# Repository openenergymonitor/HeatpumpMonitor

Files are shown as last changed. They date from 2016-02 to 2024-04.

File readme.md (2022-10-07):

# Heatpump Monitor

This is a technical github repository for OpenEnergyMonitor open hardware and software heat-pump performance monitoring development.

## Rationale

Heat-pumps are a key component of zero carbon energy systems making it possible to provide heating efficiently from renewable energy, they are featured in many zero carbon energy scenarios such as ZeroCarbonBritain developed by the Centre for Alternative Technology and are also highlighted in David MacKay's book Sustainable Energy without the hot air.

By monitoring a heat-pump its possible to see how well it is working, diagnose problems and get a better understanding of how a key potentially zero carbon heating solution works, data gathered and shared from well performing systems could help de-mystify heat-pump operation and help improve performance by diagnosing any problems early.

## Getting started

The heat pump monitoring application guide in the main OpenEnergyMonitor guide is a good place to start, covering the different options, including the use of the main OpenEnergyMonitor hardware:

[https://guide.openenergymonitor.org/applications/heatpump](https://guide.openenergymonitor.org/applications/heatpump)

## Hardware

### EmonPi or EmonTx based heat pump monitor

<table>
<tr><td>
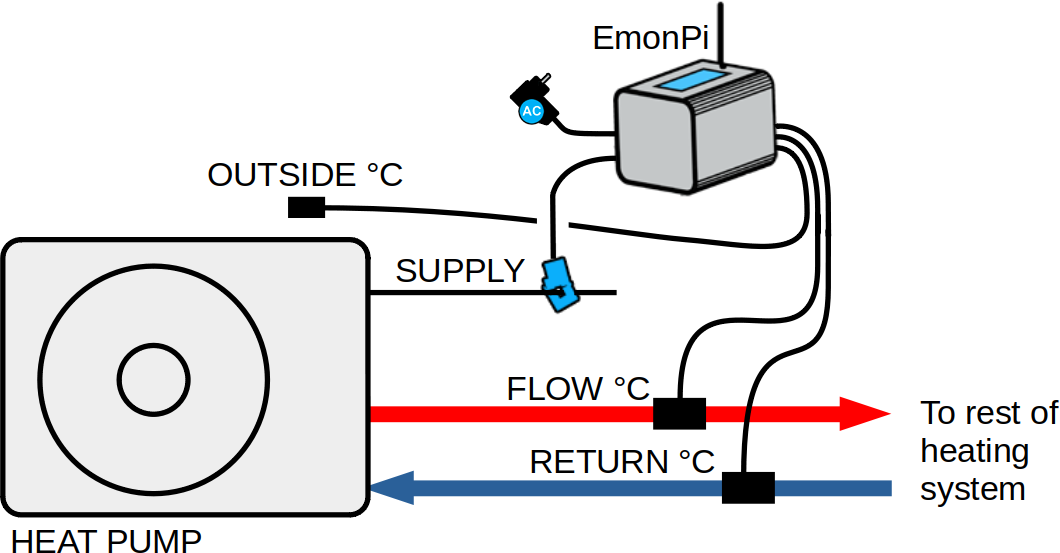
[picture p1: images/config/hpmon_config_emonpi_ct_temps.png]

</td><td>
<b>Electricity consumption and system temperatures</b><br>
<p>Monitor electricity consumption and system temperatures using clip-on CT sensors and one-wire temperature sensors connected to an emonPi or emonTx. This provides the simplest solution for installation on existing systems. See <a href="https://guide.openenergymonitor.org/applications/heatpump">main guide for details</a>.</p>
</td>
</tr>
<tr><td>
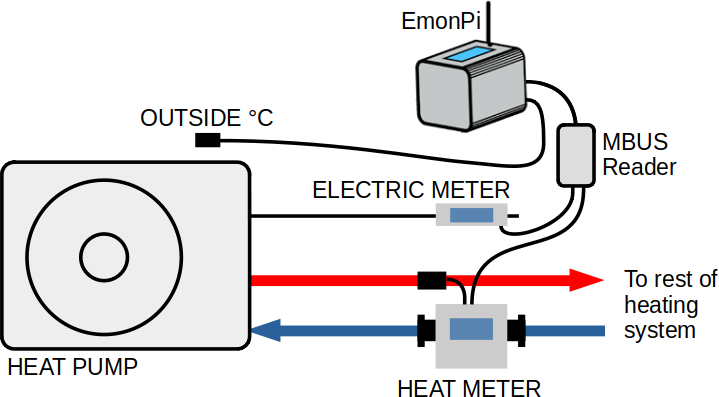
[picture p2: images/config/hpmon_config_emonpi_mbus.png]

</td><td>
<b>Using external MBUS reader module</b><br>
<p>An external MBUS reader connected to the emonPi or emonBase can be used to read from high accuracy electricity and heat meters. See <a href="https://guide.openenergymonitor.org/applications/heatpump">main guide for details</a>.</p>
</td>
</tr>
</table>

### [New: RaspberryPi & MBUS based heat pump monitor](HeatpumpMonitorPi)

<table>
<tr><td>
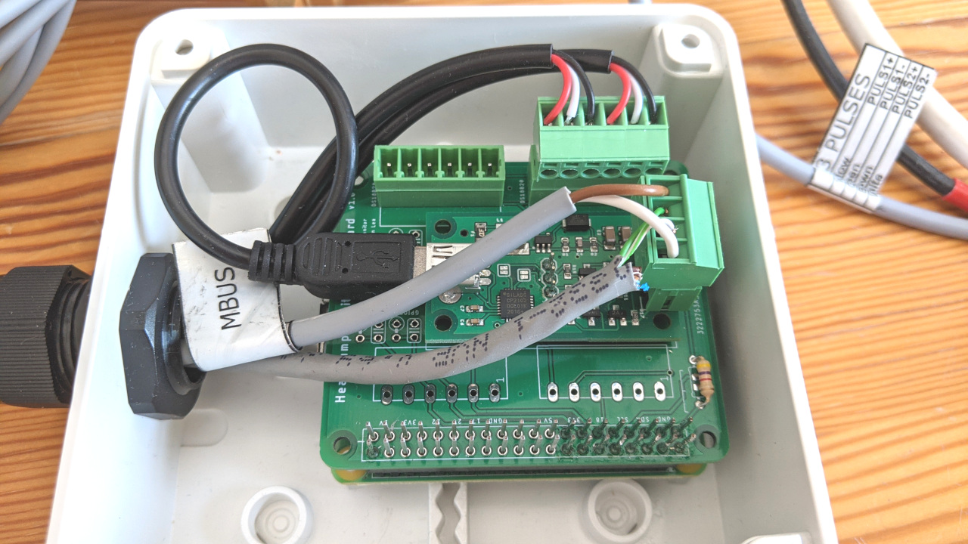
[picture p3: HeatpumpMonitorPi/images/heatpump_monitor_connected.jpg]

</td><td>
<p>This is a new heat pump monitor board designed specifically for interfacing with MID standard electricity and heat meters via MBUS. It has a RaspberryPi at it’s core running our emonSD image enabling local or/and remote logging and data visualisation.</p>
</td>
</tr>
</table>

### [Original through-hole heat pump monitor](HeatpumpMonitorTH)

<table>
<tr><td>
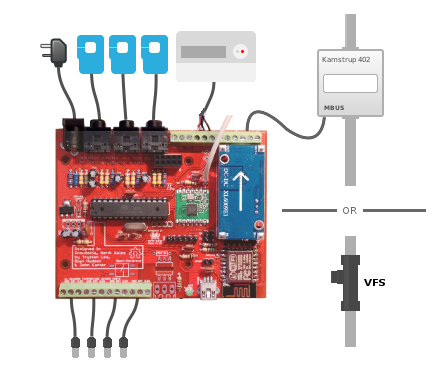
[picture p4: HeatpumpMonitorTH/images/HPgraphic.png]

</td><td>
<b>Main Features:</b><br>
<ul>
<li>CT current and ACAC voltage based electricity monitoring</li>
<li>Pulse counting or IRDA Elster meter reader</li>
<li>Analog inputs for Vortex Flow Sensor (VFS) option (e.g Sika, Grundfos)</li>
<li>MBUS reader for kamstrup heat meters (402, 403)</li>
<li>4x individually broken out DS18B20 temperature sensor connections</li>
<li>Arduino ATmega328 core</li>
<li>Connectivity options: ESP-12 WIFI, RaspberryPI header, RFM69</li>
</ul>
</td>
</tr>
</table>

### Mini Boards

**USB to MBUS**

- [USB to MBUS v1 SMT](https://github.com/openenergymonitor/HeatpumpMonitor/tree/master/USB_MBUS_Reader)

**WiFi MBUS Reader**

- [WiFi MBUS Reader v1 (Through-hole)](https://github.com/openenergymonitor/HeatpumpMonitor/tree/master/Hardware/WiFi_MBUS_Reader/v1_TH)
- [WiFi MBUS Reader v1 SMT](https://github.com/openenergymonitor/HeatpumpMonitor/tree/master/Hardware/WiFi_MBUS_Reader/v1)

## Heat pump monitoring dashboard

Emoncms includes an application specific heat pump dashboard available in the Apps module. The following video gives a good overview of what this dashboard can do, how to access daily electricity consumption and heat output data as well as detailed system temperature and power data.

There's also a little feature shown briefly at the end that simulates the heat output and COP of the heat pump based on the Carnot COP equation.

[YouTube: Introduction to the Emoncms heat pump dashboard](https://www.youtube.com/watch?v=jBY1Sx3LR2o)

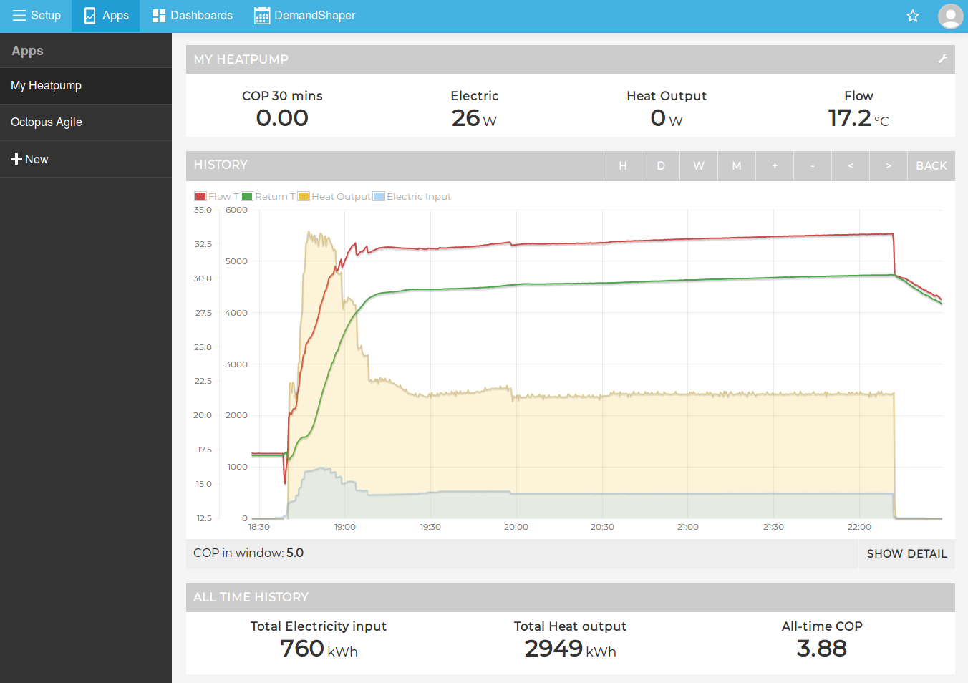
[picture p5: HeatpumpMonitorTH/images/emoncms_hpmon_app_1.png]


It's also worth checking out David Bowen (@MyForest on the forum's) heat pump app, see forum post: [Heat Pump Experimentation App - Release News](https://community.openenergymonitor.org/t/heat-pump-experimentation-app-release-news/13423).

The My Heatpump app includes a feature to simulate the COP and heat output of a heat pump from the flow temperature, outside temperature and electrical power input. The equations used are documented here: https://github.com/emoncms/dynamic/blob/master/docs/heatpumpmodel.md

## Blogs and further reading

- **Blog post:** [Heatpumps in the ZeroCarbonBritain model by the Centre for Alternative Technology.](https://blog.openenergymonitor.org/2015/12/heatpumps-in-zerocarbonbritain-model-by)
- **Blog post:** [Heat pump Testing: Initial results](https://blog.openenergymonitor.org/2016/02/heat-pump-testing-initial-results)
- **[John Cantor's heat pump monitoring blog](https://heatpumps.co.uk/technical/energy-monitoring)**

## Licence

This project is open source software and hardware.

The Arduino firmware is available under the GPL v3 Licence. 

The Web Dashboard is available under the GNU Affero General Public License and is based on emoncms.

The hardware design (schematics, board files and gerber) files are licensed under the [Creative Commons Attribution-ShareAlike 3.0 Unported License](http://creativecommons.org/licenses/by-sa/3.0/) and follow the terms of the [OSHW (Open-source hardware) Statement of Principles 1.0.](http://freedomdefined.org/OSHW)

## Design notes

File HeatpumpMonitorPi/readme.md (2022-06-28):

## RaspberryPi, MBUS & Modbus based heat pump monitor

This is a new heat pump monitor board designed specifically for interfacing with MID standard electricity and heat meters via MBUS or/and Modbus. It has a RaspberryPi at it’s core running our emonSD image enabling local or/and remote logging and data visualisation.

It is designed for monitoring heat pump electricity consumption, heat output and system temperatures for detailed performance analysis & troubleshooting.

### Features

- MBUS Reader (Reads from heat meters and some electric meters, though the SDM120-MBUS is no longer recommended)
- A Modbus Reader is recommended for reading from SDM120-Modbus electricity meters
- DS18B20 Temperature sensor connections
- 6 Digital input or outputs can be used for pulse counting
- I2C connection (uses 2 of the 6 digital IO's)
- RaspberryPi running the OpenEnergyMonitor emonSD image

This hardware design combines in a single unit a: 

- RaspberryPi
- [Heat pump monitoring baseboard](baseboard)
- [USB to MBUS reader](../USB_MBUS_Reader)

### Selecting a heat meter

Please read our guide on selecting the right heat meter here:<br>https://github.com/openenergymonitor/HeatpumpMonitor/blob/master/selectingheatmeter.md

### Connection diagram

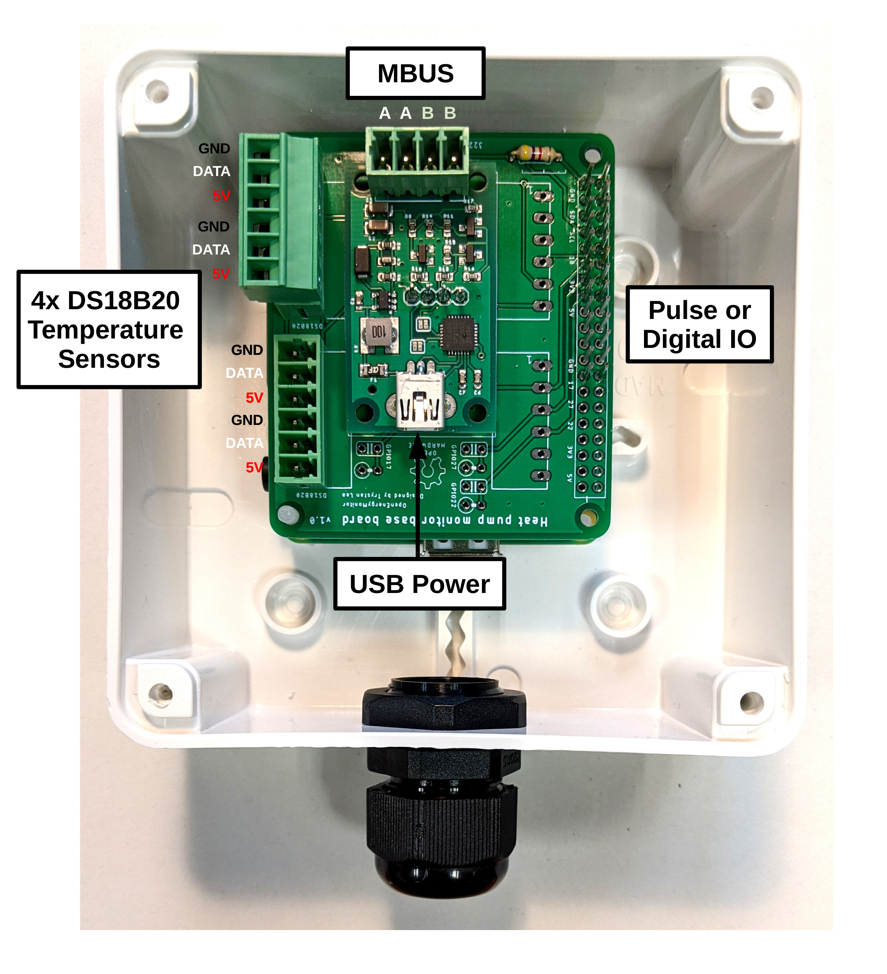
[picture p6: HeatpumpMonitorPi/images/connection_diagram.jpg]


### Setup

The following setup instructions assume an assembled heat pump monitor kit as shown in the picture above, with pre-prepared SD card running the standard emonSD image inserted into the RaspberryPi **(with SSH enabled, see [Guide: Credentials](https://guide.openenergymonitor.org/technical/credentials/))**.

1. Use the connection diagram above to connect MBUS meters, temperature sensors and power. There are two A and B MBUS terminals that can be used to simplify connecting two meters to the MBUS reader. Make sure that the power supply is capable of supplying 2A e.g [OpenEnergyMonitor Shop 5V USB Power Adapter](https://shop.openenergymonitor.com/5v-dc-usb-power-adapter-uk-plug) (MBUS data corruption can occur if the power supply output is too low).

2. Power up the unit, wait a couple of minutes for the Pi to create a WiFi access point. Connect to the access point and then use the WiFi configuration interface to connect the unit to your home WiFi. See [Guide: Connect](https://guide.openenergymonitor.org/setup/connect/) for full details.

3. If you have connected DS18B20 temperature sensors a couple of minor steps are required to enable reading from DS18B20 temperature sensors on the Pi. Follow steps 1 to 4 here [EmonHub Interfacers: Direct DS18B20 temperature sensing](https://guide.openenergymonitor.org/integrations/emonhub-interfacers/#direct-ds18b20-temperature-sensing).

4. EmonHub is piece of software running on the Pi that reads from the connected MBUS meters and DS18B20 temperature sensors. It then forwards the data to a seperate piece of software called Emoncms for data storage and visualisation. EmonHub is configured using a configuration file located at: /etc/emonhub/emonhub.conf. A configuration example is included at the bottom of this page for reading from a SDM120-MBUS electricity meter, a Qalcosonic E3 heat meter and DS18B20 temperature sensors. Overwrite the existing default configuration with this configuration as it is a better starting point for our requirements.

5. Configure EmonHub MBUS settings. The default MBUS configuration settings below assumes that a suitable heat meter is connected on address 1. You may need to adjust the MBUS address of either of the meters to ensure that they are not both on the same address. See instructions in the forum post here on how to do this: https://community.openenergymonitor.org/t/reading-from-multiple-mbus-meters-with-the-emonhub-mbus-interfacer/18159

6. Example configuration with a Sontex 531 heat meter:

```
[[MBUS]]
    Type = EmonHubMBUSInterfacer
    [[[init_settings]]]
        device = /dev/ttyAMA0
        baud = 2400
    [[[runtimesettings]]]
        pubchannels = ToEmonCMS,
        read_interval = 10
        validate_checksum = False
        nodename = mbus
        [[[[meters]]]]
            [[[[[sontex]]]]]
                address = 1
                type = sontex531
```

7. With the hardware connected up and the settings in place, data should now be coming in and be listed as inputs in Emoncms.

### Using the EmonHub log to debug issues reading data from the meters

...

### Configuring Emoncms

...

### Example test setup

Reading from a SDM120-MBUS electricity meter and a Qalcosonic E3 heat meter. These, or similar meters would usually be installed as part of heat pump installation. 

**Note:** The SDM120-MBUS electricity meter is no longer recommended due to reliability issues. We now recommend to use a SDM120-Modbus meter with a seperate Modbus reader. See forum post: [https://community.openenergymonitor.org/t/sdm120-mbus-meter-freezing-drop-out/20765/2](https://community.openenergymonitor.org/t/sdm120-mbus-meter-freezing-drop-out/20765/2)

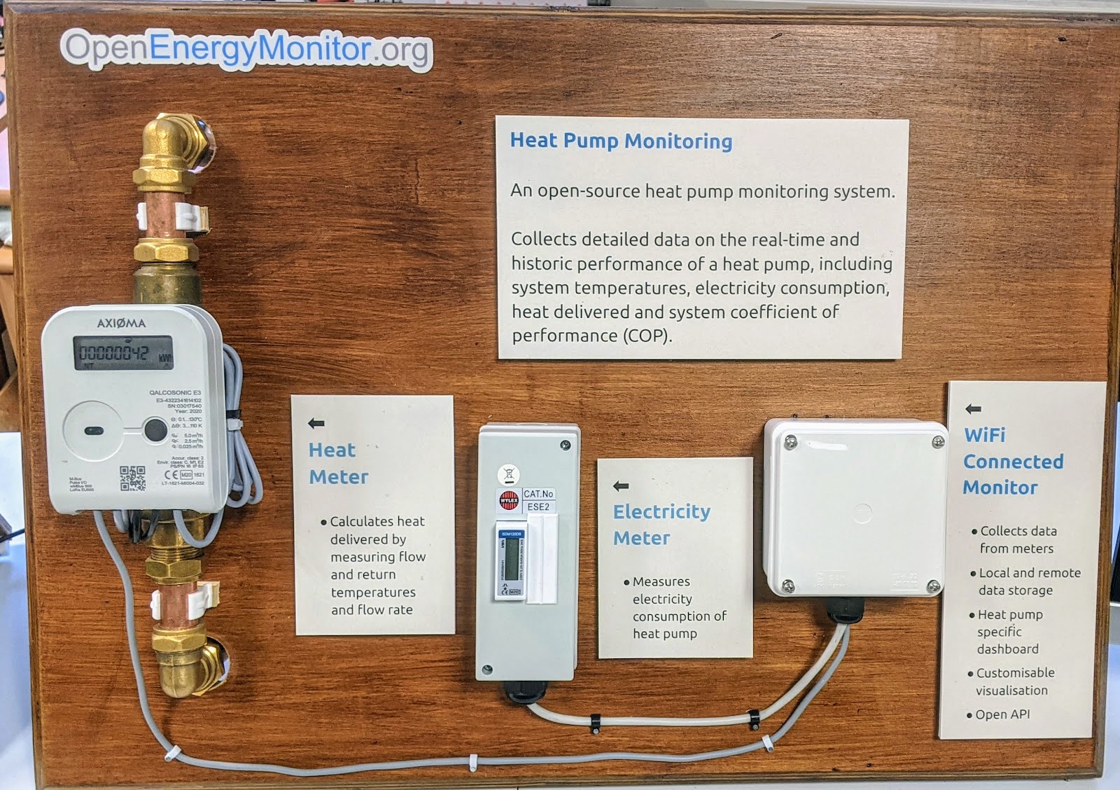
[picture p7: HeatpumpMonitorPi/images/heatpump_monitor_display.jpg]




### Example EmonHub Configuration

The following is a full */etc/emonhub/emonhub.conf* example that reads from any connected DS18B20 temperature sensors, a Sontex Superstatic 440 heat meter with Multical 531 integrator on MBUS and a SDM120-Modbus electricity meter. Data is forwarded to the local emoncms installation using MQTT and the remote emoncms installation via HTTP.

```
[hub]
loglevel = DEBUG

[interfacers]

[[DS18B20]]
    Type = EmonHubDS18B20Interfacer
    [[[init_settings]]]
    [[[runtimesettings]]]
        pubchannels = ToEmonCMS,
        read_interval = 10
        nodename = temperatures

[[MBUS]]
    Type = EmonHubMBUSInterfacer
    [[[init_settings]]]
        device = /dev/ttyAMA0
        baud = 2400
    [[[runtimesettings]]]
        pubchannels = ToEmonCMS,
        read_interval = 10
        validate_checksum = False
        nodename = mbus
        [[[[meters]]]]
            [[[[[sontex]]]]]
                address = 1
                type = sontex531

[[SDM120]]
    Type = EmonHubSDM120Interfacer
    [[[init_settings]]]
        device = /dev/ttyUSB0
        baud = 2400
    [[[runtimesettings]]]
        pubchannels = ToEmonCMS,
        read_interval = 10
        nodename = SDM120

[[MQTT]]
    Type = EmonHubMqttInterfacer
    [[[init_settings]]]
        mqtt_host = 127.0.0.1
        mqtt_port = 1883
        mqtt_user = emonpi
        mqtt_passwd = emonpimqtt2016

    [[[runtimesettings]]]
        pubchannels = ToRFM12,
        subchannels = ToEmonCMS,
        nodevar_format_enable = 1
        nodevar_format_basetopic = emon/

[[emoncmsorg]]
    Type = EmonHubEmoncmsHTTPInterfacer
    [[[init_settings]]]
    [[[runtimesettings]]]
        pubchannels = ToRFM12,
        subchannels = ToEmonCMS,
        url = https://emoncms.org
        apikey = xxxxxxxxxxxxxxxxxxxxxxxxxxxxxxxx
        senddata = 1
        sendstatus = 1
        sendinterval= 30

[nodes]
```

**Forum post: Reading from multiple MBUS meters with the EmonHub MBUS interfacer**<br>
https://community.openenergymonitor.org/t/reading-from-multiple-mbus-meters-with-the-emonhub-mbus-interfacer/18159

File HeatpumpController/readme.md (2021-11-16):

# Heatpump Controller v1

An initial board design for a heat pump controller, designed for use with a Mitsubishi EcoDan with a FTC2b controller.

This board sits on top of a RaspberryPi and the very basic at this stage python scripting that runs on it can be found here: https://github.com/TrystanLea/heatpump_control

**Features:**

- 6x solid state relay outputs either PVT312, PVT412 or LH1546. Most of these are used to switch the volts free inputs on the FTC2b, e.g heating on, DHW mode etc.
- The PVT412 can drive up to 120mA AC which is 27.6W, can directly control a couple of AC low power solenoids/valves.
- 4x DS18B20 temperature sensor connections for cylinder and outside temperature sensors
- 0-5V voltage output to set EcoDan flow temperature
- A connection for the MBUS reader module here [USB_to_MBUS](https://github.com/openenergymonitor/HeatpumpMonitor/tree/master/Hardware/USB_to_MBUS) to read from heat meters. Later version could integrate this on the board.
- The Pi can connect via an modbus reader to a SDM120 single phase electricity meter, see [OEM Guide](https://guide.openenergymonitor.org/integrations/emonhub-interfacers/#reading-from-a-sdm120-single-phase-meter)

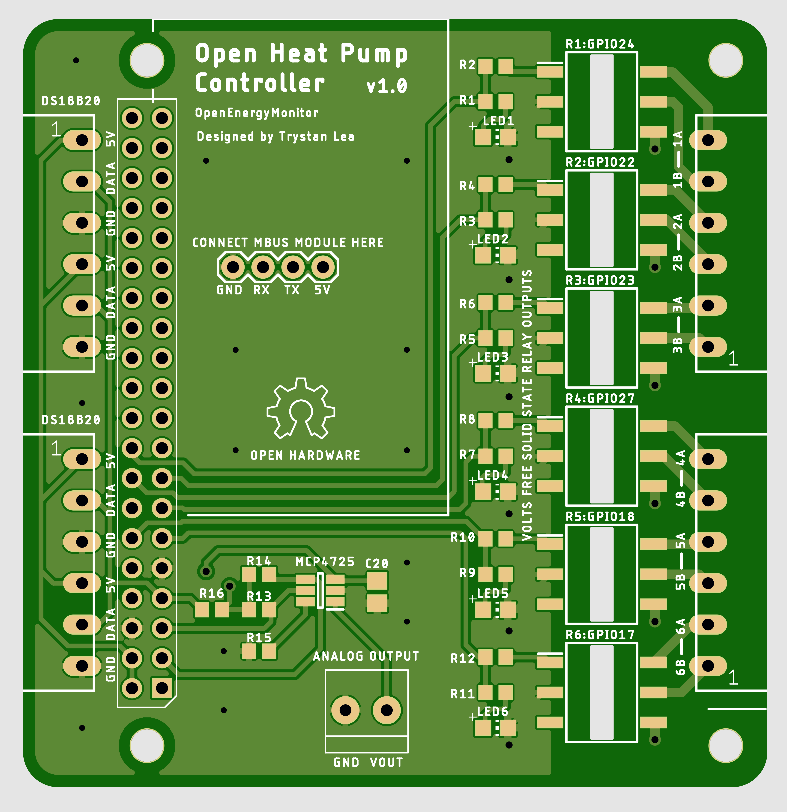
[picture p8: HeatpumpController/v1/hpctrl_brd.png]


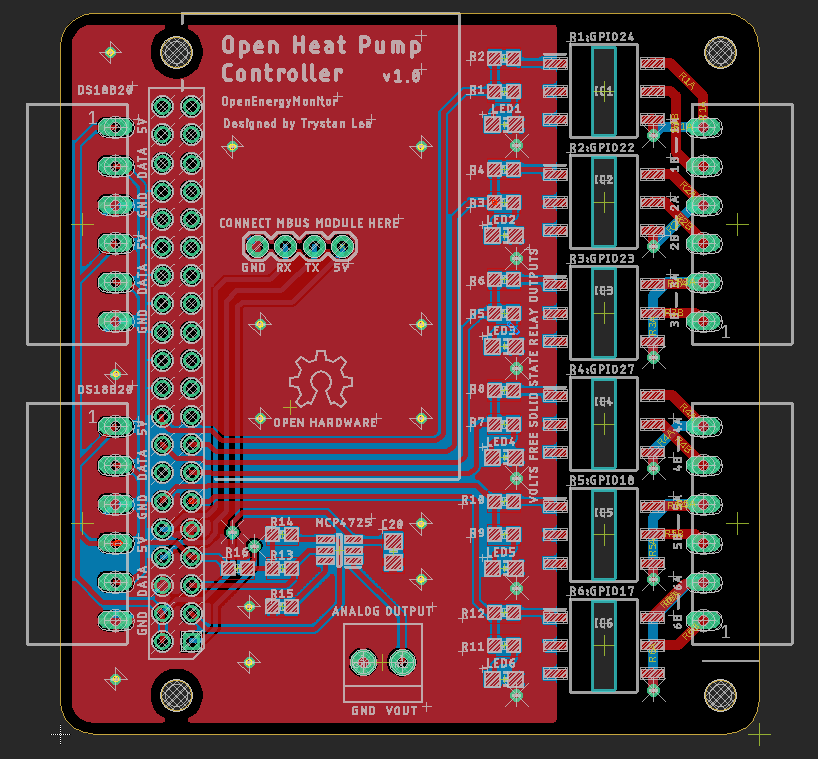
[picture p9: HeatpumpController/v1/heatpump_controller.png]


## Alternative approach (better?)

It looks like it is possible to issue commands directly via the CN105 connector on most Mitsubushi EcoDan controllers, which looks like a better and much cheaper approach than the above. Will be trying this myself soon:

- https://github.com/SwiCago/HeatPump
- https://www.geekzone.co.nz/forums.asp?forumid=73&topicid=265469
- https://web.archive.org/web/20171007190023/https://nicegear.co.nz/blog/hacking-a-mitsubishi-heat-pump-air-conditioner/
- https://gitter.im/Mitsubishi-CN105-Protocol-Decode/community
- https://github.com/m000c400/Mitsubishi-CN105-Protocol-Decode
- https://github.com/BartGijsbers/CN105Gateway
- https://www.zakon.org/robert/projects/MiniSplitPi/

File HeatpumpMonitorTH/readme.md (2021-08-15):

# The Original Through-hole Heatpump Monitor

This directory contains all the documentation, hardware schematics, board files and firmware for the original OpenEnergyMonitor through-hole heat pump monitor, developed between 2015-2017.

This is a web-connected open source hardware heat-pump monitor that can measure heat-pump electrical input with CT sensors, heat output with an MBUS reader or voltage output flow sensor and system temperatures using DS18B20 temperature sensors. The design is based on both the Ardunio and ESP8266 WiFi platforms.

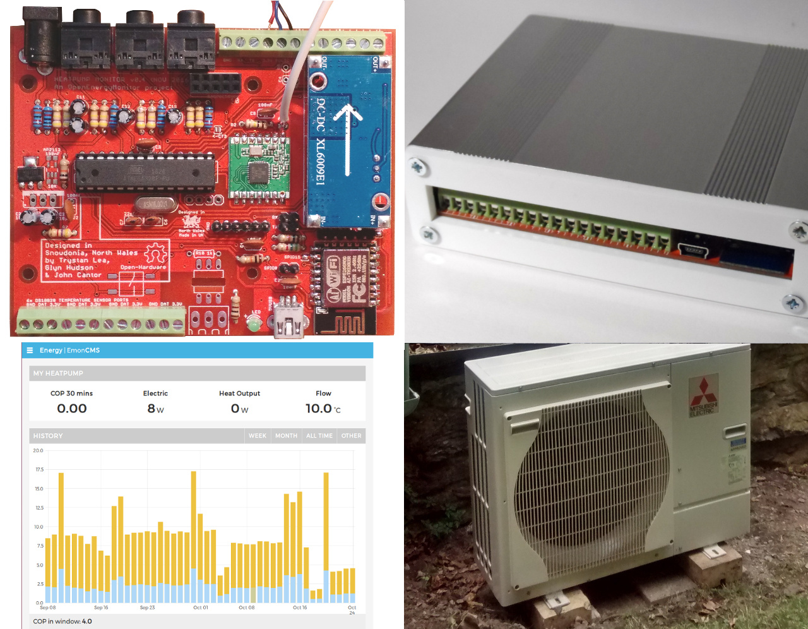
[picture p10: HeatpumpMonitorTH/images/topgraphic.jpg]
Heatpump monitor


Blog post written late 2015 discussing this design: [Heat pump Monitoring](https://blog.openenergymonitor.org/2015/12/heat-pump-monitoring)

## Available in the OpenEnergyMonitor Shop

The last set of through-hole kits are still available in our shop as of the time of writting (late 2021).

[https://shop.openenergymonitor.com/esp8266-wifi-heatpump-monitor](https://shop.openenergymonitor.com/esp8266-wifi-heatpump-monitor)

## Overview

<table>
<tr><td>

</td><td>
<b>Main Features:</b><br>
<ul>
<li>CT current and ACAC voltage based electricity monitoring</li>
<li>Pulse counting or IRDA Elster meter reader</li>
<li>Analog inputs for Vortex Flow Sensor (VFS) option (e.g Sika, Grundfos)</li>
<li>MBUS reader for kamstrup heat meters (402, 403)</li>
<li>4x individually broken out DS18B20 temperature sensor connections</li>
<li>Arduino ATmega328 core</li>
<li>Connectivity options: ESP-12 WIFI, RaspberryPI header, RFM69</li>
</ul>
</td>
</tr>
</table>

## Build Guides

There are two build options for the heatpump monitor board, the first is the full heatpump monitor build with components for the MBUS heat meter reader, DS18B20 temperature sensing plus other interfaces. The second is a cut-down WIFI electricity monitor only build where the additional components for heat metering are not soldered in.

- [Heatpump monitor kit build guide](heatpumpmonitor_build.md)
- [Cut down energy monitor kit build guide](energymonitor_build.md)

**Quick reference**

- [ATmega328 Arduino Firmware: HeatpumpMonitor_AutoTemp](https://github.com/openenergymonitor/HeatpumpMonitor/blob/master/HeatpumpMonitorTH/Firmware/Arduino/HeatpumpMonitor_AutoTemp)
- [ESP8266 EmonESP WIFI Firmware](https://github.com/openenergymonitor/EmonESP)
- [Hardware Schematic and Board files v4](https://github.com/openenergymonitor/HeatpumpMonitor/tree/master/HeatpumpMonitorTH/Hardware/v4)

## Installation and setup

The following guide details how to setup the heatpump monitor including interfacting with an Elster A100C Irda port and connecting up to a heat meter.

- [Selecting the right heat meter](../selectingheatmeter.md)
- [Installation and setup](installation.md)
- [Blog: Temperature sensors for monitoring heat pumps](http://johncantorheatpumps.blogspot.co.uk/2015/06/temperature-sensing-with.html)
- [Firmware Upload / Update](firmware-upload.md)

## Open Hardware ++

A case study in open hardware development

- Exporting gerbers from EAGLE, getting a PCB made with a PCB manufacturer such as Ragworm
- [Heatpump Monitor and cut down energy monitor kit costing](costingexample.md)

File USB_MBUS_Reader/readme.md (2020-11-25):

# USB to MBUS

A simple USB MBUS reader with on-board boost converter and CP2102 USB to UART chip. Designed for reading data from heat pump heat meters and interfacing directly with a RaspberryPi via a USB cable.

**Features**

- MBUS Reader circuit (original circuit by [Tomas Menzi](https://github.com/rscada/libmbus/tree/master/hardware))
- On-board boost converter (based on [Taaralabs](https://taaralabs.eu/m-bus-uart-converter/))
- CP2102 USB to UART chip

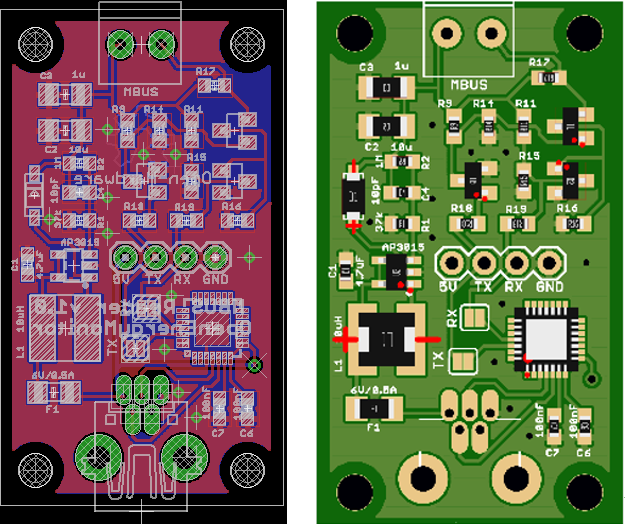
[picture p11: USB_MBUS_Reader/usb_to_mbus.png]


**Software**

The board can be used with the EmonHub MBUS Interfacer. This interfacer is designed to look for specific useful parameters for electric and heat metering (It does not implement the full MBUS spec). It will typically return flow and return temperatures, flow rate, heat output, and cumulative heat energy for heat meters that support these parameters.

https://guide.openenergymonitor.org/integrations/emonhub-interfacers/#mbus-reader-for-electric-and-heat-meters

## Schematic

[USB_to_MBUS.sch](USB_to_MBUS.sch)

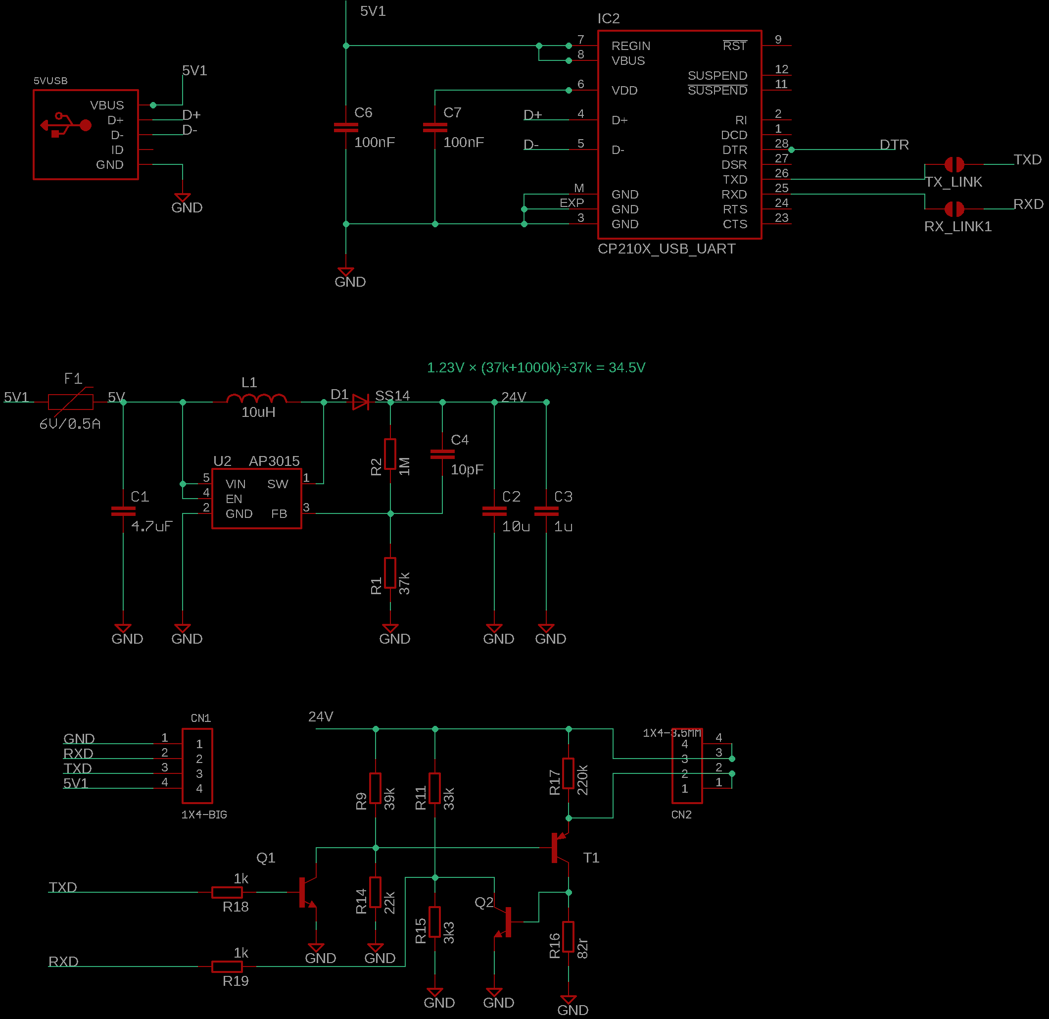
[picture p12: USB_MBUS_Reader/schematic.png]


## Board

[USB_to_MBUS.brd](USB_to_MBUS.brd)

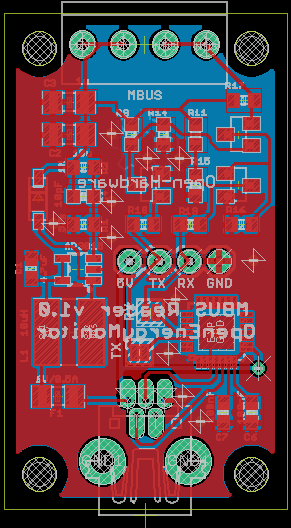
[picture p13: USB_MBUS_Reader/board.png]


The hardware design (schematics, board files and gerber) files are licensed under the [Creative Commons Attribution-ShareAlike 3.0 Unported License](http://creativecommons.org/licenses/by-sa/3.0/) and follow the terms of the [OSHW (Open-source hardware) Statement of Principles 1.0.](http://freedomdefined.org/OSHW)

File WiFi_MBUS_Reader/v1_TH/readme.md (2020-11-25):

# WiFi MBUS Reader Through-Hole

A simple MBUS reader development board with optional WiFi based on ESP8266. Designed for reading data from heat pump heat meters and either interfacing directly with a RaspberryPi via UART or via WiFi if the ESP8266 is soldered on.

This board is a through-hole version of WiFi_MBUS_Reader/v1 for easier hand assembly and initial development testing.

**Features**

- MBUS Reader circuit, requires external boost converter
- MBUS to UART mode without ESP8266 attached.
- MBUS to WiFi mode with ESP8266 attached.
- With ESP8266: Pulse counting & potentially reading from Elster A100c IrDa output
- With ESP8266: DS18B20 temperature sensing 

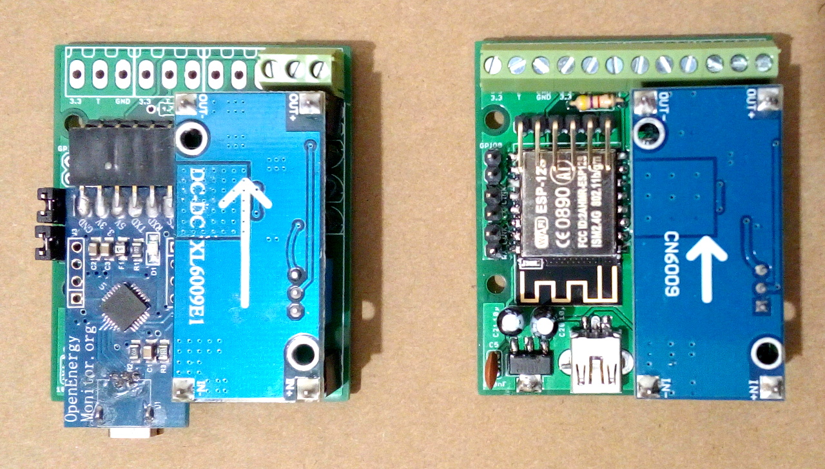
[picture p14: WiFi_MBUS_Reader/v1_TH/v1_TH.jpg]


**Software**

If used in **MBUS to UART mode**, the board can be used with the EmonHub MBUS Interfacer. This interfacer is designed to look for specific useful parameters for electric and heat metering (It does not implement the full MBUS spec). It will typically return flow and return temperatures, flow rate, heat output, and cumulative heat energy for heat meters that support these parameters.

https://guide.openenergymonitor.org/integrations/emonhub-interfacers/#mbus-reader-for-electric-and-heat-meters

The software for the **MBUS to WiFi mode** has not been written in full yet. A basic MBUS Reader firmware tested to work on this board is available here for anyone keen to get stuck in before I get this done: https://github.com/openenergymonitor/HeatpumpMonitor/tree/master/Firmware/Arduino/MBUS_Reader_ESP 

## Schematic

[v1_TH.brd](v1_TH.brd)

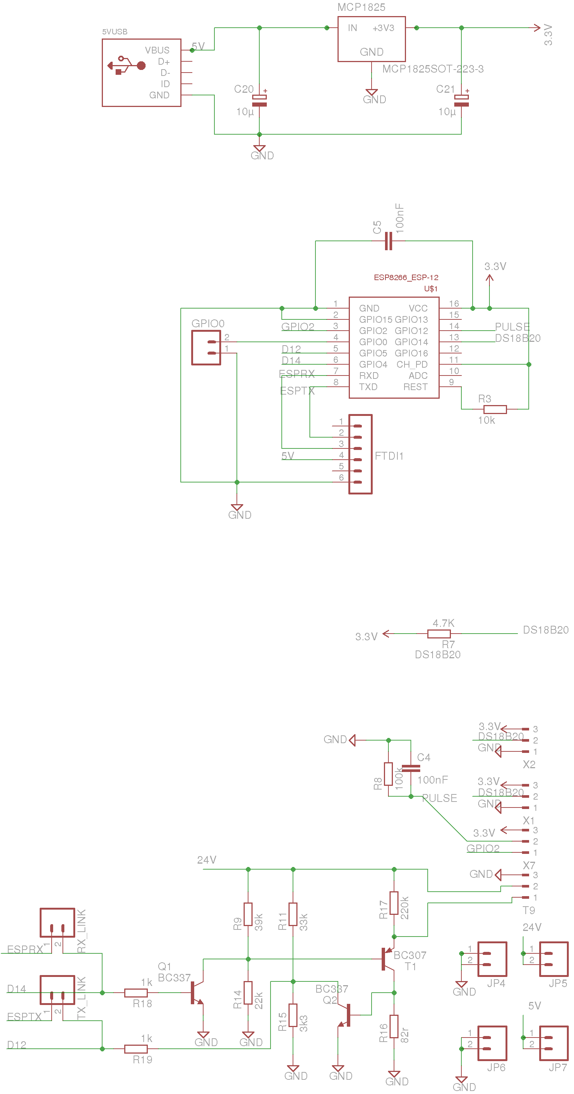
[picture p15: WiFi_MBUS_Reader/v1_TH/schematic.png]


## Board

[v1_TH.sch](v1_TH.sch)

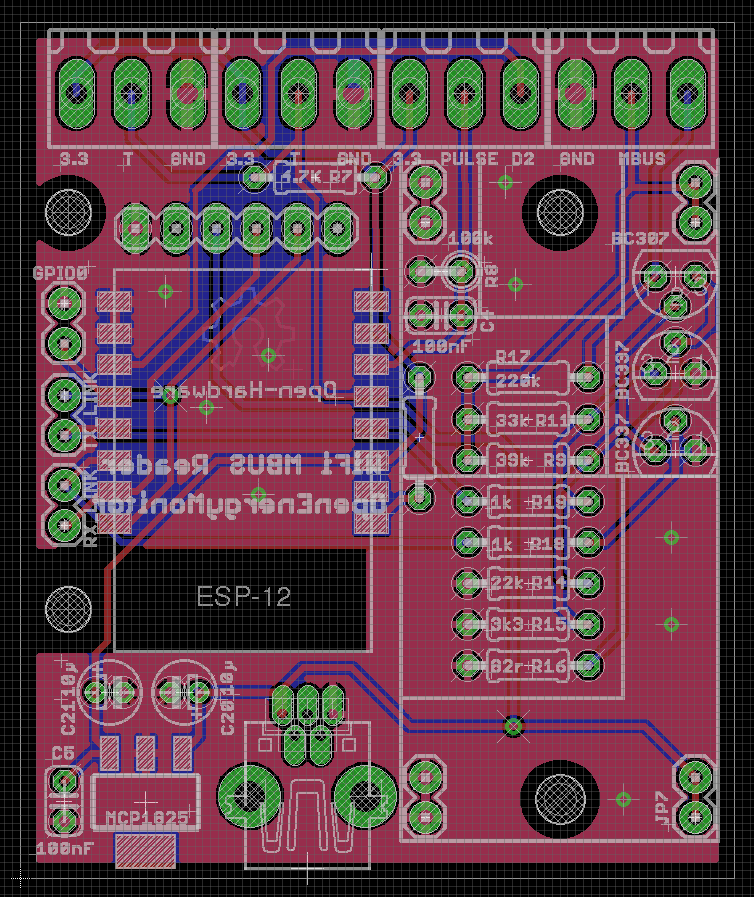
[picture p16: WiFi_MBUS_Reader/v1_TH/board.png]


The hardware design (schematics, board files and gerber) files are licensed under the [Creative Commons Attribution-ShareAlike 3.0 Unported License](http://creativecommons.org/licenses/by-sa/3.0/) and follow the terms of the [OSHW (Open-source hardware) Statement of Principles 1.0.](http://freedomdefined.org/OSHW)

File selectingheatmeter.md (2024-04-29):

# Selecting the right heat meter

There are a number of different heat meter brands and models available that are both MID and RHI (UK Renewable Heat Incentive) approved. If you are in the UK, Stockshed provide a good range of these meters: [https://stockshed.com/pages/heat-meters-stockshed-uk](https://stockshed.com/pages/heat-meters-stockshed-uk).

Most heat meters include an MBUS interface that can be used for reading the metering data. This usually includes, total heat delivered in kWh, real-time heating power in Watts, flow and return temperatures and flow rate in L/min of m3/hr. 

Using an MBUS reader connected to an emonPi, emonBase or just a Raspberry Pi, it is possible to read in this data and then store and visualise it using emoncms. Combined with electricity data, this can provide a data rich, detailed view of the performance of a heat pump.

So far, we have only tested our MBUS reader software with a subset of the following meters but they should all be compatible, if not out of the box, with a little modification of the code. Please email me at trystanlea @ openenergymonitor.org if you are having trouble reading from a particular MBUS meter.

**Important:** We recommend using meter's with an AC power supply option as most battery powered options are not designed for requesting MBUS data at 10s frequency and so battery life may be much shorter than otherwise advertised. 

### [Kamstrup MULTICAL 403](https://www.kamstrup.com/en-en/heat-solutions/meters-devices/meters/multical-403)

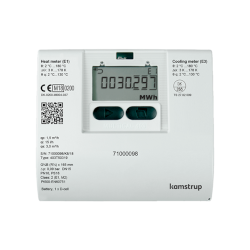
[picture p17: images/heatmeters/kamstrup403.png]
<table><tr><td></td><td>

- Tested at OpenEnergyMonitor: Yes
- Class 2, MID approved
- Ultrasonic
- Not compatible with glycol (to our knowledge)
- Power supply: Mains AC and battery powered options
- [Technical description pdf](https://documentation.kamstrup.com/docs/MULTICAL_403/en-GB/Data_sheet/CONT0B6D945665A843D6A9B8B14FC05A203B/) does suggest long battery lifetimes with wired M-Bus at 10s data rates - "By using M-Bus, the meter obtains a battery lifetime of up to 16 years with meter readings via the module every 10 seconds."
- Flow measurement cycle: 1s (fast), 4s (normal), 1-4s (adaptive)
- Temperature measurement cycle: 4s (fast), 32s (normal), 4-64s (adaptive, appears to be default)
- Standard configuration from stockshed is heating only, heating and cooling configuration is available.
        
</td></tr></table>
        
### Sontex Superstatic 440

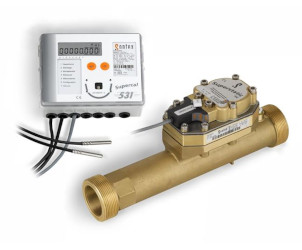
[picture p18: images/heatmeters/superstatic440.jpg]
<table><tr><td></td><td>

- Tested at OpenEnergyMonitor: Yes
- Class 2, MID approved
- Fluid oscillator, piezo electric
- **Glycol calibration available**
- Power supply: **Mains AC** and battery powered options. AC power is recommended for high resolution 10s data. (M-Bus is not self-powered)
- Flow measurement cycle: continuous
- Temperature measurement cycle: 3s (mains), 20s (d-cell battery), 30s (c-cell battery)

</td></tr></table>

### Diehl Metering Sharky 775

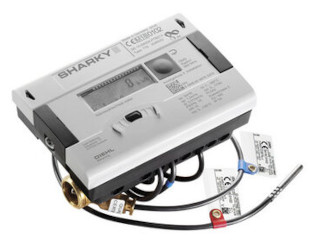
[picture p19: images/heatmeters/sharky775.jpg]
<table><tr><td></td><td>

- Tested at OpenEnergyMonitor: Yes, see [forum post](https://community.openenergymonitor.org/t/newbie-hardware-question/16242/31) 
- Class 2, MID approved
- Ultrasonic
- Not compatible with glycol (to our knowledge)
- Power supply: **Mains AC** and battery powered options. AC power is recommended for high resolution 10s data
- Flow measurement cycle: 1/8 s (mains), 1s (battery)
- Temperature measurement cycle: 2s (mains), 4s (d-cell battery), 15s (a-cell battery)
- Max MBUS read interval: A-cell: 3 minutes, D-cell: 1 minute?, Mains supply: unlimited
        
</td></tr></table>

### Axioma Qalcosonic E3

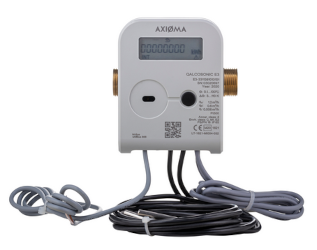
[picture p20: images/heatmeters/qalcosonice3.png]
<table><tr><td></td><td>

- Tested at OpenEnergyMonitor: Yes, for Richard Boyd at [You Generate](https://www.yougenerate.co.uk/)
- Class 2, MID approved
- Ultrasonic
- Not compatible with glycol (to our knowledge)
- Power supply: **Mains AC** and battery powered options. AC power is recommended for high resolution 10s data
- Flow measurement cycle: 1s (0.125s test mode)
- Temperature measurement cycle: 10s (1s test mode)    
        
</td></tr></table>
    
### Sontex Superstatic 749

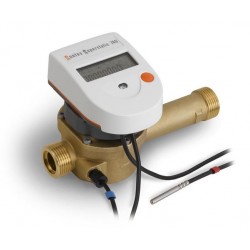
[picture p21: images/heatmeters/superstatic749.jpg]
<table><tr><td></td><td>

- Tested at OpenEnergyMonitor: No
- Class 2, MID approved
- Fluid oscillator, piezo electric
- **Glycol calibration available**
- Power supply: Battery powered (6 or 12 year battery life options). The M-Bus version is powered via the M-Bus line meaning high resolution 10s data does not impact the battery
- Flow measurement cycle: continuous
- Temperature measurement cycle: 10s
        
_(The Superstatic 789 is a slightly cheaper version of the 749 with a plastic body)_

</td></tr></table>

### Kamstrup multical 302

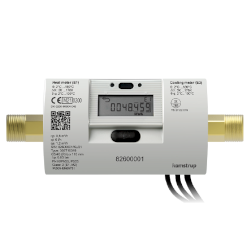
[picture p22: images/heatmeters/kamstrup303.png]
<table><tr><td></td><td>

- Tested at OpenEnergyMonitor: No
- Class 2, MID approved
- Ultrasonic
- Not compatible with glycol (to our knowledge)
- Power supply: Battery powered only, 6 or 12 year battery life options
- Flow measurement cycle: 1s (fast), 4s (normal), 1-4s (adaptive)
- Temperature measurement cycle: 4s (fast), 32s (normal), 4-64s (adaptive)
        
</td></tr></table>

---

# Heat meter pressure loss

Written by John Cantor, see [original blog post](https://heatpumps.co.uk/2016/06/08/selecting-the-right-heat-meter)

This topic is **VERY IMPORTANT**

I am aware that the pressure requirements of heat meters is often overlooked - this can be detrimental to a heat pump system.

A heat pump will normally be connected to a radiator or underfloor heat-emitter circuit.  A circulation pump (circulator) is required to ‘force’ the water around this circuit.  Each part of the pipework and each components acts as a restriction to flow. The greater the restriction, the bigger the circulation pump needed.  Indeed, many systems have 2 or more circulators, whilst it should be possible to only have one.

Heat meters  (reading heat in Kw’s) are often required to calculate RHI payments. The main component of a heat meter is a device fitted in a pipe to measure the liquid flowrate through the system. This device will cause a restriction to flow. However, it would be ridiculous for our heat-measuring device to impair energy-efficiency by either causing an inadequate liquid flow-rate, or by increasing circulation pump energy demand.

Let us get a ‘feel’ of the pressures involved. Metres head (height) of water is a good understandable unit of pressure measurement, but several other units are used;

    1 bar pressure (about 1 atmosphere)  = 10.2m head of water = 1,000mB = 100kPa

Most common circulation pumps can produce a maximum of 5 or 6 metres water head  (0.5 to 0.6 bar), however, this is at the pump’s low flow-rate.  For energy-efficient operation, we should operate them at mid-pressure range, ideally no more than a pressure of 2.5m head of water to work against.
Some heat pumps have one circulator to circulate through the heat pump and the emitters.  If the heat pump requires say 1m water head for its required flow-rate, and the emitter circuit requires a further 1m head, then the circulation pump needs to exert a total pressure of 2m head. There is little pressure left  to overcome restrictions for a the heat meter, so the heat meter should not be too restrictive.    Even if your system has 2 circulators, the head meter should not cause a significant restriction so you must SELECT THE CORRECT METER.

At their rated flow-rate, some  heat meters will require high pressure for circulation. Some cheaper options can require up to 2.5m head pressure. This is a lot.   However, if a larger heat meter is chosen, its pressure drop can be very low since, for example,  if you halve the flow-rate, you quarter the pressure requirements. Modern meters can retain high accuracy even at very low flow rates. E.g. if your system flow is 1 cubic m / hour, your best low-pressure option might be to fit a 2.5 cubic m/hr device.

The example chart  below show how the pressure drop can be very low if the meter is used at a flow-rate well below its maximum.   Note also that some meters are inherently more ‘restrictive’ than others.   The colours are my own opinion, and relate to adding a heat meter to a heat pump system.

*Chart updated 13 September 2021 to include more heat meters*

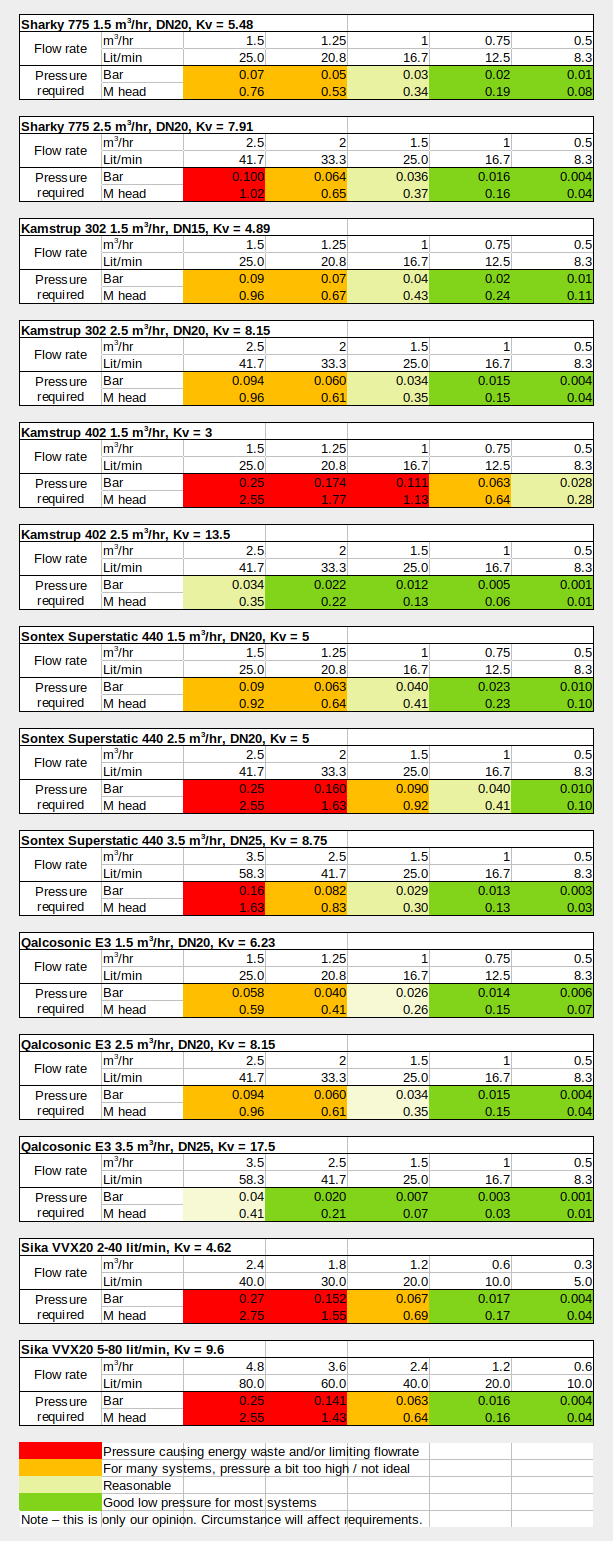
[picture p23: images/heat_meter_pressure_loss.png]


The Vortex Flow Sensors have exactly the same issue, and there are fewer pressure ranges to choose from.  However, in the region of 25% of their rated capacity, the pressure drop is usually nice and low.

The message here is – Don’t fit a meter without assessing the pressure drop at your expected flow rate.  Don’t necessarily trust the meter supplier since they don’t all understand the energy loss implications related to heat pumps, and may want to sell you the cheapest option. It could be perfectly acceptable using a high/medium pressure drop heat meter on a biomass district heating system feeding radiators, but for heat pump applications, we could be running into trouble unless the pressure drop is low.

**Calculating pressure drop at different flow rates**

Using the simple K value method the pressure drop in bar at any given flow rate can be estimated with the following equation:

    Pressure drop = (flow rate / Kv)^2
    
K values can ususally be obtained from the meter's datasheet. If the K value is not given but a nominal flow rate and pressure drop is present, the K-value can be calculated by re-arranging the above equation:

    Kv = nominal flow rate / sqrt(pressure drop)
    
The spread sheet used to generate the above pressure loss table can be downloaded here: [heat_meter_pressure_drops.ods](images/heat_meter_pressure_drops.ods)

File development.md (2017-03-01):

# Development

The heatpump monitor hardware is now in its fourth revision. 

Version 4 included a small revision adding a SMT push switch footprint to the board.

Version 3 changed the voltage regulator to a high current option.

Version 2 replaced the EmonGLCD footprint with a solid state relay and fixed a couple of issues with the first board. 

There are several aspects that would be good to develop further (discussed below) but the heatpump monitor in its present form is a good starting point providing a relatively low cost web-connected WIFI heatpump monitor development board that can interface with Elster A100C Irda electricity monitoring, Kamstrup MBUS heat meters and SIKA flow meters.

One of the main questions for the next stage of the heatpump monitor is whether the core features of the heatpump monitor can be integrated in a redesign of the pre-assembled SMT EmonTx v3 including the ESP8266 WIFI module. It would make more sense from a manufacturing perspective to be able to focus around a single unit. 

Another key development will be to increase the accuracy of the CT based electricity monitoring. Accurate electricity energy measurement is currently achieved by interfacing with an Elster A100C Irda port to read the cumulative watt hour reading.

**V2:**

- New: Footprint for small solid state relay for volts free heating system control - not tested yet.
- New: Status LED
- VFS requires 5V power supply, current terminals break out 3.3V, V2 revision has 5V routed instead.
- Increased thickness of the 3.3V supply lines to the ESP12 Wifi. There is now an additional 100nf cap across esp supply too
- RaspberryPi model B Ethernet port position adjusted
- Pulse counting dropdown resistor footprint on the board
- CT3 can now be selected seperatly from analog 3

BOM and example prototype costing: [BOM&Costing_oneoff_prototype.md](https://github.com/openenergymonitor/HeatpumpMonitor/blob/master/Hardware/v2/BOM&Costing_oneoff_prototype.md)

**Known Issues**

- There is still an issue with the ESP Wifi upload reset

**Further development:**

- Test and document use of SIKA flow meters
- Establish reliability of WIFI Connectivity

- Higher accuracy CT based electricity monitoring either with special purpose IC or high resolution ADC.
- Battery backed memory for kWh values
- Real time clock
- SD card for local data logging
- Modbus or other electricity meter reader
- Wiring up can currently be a little fiddly, a custom enclosure design could make installation and debugging easier.

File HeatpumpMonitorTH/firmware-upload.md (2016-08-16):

## ESP Firmware Upload 

HP monitors runs [EmonESP WiFi Emoncms link firmware](https://github.com/openenergymonitor/EmonESP)

- Ensure Tx jumper is open (not connected)
- Close GPIO0 jumper (required to enter bootloder mode)
- Power cycle the board by un-plugging then plugging in mini-usb 5V DC power 
- Upload via UART closest to ESP @ 115200 baud 
- See [EmonESP readme](https://github.com/openenergymonitor/EmonESP) for PlatformIO or ArduinoIDE instructions
- Remove GPIO0 and power cycle

## ATmega328 Fimrware Upload 

- Ensure Rx and Tx jumpers are open (removed)
- Upload via UART closest to ATmega328

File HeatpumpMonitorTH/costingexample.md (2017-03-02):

## Example costing for Heatpump Monitor and cut-down Energy Monitor kit

### One off prototype

The following outlines example one-off or low volume cost price costing for the Heatpump Monitor. 

**Total £53.48 ex VAT** including **£28.93 ex VAT** prototype one-off PCB from [Ragworm](http://ragworm.eu) (100mm x 80mm PCB standard pricing in one-off - £34.72 inc VAT). Total £65.38 including VAT (20%) + misc shipping costs to do one-off prototype/DIY.

See [HeatpumpMonitor/BOM&Costing_1x.ods](files/heatpumpmonitor/BOM&Costing_1x.ods) 

### 20x batch

A batch of 20x heatpump monitor boards start to give significant savings on the PCB cost and a couple of the other components, the cost price drops to £29.93 ex VAT in these quantities. 

See [HeatpumpMonitor/BOM&Costing_20x.ods](files/heatpumpmonitor/BOM&Costing_20x.ods) 

### Custom OEM

Some of the components in the heatpump monitor are shared with other OpenEnergyMonitor units. Because we order these in much larger quantities we are able to get a lower price on some items. This drops the cost price to £28.88 ex VAT.

The cost price of the heatpump monitor would be less if the PCB was ordered in larger quantities. Ordering in 50x would reduce the cost price by about £1.56, ordering in several hundred would reduce the cost price further.

### Sale price

Following the advice of other open hardware projects the sale price we typically charge is around 2.0-2.3x the cost price for OpenEnergyMonitor's main products. There's a good series of articles on pricing and other key considerations for maker businesses here: [http://blog.ponoko.com/2010/11/16/ten-rules-for-maker-businesses-by-wireds-chris-anderson-%E2%80%94-rule-1](http://blog.ponoko.com/2010/11/16/ten-rules-for-maker-businesses-by-wireds-chris-anderson-%E2%80%94-rule-1)

At a sale price of 2.0x cost price the heatpump monitor kit costs £26 x 2.0 = £52 ex VAT (£62.40 inc VAT).

### One off prototype example:

**All pricing below is ex VAT**

<table cellspacing="0" border="0">
	<colgroup span="8" width="85"></colgroup>
	<tr>
		<td height="17" align="left"><b>Component name</b></td>
		<td align="center"><b>Quantity</b></td>
		<td align="center"><b>Cost</b></td>
		<td align="center"><b>Product</b></td>
		<td align="center"><b>Supplier</b></td>
		<td align="center"><b>Unit cost</b></td>
		<td align="center"><b>Price Quantity</b></td>
		<td align="center"><b>Minimum Order Quantity</b></td>
	</tr>
	<tr>
		<td height="17" align="left"><b><br></b></td>
		<td align="center"><br></td>
		<td align="center"><br></td>
		<td align="center"><br></td>
		<td align="center"><br></td>
		<td align="center"><br></td>
		<td align="center"><br></td>
		<td align="center"><br></td>
	</tr>
	<tr>
		<td height="17" align="left"><b>Heatpump monitor PCB</b></td>
		<td align="center" sdval="1" sdnum="2057;">1</td>
		<td align="center" sdval="28.9333333333333" sdnum="2057;0;[$£-809]#,##0.00;[RED]-[$£-809]#,##0.00">£28.93</td>
		<td align="center"><br></td>
		<td align="center">Ragworm</td>
		<td align="center"><br></td>
		<td align="center" sdval="1" sdnum="2057;">1</td>
		<td align="center" sdval="1" sdnum="2057;">1</td>
	</tr>
	<tr>
		<td height="17" align="left"><br></td>
		<td align="center"><br></td>
		<td align="center" sdnum="2057;0;[$£-809]#,##0.00;[RED]-[$£-809]#,##0.00"><br></td>
		<td align="center"><br></td>
		<td align="center"><br></td>
		<td align="center"><br></td>
		<td align="center"><br></td>
		<td align="center"><br></td>
	</tr>
	<tr>
		<td height="17" align="left"><b>Connectors and headers</b></td>
		<td align="center"><br></td>
		<td align="center" sdnum="2057;0;[$£-809]#,##0.00;[RED]-[$£-809]#,##0.00"><br></td>
		<td align="center"><br></td>
		<td align="center"><br></td>
		<td align="center"><br></td>
		<td align="center"><br></td>
		<td align="center"><br></td>
	</tr>
	<tr>
		<td height="17" align="left">3.5mm CT jack sockets</td>
		<td align="center" sdval="3" sdnum="2057;">3</td>
		<td align="center" sdval="1.038" sdnum="2057;0;[$£-809]#,##0.00;[RED]-[$£-809]#,##0.00">£1.04</td>
		<td align="center">20-0157</td>
		<td align="center">rapid</td>
		<td align="center" sdval="0.346" sdnum="2057;0;[$£-809]#,##0.000;[RED]-[$£-809]#,##0.000">£0.346</td>
		<td align="center">1-24</td>
		<td align="center" sdval="1" sdnum="2057;">1</td>
	</tr>
	<tr>
		<td height="17" align="left">2.1mm DC ACAC socket</td>
		<td align="center" sdval="1" sdnum="2057;">1</td>
		<td align="center" sdval="0.19" sdnum="2057;0;[$£-809]#,##0.00;[RED]-[$£-809]#,##0.00">£0.19</td>
		<td align="center">20-0970</td>
		<td align="center">rapid</td>
		<td align="center" sdval="0.19" sdnum="2057;0;[$£-809]#,##0.000;[RED]-[$£-809]#,##0.000">£0.190</td>
		<td align="center">10-99</td>
		<td align="center" sdval="10" sdnum="2057;">10</td>
	</tr>
	<tr>
		<td height="17" align="left">3 Way 3.5mm terminal block</td>
		<td align="center" sdval="8" sdnum="2057;">8</td>
		<td align="center" sdval="1.52" sdnum="2057;0;[$£-809]#,##0.00;[RED]-[$£-809]#,##0.00">£1.52</td>
		<td align="center">21-3001</td>
		<td align="center">rapid</td>
		<td align="center" sdval="0.19" sdnum="2057;0;[$£-809]#,##0.000;[RED]-[$£-809]#,##0.000">£0.190</td>
		<td align="center">10-99</td>
		<td align="center" sdval="10" sdnum="2057;">10</td>
	</tr>
	<tr>
		<td height="17" align="left">USB mini</td>
		<td align="center" sdval="1" sdnum="2057;">1</td>
		<td align="center" sdval="0.745" sdnum="2057;0;[$£-809]#,##0.00;[RED]-[$£-809]#,##0.00">£0.75</td>
		<td align="center" sdval="565790511" sdnum="2057;">565790511</td>
		<td align="center">farnell</td>
		<td align="center" sdval="0.745" sdnum="2057;0;[$£-809]#,##0.000;[RED]-[$£-809]#,##0.000">£0.745</td>
		<td align="center">1-24</td>
		<td align="center" sdval="1" sdnum="2057;">1</td>
	</tr>
	<tr>
		<td height="17" align="left">ESP-12</td>
		<td align="center" sdval="1" sdnum="2057;">1</td>
		<td align="center" sdval="2.45" sdnum="2057;0;[$£-809]#,##0.00;[RED]-[$£-809]#,##0.00">£2.45</td>
		<td align="center">ESP12</td>
		<td align="center">Ebay</td>
		<td align="center" sdval="2.45" sdnum="2057;0;[$£-809]#,##0.00;[RED]-[$£-809]#,##0.00">£2.45</td>
		<td align="center" sdval="1" sdnum="2057;">1</td>
		<td align="center" sdval="1" sdnum="2057;">1</td>
	</tr>
	<tr>
		<td height="17" align="left">RFM69</td>
		<td align="center" sdval="1" sdnum="2057;">1</td>
		<td align="center" sdval="3.2" sdnum="2057;0;[$£-809]#,##0.00;[RED]-[$£-809]#,##0.00">£3.20</td>
		<td align="center">RFM69</td>
		<td align="center">Ebay</td>
		<td align="center" sdval="3.2" sdnum="2057;0;[$£-809]#,##0.000;[RED]-[$£-809]#,##0.000">£3.200</td>
		<td align="center" sdval="1" sdnum="2057;">1</td>
		<td align="center" sdval="1" sdnum="2057;">1</td>
	</tr>
	<tr>
		<td height="17" align="left">2 way headers</td>
		<td align="center" sdval="3" sdnum="2057;">3</td>
		<td align="center" sdval="0.0609" sdnum="2057;0;[$£-809]#,##0.00;[RED]-[$£-809]#,##0.00">£0.06</td>
		<td align="center" sdval="1593411" sdnum="2057;">1593411</td>
		<td align="center">farnell</td>
		<td align="center" sdval="0.0203" sdnum="2057;0;[$£-809]#,##0.000;[RED]-[$£-809]#,##0.000">£0.020</td>
		<td align="center">100-499</td>
		<td align="center" sdval="100" sdnum="2057;">100</td>
	</tr>
	<tr>
		<td height="17" align="left">6 way headers</td>
		<td align="center" sdval="2" sdnum="2057;">2</td>
		<td align="center" sdval="0.522" sdnum="2057;0;[$£-809]#,##0.00;[RED]-[$£-809]#,##0.00">£0.52</td>
		<td align="center" sdval="1593415" sdnum="2057;">1593415</td>
		<td align="center">farnell</td>
		<td align="center" sdval="0.261" sdnum="2057;0;[$£-809]#,##0.000;[RED]-[$£-809]#,##0.000">£0.261</td>
		<td align="center">10-49</td>
		<td align="center" sdval="10" sdnum="2057;">10</td>
	</tr>
	<tr>
		<td height="17" align="left"><br></td>
		<td align="center"><br></td>
		<td align="center" sdnum="2057;0;[$£-809]#,##0.00;[RED]-[$£-809]#,##0.00"><br></td>
		<td align="center"><br></td>
		<td align="center"><br></td>
		<td align="center" sdnum="2057;0;[$£-809]#,##0.000;[RED]-[$£-809]#,##0.000"><br></td>
		<td align="center"><br></td>
		<td align="center"><br></td>
	</tr>
	<tr>
		<td height="17" align="left">jumper</td>
		<td align="center" sdval="2" sdnum="2057;">2</td>
		<td align="center" sdval="0.16" sdnum="2057;0;[$£-809]#,##0.00;[RED]-[$£-809]#,##0.00">£0.16</td>
		<td align="center">22-0690</td>
		<td align="center">rapid</td>
		<td align="center" sdval="0.08" sdnum="2057;0;[$£-809]#,##0.000;[RED]-[$£-809]#,##0.000">£0.080</td>
		<td align="center">10-99</td>
		<td align="center" sdval="10" sdnum="2057;">10</td>
	</tr>
	<tr>
		<td height="17" align="left">5x2 way female header RASPI</td>
		<td align="center" sdval="1" sdnum="2057;">1</td>
		<td align="center" sdval="0.1" sdnum="2057;0;[$£-809]#,##0.00;[RED]-[$£-809]#,##0.00">£0.10</td>
		<td align="center">19-0284</td>
		<td align="center">rapid</td>
		<td align="center" sdval="0.1" sdnum="2057;0;[$£-809]#,##0.000;[RED]-[$£-809]#,##0.000">£0.100</td>
		<td align="center">10-99</td>
		<td align="center" sdval="10" sdnum="2057;">10</td>
	</tr>
	<tr>
		<td height="17" align="left"><br></td>
		<td align="center"><br></td>
		<td align="center" sdnum="2057;0;[$£-809]#,##0.00;[RED]-[$£-809]#,##0.00"><br></td>
		<td align="center"><br></td>
		<td align="center"><br></td>
		<td align="center" sdnum="2057;0;[$£-809]#,##0.000;[RED]-[$£-809]#,##0.000"><br></td>
		<td align="center"><br></td>
		<td align="center"><br></td>
	</tr>
	<tr>
		<td height="17" align="left"><b>Capacitors</b></td>
		<td align="center"><br></td>
		<td align="center" sdnum="2057;0;[$£-809]#,##0.00;[RED]-[$£-809]#,##0.00"><br></td>
		<td align="center"><br></td>
		<td align="center"><br></td>
		<td align="center" sdnum="2057;0;[$£-809]#,##0.000;[RED]-[$£-809]#,##0.000"><br></td>
		<td align="center"><br></td>
		<td align="center"><br></td>
	</tr>
	<tr>
		<td height="17" align="left">100nf</td>
		<td align="center" sdval="7" sdnum="2057;">7</td>
		<td align="center" sdval="0.1554" sdnum="2057;0;[$£-809]#,##0.00;[RED]-[$£-809]#,##0.00">£0.16</td>
		<td align="center">08-0235</td>
		<td align="center">rapid</td>
		<td align="center" sdval="0.0222" sdnum="2057;0;[$£-809]#,##0.000;[RED]-[$£-809]#,##0.000">£0.022</td>
		<td align="center">10-99</td>
		<td align="center" sdval="10" sdnum="2057;">10</td>
	</tr>
	<tr>
		<td height="17" align="left">22pf</td>
		<td align="center" sdval="2" sdnum="2057;">2</td>
		<td align="center" sdval="0.0244" sdnum="2057;0;[$£-809]#,##0.00;[RED]-[$£-809]#,##0.00">£0.02</td>
		<td align="center">08-0046</td>
		<td align="center">rapid</td>
		<td align="center" sdval="0.0122" sdnum="2057;0;[$£-809]#,##0.000;[RED]-[$£-809]#,##0.000">£0.012</td>
		<td align="center">10-99</td>
		<td align="center" sdval="10" sdnum="2057;">10</td>
	</tr>
	<tr>
		<td height="17" align="left">10uf</td>
		<td align="center" sdval="6" sdnum="2057;">6</td>
		<td align="center" sdval="0.264" sdnum="2057;0;[$£-809]#,##0.00;[RED]-[$£-809]#,##0.00">£0.26</td>
		<td align="center">11-0825</td>
		<td align="center">rapid</td>
		<td align="center" sdval="0.044" sdnum="2057;0;[$£-809]#,##0.000;[RED]-[$£-809]#,##0.000">£0.044</td>
		<td align="center">1to9</td>
		<td align="center" sdval="1" sdnum="2057;">1</td>
	</tr>
	<tr>
		<td height="17" align="left"><br></td>
		<td align="center"><br></td>
		<td align="center" sdnum="2057;0;[$£-809]#,##0.00;[RED]-[$£-809]#,##0.00"><br></td>
		<td align="center"><br></td>
		<td align="center"><br></td>
		<td align="center" sdnum="2057;0;[$£-809]#,##0.000;[RED]-[$£-809]#,##0.000"><br></td>
		<td align="center"><br></td>
		<td align="center"><br></td>
	</tr>
	<tr>
		<td height="17" align="left"><b>Resistors</b></td>
		<td align="center"><br></td>
		<td align="center" sdnum="2057;0;[$£-809]#,##0.00;[RED]-[$£-809]#,##0.00"><br></td>
		<td align="center"><br></td>
		<td align="center"><br></td>
		<td align="center" sdnum="2057;0;[$£-809]#,##0.000;[RED]-[$£-809]#,##0.000"><br></td>
		<td align="center"><br></td>
		<td align="center"><br></td>
	</tr>
	<tr>
		<td height="17" align="left">470k 5%</td>
		<td align="center" sdval="8" sdnum="2057;">8</td>
		<td align="center" sdval="0.0496" sdnum="2057;0;[$£-809]#,##0.00;[RED]-[$£-809]#,##0.00">£0.05</td>
		<td align="center">62-0434</td>
		<td align="center">rapid</td>
		<td align="center" sdval="0.0062" sdnum="2057;0;[$£-809]#,##0.000;[RED]-[$£-809]#,##0.000">£0.006</td>
		<td align="center" sdval="100" sdnum="2057;">100</td>
		<td align="center">pack of 100</td>
	</tr>
	<tr>
		<td height="17" align="left">10k 5%</td>
		<td align="center" sdval="3" sdnum="2057;">3</td>
		<td align="center" sdval="0.0186" sdnum="2057;0;[$£-809]#,##0.00;[RED]-[$£-809]#,##0.00">£0.02</td>
		<td align="center">62-0394</td>
		<td align="center">rapid</td>
		<td align="center" sdval="0.0062" sdnum="2057;0;[$£-809]#,##0.000;[RED]-[$£-809]#,##0.000">£0.006</td>
		<td align="center" sdval="100" sdnum="2057;">100</td>
		<td align="center">pack of 100</td>
	</tr>
	<tr>
		<td height="17" align="left">10k 1%</td>
		<td align="center" sdval="1" sdnum="2057;">1</td>
		<td align="center" sdval="0.0118" sdnum="2057;0;[$£-809]#,##0.00;[RED]-[$£-809]#,##0.00">£0.01</td>
		<td align="center">62-3474</td>
		<td align="center">rapid</td>
		<td align="center" sdval="0.0118" sdnum="2057;0;[$£-809]#,##0.000;[RED]-[$£-809]#,##0.000">£0.012</td>
		<td align="center" sdval="100" sdnum="2057;">100</td>
		<td align="center">pack of 100</td>
	</tr>
	<tr>
		<td height="17" align="left">4.7k 5%</td>
		<td align="center" sdval="1" sdnum="2057;">1</td>
		<td align="center" sdval="0.0062" sdnum="2057;0;[$£-809]#,##0.00;[RED]-[$£-809]#,##0.00">£0.01</td>
		<td align="center">62-0386</td>
		<td align="center">rapid</td>
		<td align="center" sdval="0.0062" sdnum="2057;0;[$£-809]#,##0.000;[RED]-[$£-809]#,##0.000">£0.006</td>
		<td align="center" sdval="100" sdnum="2057;">100</td>
		<td align="center">pack of 100</td>
	</tr>
	<tr>
		<td height="17" align="left">100k</td>
		<td align="center" sdval="1" sdnum="2057;">1</td>
		<td align="center" sdval="0.0062" sdnum="2057;0;[$£-809]#,##0.00;[RED]-[$£-809]#,##0.00">£0.01</td>
		<td align="center">62-0418</td>
		<td align="center">rapid</td>
		<td align="center" sdval="0.0062" sdnum="2057;0;[$£-809]#,##0.000;[RED]-[$£-809]#,##0.000">£0.006</td>
		<td align="center" sdval="100" sdnum="2057;">100</td>
		<td align="center">pack of 100</td>
	</tr>
	<tr>
		<td height="17" align="left">100R 5%</td>
		<td align="center" sdval="1" sdnum="2057;">1</td>
		<td align="center" sdval="0.0062" sdnum="2057;0;[$£-809]#,##0.00;[RED]-[$£-809]#,##0.00">£0.01</td>
		<td align="center">62-0346</td>
		<td align="center">rapid</td>
		<td align="center" sdval="0.0062" sdnum="2057;0;[$£-809]#,##0.000;[RED]-[$£-809]#,##0.000">£0.006</td>
		<td align="center" sdval="100" sdnum="2057;">100</td>
		<td align="center">pack of 100</td>
	</tr>
	<tr>
		<td height="17" align="left">CT burden resistors 22R</td>
		<td align="center" sdval="3" sdnum="2057;">3</td>
		<td align="center" sdval="0.0354" sdnum="2057;0;[$£-809]#,##0.00;[RED]-[$£-809]#,##0.00">£0.04</td>
		<td align="center">62-3426</td>
		<td align="center">rapid</td>
		<td align="center" sdval="0.0118" sdnum="2057;0;[$£-809]#,##0.000;[RED]-[$£-809]#,##0.000">£0.012</td>
		<td align="center" sdval="100" sdnum="2057;">100</td>
		<td align="center">pack of 100</td>
	</tr>
	<tr>
		<td height="17" align="left">CT burden resistors 100R</td>
		<td align="center" sdval="3" sdnum="2057;">3</td>
		<td align="center" sdval="0.0354" sdnum="2057;0;[$£-809]#,##0.00;[RED]-[$£-809]#,##0.00">£0.04</td>
		<td align="center">62-3426</td>
		<td align="center">rapid</td>
		<td align="center" sdval="0.0118" sdnum="2057;0;[$£-809]#,##0.000;[RED]-[$£-809]#,##0.000">£0.012</td>
		<td align="center" sdval="100" sdnum="2057;">100</td>
		<td align="center">pack of 100</td>
	</tr>
	<tr>
		<td height="17" align="left">120K</td>
		<td align="center" sdval="1" sdnum="2057;">1</td>
		<td align="center" sdval="0.0118" sdnum="2057;0;[$£-809]#,##0.00;[RED]-[$£-809]#,##0.00">£0.01</td>
		<td align="center">62-3500</td>
		<td align="center">rapid</td>
		<td align="center" sdval="0.0118" sdnum="2057;0;[$£-809]#,##0.000;[RED]-[$£-809]#,##0.000">£0.012</td>
		<td align="center" sdval="100" sdnum="2057;">100</td>
		<td align="center">pack of 100</td>
	</tr>
	<tr>
		<td height="17" align="left">5k6</td>
		<td align="center" sdval="1" sdnum="2057;">1</td>
		<td align="center" sdval="0.0062" sdnum="2057;0;[$£-809]#,##0.00;[RED]-[$£-809]#,##0.00">£0.01</td>
		<td align="center">62-0388</td>
		<td align="center">rapid</td>
		<td align="center" sdval="0.0062" sdnum="2057;0;[$£-809]#,##0.000;[RED]-[$£-809]#,##0.000">£0.006</td>
		<td align="center" sdval="100" sdnum="2057;">100</td>
		<td align="center">pack of 100</td>
	</tr>
	<tr>
		<td height="17" align="left"><br></td>
		<td align="center"><br></td>
		<td align="center" sdnum="2057;0;[$£-809]#,##0.00;[RED]-[$£-809]#,##0.00"><br></td>
		<td align="center"><br></td>
		<td align="center"><br></td>
		<td align="center" sdnum="2057;0;[$£-809]#,##0.000;[RED]-[$£-809]#,##0.000"><br></td>
		<td align="center"><br></td>
		<td align="center"><br></td>
	</tr>
	<tr>
		<td height="17" align="left"><b>Other</b></td>
		<td align="center"><br></td>
		<td align="center" sdnum="2057;0;[$£-809]#,##0.00;[RED]-[$£-809]#,##0.00"><br></td>
		<td align="center"><br></td>
		<td align="center"><br></td>
		<td align="center" sdnum="2057;0;[$£-809]#,##0.000;[RED]-[$£-809]#,##0.000"><br></td>
		<td align="center"><br></td>
		<td align="center"><br></td>
	</tr>
	<tr>
		<td height="17" align="left">16 Mhz crystal</td>
		<td align="center" sdval="1" sdnum="2057;">1</td>
		<td align="center" sdval="0.212" sdnum="2057;0;[$£-809]#,##0.00;[RED]-[$£-809]#,##0.00">£0.21</td>
		<td align="center">90-2378</td>
		<td align="center">rapid</td>
		<td align="center" sdval="0.212" sdnum="2057;0;[$£-809]#,##0.000;[RED]-[$£-809]#,##0.000">£0.212</td>
		<td align="center">1to24</td>
		<td align="center" sdval="1" sdnum="2057;">1</td>
	</tr>
	<tr>
		<td height="17" align="left">atmega328</td>
		<td align="center" sdval="1" sdnum="2057;">1</td>
		<td align="center" sdval="2.41" sdnum="2057;0;[$£-809]#,##0.00;[RED]-[$£-809]#,##0.00">£2.41</td>
		<td align="center" sdval="1715487" sdnum="2057;">1715487</td>
		<td align="center">farnell</td>
		<td align="center" sdval="2.41" sdnum="2057;0;[$£-809]#,##0.000;[RED]-[$£-809]#,##0.000">£2.410</td>
		<td align="center">1to9</td>
		<td align="center" sdval="1" sdnum="2057;">1</td>
	</tr>
	<tr>
		<td height="17" align="left">28pin DIL</td>
		<td align="center" sdval="1" sdnum="2057;">1</td>
		<td align="center" sdval="0.453" sdnum="2057;0;[$£-809]#,##0.00;[RED]-[$£-809]#,##0.00">£0.45</td>
		<td align="center" sdval="2445626" sdnum="2057;">2445626</td>
		<td align="center">farnell</td>
		<td align="center" sdval="0.453" sdnum="2057;0;[$£-809]#,##0.000;[RED]-[$£-809]#,##0.000">£0.453</td>
		<td align="center">10-99</td>
		<td align="center" sdval="10" sdnum="2057;">10</td>
	</tr>
	<tr>
		<td height="17" align="left">MCP1825S-3302</td>
		<td align="center" sdval="1" sdnum="2057;">1</td>
		<td align="center" sdval="0.45" sdnum="2057;0;[$£-809]#,##0.00;[RED]-[$£-809]#,##0.00">£0.45</td>
		<td align="center" sdval="1578404" sdnum="2057;">1578404</td>
		<td align="center">farnell</td>
		<td align="center" sdval="0.45" sdnum="2057;0;[$£-809]#,##0.000;[RED]-[$£-809]#,##0.000">£0.450</td>
		<td align="center">1to9</td>
		<td align="center" sdval="1" sdnum="2057;">1</td>
	</tr>
	<tr>
		<td height="17" align="left">LED</td>
		<td align="center" sdval="1" sdnum="2057;">1</td>
		<td align="center" sdnum="2057;0;[$£-809]#,##0.00;[RED]-[$£-809]#,##0.00"><br></td>
		<td align="center"><br></td>
		<td align="center"><br></td>
		<td align="center" sdnum="2057;0;[$£-809]#,##0.000;[RED]-[$£-809]#,##0.000"><br></td>
		<td align="center"><br></td>
		<td align="center"><br></td>
	</tr>
	<tr>
		<td height="17" align="left"><br></td>
		<td align="center"><br></td>
		<td align="center" sdnum="2057;0;[$£-809]#,##0.00;[RED]-[$£-809]#,##0.00"><br></td>
		<td align="center"><br></td>
		<td align="center"><br></td>
		<td align="center" sdnum="2057;0;[$£-809]#,##0.000;[RED]-[$£-809]#,##0.000"><br></td>
		<td align="center"><br></td>
		<td align="center"><br></td>
	</tr>
	<tr>
		<td height="17" align="left"><b>MBUS meter reader</b></td>
		<td align="center"><br></td>
		<td align="center" sdnum="2057;0;[$£-809]#,##0.00;[RED]-[$£-809]#,##0.00"><br></td>
		<td align="center"><br></td>
		<td align="center"><br></td>
		<td align="center" sdnum="2057;0;[$£-809]#,##0.000;[RED]-[$£-809]#,##0.000"><br></td>
		<td align="center"><br></td>
		<td align="center"><br></td>
	</tr>
	<tr>
		<td height="17" align="left">BC307 or other PNP, BC557:1:C,2:B,3:E</td>
		<td align="center" sdval="1" sdnum="2057;">1</td>
		<td align="center" sdval="0.0401" sdnum="2057;0;[$£-809]#,##0.00;[RED]-[$£-809]#,##0.00">£0.04</td>
		<td align="center" sdval="2453805" sdnum="2057;">2453805</td>
		<td align="center">farnell</td>
		<td align="center" sdval="0.0401" sdnum="2057;0;[$£-809]#,##0.000;[RED]-[$£-809]#,##0.000">£0.040</td>
		<td align="center">5-249</td>
		<td align="center" sdval="5" sdnum="2057;">5</td>
	</tr>
	<tr>
		<td height="17" align="left">BC337 or other NPN,BC547:1:C,2:B,3:E</td>
		<td align="center" sdval="2" sdnum="2057;">2</td>
		<td align="center" sdval="0.0802" sdnum="2057;0;[$£-809]#,##0.00;[RED]-[$£-809]#,##0.00">£0.08</td>
		<td align="center" sdval="2453790" sdnum="2057;">2453790</td>
		<td align="center">farnell</td>
		<td align="center" sdval="0.0401" sdnum="2057;0;[$£-809]#,##0.000;[RED]-[$£-809]#,##0.000">£0.040</td>
		<td align="center">5-249</td>
		<td align="center" sdval="5" sdnum="2057;">5</td>
	</tr>
	<tr>
		<td height="17" align="left">220k</td>
		<td align="center" sdval="1" sdnum="2057;">1</td>
		<td align="center" sdval="0.00624" sdnum="2057;0;[$£-809]#,##0.00;[RED]-[$£-809]#,##0.00">£0.01</td>
		<td align="center">62-0426</td>
		<td align="center">rapid</td>
		<td align="center" sdval="0.00624" sdnum="2057;0;[$£-809]#,##0.000;[RED]-[$£-809]#,##0.000">£0.006</td>
		<td align="center" sdval="100" sdnum="2057;">100</td>
		<td align="center">pack of 100</td>
	</tr>
	<tr>
		<td height="17" align="left">33k</td>
		<td align="center" sdval="1" sdnum="2057;">1</td>
		<td align="center" sdval="0.00624" sdnum="2057;0;[$£-809]#,##0.00;[RED]-[$£-809]#,##0.00">£0.01</td>
		<td align="center"><br></td>
		<td align="center">rapid</td>
		<td align="center" sdval="0.00624" sdnum="2057;0;[$£-809]#,##0.000;[RED]-[$£-809]#,##0.000">£0.006</td>
		<td align="center" sdval="100" sdnum="2057;">100</td>
		<td align="center">pack of 100</td>
	</tr>
	<tr>
		<td height="17" align="left">39k</td>
		<td align="center" sdval="1" sdnum="2057;">1</td>
		<td align="center" sdval="0.00624" sdnum="2057;0;[$£-809]#,##0.00;[RED]-[$£-809]#,##0.00">£0.01</td>
		<td align="center">62-0408</td>
		<td align="center">rapid</td>
		<td align="center" sdval="0.00624" sdnum="2057;0;[$£-809]#,##0.000;[RED]-[$£-809]#,##0.000">£0.006</td>
		<td align="center" sdval="100" sdnum="2057;">100</td>
		<td align="center">pack of 100</td>
	</tr>
	<tr>
		<td height="17" align="left">22k</td>
		<td align="center" sdval="1" sdnum="2057;">1</td>
		<td align="center" sdval="0.00624" sdnum="2057;0;[$£-809]#,##0.00;[RED]-[$£-809]#,##0.00">£0.01</td>
		<td align="center">62-0402</td>
		<td align="center">rapid</td>
		<td align="center" sdval="0.00624" sdnum="2057;0;[$£-809]#,##0.000;[RED]-[$£-809]#,##0.000">£0.006</td>
		<td align="center" sdval="100" sdnum="2057;">100</td>
		<td align="center">pack of 100</td>
	</tr>
	<tr>
		<td height="17" align="left">3k3</td>
		<td align="center" sdval="1" sdnum="2057;">1</td>
		<td align="center" sdval="0.00624" sdnum="2057;0;[$£-809]#,##0.00;[RED]-[$£-809]#,##0.00">£0.01</td>
		<td align="center">62-0382</td>
		<td align="center">rapid</td>
		<td align="center" sdval="0.00624" sdnum="2057;0;[$£-809]#,##0.000;[RED]-[$£-809]#,##0.000">£0.006</td>
		<td align="center" sdval="100" sdnum="2057;">100</td>
		<td align="center">pack of 100</td>
	</tr>
	<tr>
		<td height="17" align="left">82r</td>
		<td align="center" sdval="1" sdnum="2057;">1</td>
		<td align="center" sdval="0.00624" sdnum="2057;0;[$£-809]#,##0.00;[RED]-[$£-809]#,##0.00">£0.01</td>
		<td align="center">62-0344</td>
		<td align="center">rapid</td>
		<td align="center" sdval="0.00624" sdnum="2057;0;[$£-809]#,##0.000;[RED]-[$£-809]#,##0.000">£0.006</td>
		<td align="center" sdval="100" sdnum="2057;">100</td>
		<td align="center">pack of 100</td>
	</tr>
	<tr>
		<td height="17" align="left">1K</td>
		<td align="center" sdval="2" sdnum="2057;">2</td>
		<td align="center" sdval="0.01248" sdnum="2057;0;[$£-809]#,##0.00;[RED]-[$£-809]#,##0.00">£0.01</td>
		<td align="center">62-0370</td>
		<td align="center">rapid</td>
		<td align="center" sdval="0.00624" sdnum="2057;0;[$£-809]#,##0.000;[RED]-[$£-809]#,##0.000">£0.006</td>
		<td align="center" sdval="100" sdnum="2057;">100</td>
		<td align="center">pack of 100</td>
	</tr>
	<tr>
		<td height="17" align="left">2 way header female</td>
		<td align="center" sdval="4" sdnum="2057;">4</td>
		<td align="center" sdval="0.136" sdnum="2057;0;[$£-809]#,##0.00;[RED]-[$£-809]#,##0.00">£0.14</td>
		<td align="center">19-0081</td>
		<td align="center">rapid</td>
		<td align="center" sdval="0.034" sdnum="2057;0;[$£-809]#,##0.000;[RED]-[$£-809]#,##0.000">£0.034</td>
		<td align="center">50-99</td>
		<td align="center">pack of 50</td>
	</tr>
	<tr>
		<td height="17" align="left">2 way headers</td>
		<td align="center" sdval="4" sdnum="2057;">4</td>
		<td align="center" sdval="0.0812" sdnum="2057;0;[$£-809]#,##0.00;[RED]-[$£-809]#,##0.00">£0.08</td>
		<td align="center" sdval="1593411" sdnum="2057;">1593411</td>
		<td align="center">farnell</td>
		<td align="center" sdval="0.0203" sdnum="2057;0;[$£-809]#,##0.000;[RED]-[$£-809]#,##0.000">£0.020</td>
		<td align="center">100-499</td>
		<td align="center" sdval="100" sdnum="2057;">100</td>
	</tr>
	<tr>
		<td height="17" align="left">5v to 24v boost converter</td>
		<td align="center" sdval="1" sdnum="2057;">1</td>
		<td align="center" sdval="2.2" sdnum="2057;0;[$£-809]#,##0.00;[RED]-[$£-809]#,##0.00">£2.20</td>
		<td align="center"><br></td>
		<td align="center">ebay</td>
		<td align="center" sdval="2.2" sdnum="2057;0;[$£-809]#,##0.00;[RED]-[$£-809]#,##0.00">£2.20</td>
		<td align="center" sdval="1" sdnum="2057;">1</td>
		<td align="center" sdval="1" sdnum="2057;">1</td>
	</tr>
	<tr>
		<td height="17" align="left"><b><br></b></td>
		<td align="center"><b><br></b></td>
		<td align="center" sdnum="2057;0;[$£-809]#,##0.00;[RED]-[$£-809]#,##0.00"><b><br></b></td>
		<td align="center"><br></td>
		<td align="center"><br></td>
		<td align="center" sdnum="2057;0;[$£-809]#,##0.000;[RED]-[$£-809]#,##0.000"><br></td>
		<td align="center"><br></td>
		<td align="center"><br></td>
	</tr>
	<tr>
		<td height="17" align="left"><b>MBUS meter reader cost</b></td>
		<td align="center"><b><br></b></td>
		<td align="center" sdval="2.58742" sdnum="2057;0;[$£-809]#,##0.00;[RED]-[$£-809]#,##0.00"><b>£2.59</b></td>
		<td align="center"><br></td>
		<td align="center"><br></td>
		<td align="center" sdnum="2057;0;[$£-809]#,##0.000;[RED]-[$£-809]#,##0.000"><br></td>
		<td align="center"><br></td>
		<td align="center"><br></td>
	</tr>
	<tr>
		<td height="17" align="left"><b>Total Component cost</b></td>
		<td align="center"><b><br></b></td>
		<td align="center" sdval="16.72952" sdnum="2057;0;[$£-809]#,##0.00;[RED]-[$£-809]#,##0.00"><b>£16.73</b></td>
		<td align="center"><br></td>
		<td align="center"><br></td>
		<td align="center" sdnum="2057;0;[$£-809]#,##0.000;[RED]-[$£-809]#,##0.000"><br></td>
		<td align="center"><br></td>
		<td align="center"><br></td>
	</tr>
	<tr>
		<td height="17" align="left"><b>PCB cost</b></td>
		<td align="center"><b><br></b></td>
		<td align="center" sdval="28.9333333333333" sdnum="2057;0;[$£-809]#,##0.00;[RED]-[$£-809]#,##0.00"><b>£28.93</b></td>
		<td align="center"><br></td>
		<td align="center"><br></td>
		<td align="center" sdnum="2057;0;[$£-809]#,##0.000;[RED]-[$£-809]#,##0.000"><br></td>
		<td align="center"><br></td>
		<td align="center"><br></td>
	</tr>
	<tr>
		<td height="17" align="left"><br></td>
		<td align="center"><br></td>
		<td align="center" sdnum="2057;0;[$£-809]#,##0.00;[RED]-[$£-809]#,##0.00"><br></td>
		<td align="center"><br></td>
		<td align="center"><br></td>
		<td align="center" sdnum="2057;0;[$£-809]#,##0.000;[RED]-[$£-809]#,##0.000"><br></td>
		<td align="center"><br></td>
		<td align="center"><br></td>
	</tr>
	<tr>
		<td height="17" align="left"><br></td>
		<td align="center"><br></td>
		<td align="center" sdnum="2057;0;[$£-809]#,##0.00;[RED]-[$£-809]#,##0.00"><br></td>
		<td align="center"><br></td>
		<td align="center"><br></td>
		<td align="center" sdnum="2057;0;[$£-809]#,##0.000;[RED]-[$£-809]#,##0.000"><br></td>
		<td align="center"><br></td>
		<td align="center"><br></td>
	</tr>
	<tr>
		<td height="17" align="left"><b>Enclosure</b></td>
		<td align="center"><br></td>
		<td align="center" sdnum="2057;0;[$£-809]#,##0.00;[RED]-[$£-809]#,##0.00"><br></td>
		<td align="center"><br></td>
		<td align="center"><br></td>
		<td align="center" sdnum="2057;0;[$£-809]#,##0.000;[RED]-[$£-809]#,##0.000"><br></td>
		<td align="center"><br></td>
		<td align="center"><br></td>
	</tr>
	<tr>
		<td height="17" align="left">EmonTx v3 aluminium enclosure</td>
		<td align="center" sdval="1" sdnum="2057;">1</td>
		<td align="center" sdval="4.74" sdnum="2057;0;[$£-809]#,##0.00;[RED]-[$£-809]#,##0.00">£4.74</td>
		<td align="center">EBS80</td>
		<td align="center">Lincoln Binns</td>
		<td align="center" sdval="4.74" sdnum="2057;0;[$£-809]#,##0.000;[RED]-[$£-809]#,##0.000">£4.740</td>
		<td align="center">1to9</td>
		<td align="center" sdval="1" sdnum="2057;">1</td>
	</tr>
	<tr>
		<td height="17" align="left">Laser cut facia pack</td>
		<td align="center" sdval="1" sdnum="2057;">1</td>
		<td align="center" sdval="3" sdnum="2057;0;[$£-809]#,##0.00;[RED]-[$£-809]#,##0.00">£3.00</td>
		<td align="center">recycled acrylic</td>
		<td align="center">custom</td>
		<td align="center" sdval="3" sdnum="2057;0;[$£-809]#,##0.000;[RED]-[$£-809]#,##0.000">£3.000</td>
		<td align="center" sdval="1" sdnum="2057;">1</td>
		<td align="center" sdval="1" sdnum="2057;">1</td>
	</tr>
	<tr>
		<td height="17" align="left">Enclosure screws</td>
		<td align="center" sdval="8" sdnum="2057;">8</td>
		<td align="center" sdval="0.0768" sdnum="2057;0;[$£-809]#,##0.00;[RED]-[$£-809]#,##0.00">£0.08</td>
		<td align="center">33-3415</td>
		<td align="center">rapid</td>
		<td align="center" sdval="0.0096" sdnum="2057;0;[$£-809]#,##0.000;[RED]-[$£-809]#,##0.000">£0.010</td>
		<td align="center">Pack of 100</td>
		<td align="center">Pack of 100</td>
	</tr>
	<tr>
		<td height="17" align="left">Total enclosure cost</td>
		<td align="center"><br></td>
		<td align="center" sdval="7.8168" sdnum="2057;0;[$£-809]#,##0.00;[RED]-[$£-809]#,##0.00"><b>£7.82</b></td>
		<td align="center"><br></td>
		<td align="center"><br></td>
		<td align="center"><br></td>
		<td align="center"><br></td>
		<td align="center"><br></td>
	</tr>
	<tr>
		<td height="17" align="left"><br></td>
		<td align="center"><br></td>
		<td align="center" sdnum="2057;0;[$£-809]#,##0.00;[RED]-[$£-809]#,##0.00"><br></td>
		<td align="center"><br></td>
		<td align="center"><br></td>
		<td align="center"><br></td>
		<td align="center"><br></td>
		<td align="center"><br></td>
	</tr>
	<tr>
		<td height="17" align="left"><b>Cost price (components, case and PCB)</b></td>
		<td align="center"><b><br></b></td>
		<td align="center" sdval="53.4796533333333" sdnum="2057;0;[$£-809]#,##0.00;[RED]-[$£-809]#,##0.00"><b>£53.48</b></td>
		<td align="center"><br></td>
		<td align="center"><br></td>
		<td align="center"><br></td>
		<td align="center"><br></td>
		<td align="center"><br></td>
	</tr>
</table>

### Heatpump Monitor

Costing summaries for different options & volumes. All prices are for unassembled kits.

First figure: cost price, second figure sale price (cost price x 2.0). See above.

With case: 

- 1x £53.48, £106.96
- 20x £29.93, £59.86
- OEM £28.88, £57.76
- OEM £27.32, £54.65 (50x PCB)

Without case: 

- 1x £45.66, £91.32
- 20x £23.59, £47.18
- OEM £22.54, £45.07
- OEM £20.98, £41.95 (50x PCB)

Spreadsheets:

- [HeatpumpMonitor/BOM&Costing_1x.ods](files/heatpumpmonitor/BOM&Costing_1x.ods)
- [HeatpumpMonitor/BOM&Costing_20x.ods](files/heatpumpmonitor/BOM&Costing_20x.ods)

### Energy Monitor

First figure: cost price, second figure sale price (cost price x 2.0). See above.

With case:

- 1x £46.12
- 20x £22.96, £45.92
- OEM £20.68 £41.36

Without case: 

- 1x £38.31
- 20x £16.61, £33.22
- OEM £15.10, £30.20

Spreadsheets:

- [EnergyMonitor/BOM&Costing_1x.ods](files/energymonitor/BOM&Costing_1x.ods)
- [EnergyMonitor/BOM&Costing_20x.ods](files/energymonitor/BOM&Costing_20x.ods)

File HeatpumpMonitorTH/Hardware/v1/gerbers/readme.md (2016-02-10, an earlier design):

# Heatpump monitor gerbers

There are the exported gerber files for the heatpump monitor and are what are sent to the PCB manufacturing company to produce the board. We used ragworm in the UK for our first prototype run.

To view these files on ubuntu linux try the Gerbv Gerber File Viewer.

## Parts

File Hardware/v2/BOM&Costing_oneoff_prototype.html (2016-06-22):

Component name | Quantity | Cost | Product | Supplier | Unit cost | VAT | Price Quantity | Minimum Order Quantity | Other notes
Heatpump monitor PCB | 1 | £34.72 |  | Ragworm |  |  | 1 | 1 | One off prototype cost
Connectors and headers
3.5mm CT jack sockets | 3 | £1.04 | 20-0157 | rapid | £0.346 |  | 1-24 | 1
2.1mm DC ACAC socket | 1 | £0.19 | 20-0970 | rapid | £0.190 |  | 10-99 | 10
3 Way 3.5mm terminal block | 9 | £1.71 | 21-3001 | rapid | £0.190 |  | 10-99 | 10
USB mini | 1 | £0.75 | 565790511 | farnell | £0.745 |  | 1-24 | 1
ESP-12 | 1 | £2.00 | ESP12 | Ebay | £2.000 |  | 1 | 1 | UK distributor
RFM69 | 1 | £3.20 | RFM69 | Ebay | £3.200 |  | 1 | 1 | UK distributor
2 way headers | 3 | £0.06 | 1593411 | farnell | £0.020 |  | 100-499 | 100
6 way headers | 2 | £0.52 | 1593415 | farnell | £0.261 |  | 10-49 | 10
3 way header | 1 | £0.07 | 1593412 | farnell | £0.070 |  | 50-99 | 50
jumper | 3 | £0.24 | 22-0690 | rapid | £0.080 |  | 10-99 | 10
5x2 way female header RASPI | 1 | £0.10 | 19-0284 | rapid | £0.100 |  | 10-99 | 10
Capacitors
100nf | 7 | £0.16 | 08-0235 | rapid | £0.022 |  | 10-99 | 10
22pf | 2 | £0.02 | 08-0046 | rapid | £0.012 |  | 10-99 | 10
10uf | 5 | £0.22 | 11-0825 | rapid | £0.044 |  | 1to9 | 1
1u | 1 | £0.06 | 11-0855 | rapid | £0.060 |  | 1to9 | 1
47u | 1 | £0.07 | 11-0835 | rapid | £0.068 |  | 1to9 | 1
Resistors
470k 5% | 8 | £0.05 | 62-0434 | rapid | £0.006 |  | 100 | pack of 100 | £4.59 for box of 1000 or £3.63 for 5000
10k 5% | 4 | £0.02 | 62-0394 | rapid | £0.006 |  | 100 | pack of 100
or 10k 1% |  |  | 62-3474 | rapid | £0.012 |  | 100 | pack of 100 | £7.18 for box of 1000 or £3.63 for 5000
4.7k 5% | 1 | £0.01 | 62-0386 | rapid | £0.006 |  | 100 | pack of 100
100k | 1 | £0.01 | 62-0418 | rapid | £0.006 |  | 100 | pack of 100
100R 5% | 1 | £0.01 | 62-0346 | rapid | £0.006 |  | 100 | pack of 100
CT burden resistors 22R or 100R | 3 | £0.04 | 62-3426 | rapid | £0.012 |  | 100 | pack of 100
120K | 1 | £0.01 | 62-3500 | rapid | £0.012 |  | 100 | pack of 100
5k6 | 1 | £0.01 | 62-0388 | rapid | £0.006 |  | 100 | pack of 100
56r | 1 | £0.01 | 62-0340 | rapid | £0.006 |  | 100 | pack of 100
Other
16 Mhz crystal | 1 | £0.21 | 90-2378 | rapid | £0.212 |  | 1to24 | 1
1N4148 or 1N4001? | 1 | £0.01 | 50-0381 | rapid | £0.014 |  | 50-99 | 50
atmega328 | 1 | £2.41 | 1715487 | farnell | £2.410 |  | 1to9 | 1
28pin DIL | 1 | £0.45 | 2445626 | farnell | £0.453 |  | 10-99 | 10
MCP1702 (3.3V) | 1 | £0.45 | 1331485 | farnell | £0.449 |  | 1to9 | 1
LED
MBUS meter reader
BC307 or other PNP, BC557:1:C,2:B,3:E | 1 | £0.04 | 2453805 | farnell | £0.040 |  | 5-249 | 5
BC337 or other NPN,BC547:1:C,2:B,3:E | 2 | £0.08 | 2453790 | farnell | £0.040 |  | 5-249 | 5
220k | 1 | £0.01 | 62-0426 | rapid | £0.006 |  | 100 | pack of 100
33k | 1 | £0.01 |  | rapid | £0.006 |  | 100 | pack of 100
39k | 1 | £0.01 | 62-0408 | rapid | £0.006 |  | 100 | pack of 100
22k | 1 | £0.01 | 62-0402 | rapid | £0.006 |  | 100 | pack of 100
3k3 | 1 | £0.01 | 62-0382 | rapid | £0.006 |  | 100 | pack of 100
82r | 1 | £0.01 | 62-0344 | rapid | £0.006 |  | 100 | pack of 100
1K | 2 | £0.01 | 62-0370 | rapid | £0.006 |  | 100 | pack of 100
2 way header female | 4 | £0.14 | 19-0081 | rapid | £0.034 |  | 50-99 | pack of 50
2 way headers | 4 | £0.08 | 1593411 | farnell | £0.020 |  | 100-499 | 100
5v to 24v boost converter | 1 | £1.99 |  | ebay | £1.990 |  | 1 | 1 | UK distributor
MBUS meter reader cost |  | £2.38
Total Component cost |  | £16.47
PCB cost |  | £34.72
Enclosure
EmonTx v3 aluminium enclosure | 1 | £4.74 | EBS80 | Lincoln Binns | £4.740 |  | 1to9 | 1 | http://www.lincolnbinns.com/e-case-b/
Laser cut facia pack | 1 | £3.00 | recycled acrylic | custom | £3.000 |  | 1 | 1 | Custom guide price: Laser cut clear acrylic
Enclosure screws | 8 | £0.08 | 33-3415 | rapid | £0.010 |  | Pack of 100 | Pack of 100
Total enclosure cost |  | £7.82
Cost price (components, case and PCB) |  | £59.01

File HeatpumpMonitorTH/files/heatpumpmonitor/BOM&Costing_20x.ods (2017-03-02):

 |  |  | Batch Size
 |  |  | 20
Component name | Quantity | Cost | Quantity Batch | Product | Supplier | Unit cost | Price Quantity | Other notes
Heatpump monitor PCB | 1 | £8.20 | 20 |  | Ragworm |  | 20x
Connectors and headers
3.5mm CT jack sockets | 3 | £0.77 | 60 | 20-0157 | rapid | £0.256 | 25-99
2.1mm DC ACAC socket | 1 | £0.19 | 20 | 20-0970 | rapid | £0.190 | 10-99
3 Way 3.5mm terminal block | 8 | £1.07 | 160 | 21-3001 | rapid | £0.134 | 100-500
USB mini | 1 | £0.75 | 20 | 565790511 | farnell | £0.745 | 1-24
ESP-12 | 1 | £2.45 | 20 | ESP12 | ebay/other | £2.45 | 1
RFM69 | 1 | £3.20 | 20 | RFM69 | ebay/other | £3.200 | 1
2 way headers | 3 | £0.06 | 60 | 1593411 | farnell | £0.020 | 100-499
6 way headers | 2 | £0.52 | 40 | 1593415 | farnell | £0.261 | 10-49
jumper | 2 | £0.16 | 40 | 22-0690 | rapid | £0.080 | 10-99
5x2 way female header RASPI | 1 | £0.10 | 20 | 19-0284 | rapid | £0.100 | 10-99
Capacitors
100nf | 7 | £0.07 | 140 | 08-0235 | rapid | £0.010 | 100-999
22pf | 2 | £0.02 | 40 | 08-0046 | rapid | £0.012 | 10-99
10uf | 6 | £0.10 | 120 | 11-0825 | rapid | £0.017 | 100-9999
Resistors
470k 5% | 8 | £0.05 | 160 | 62-0434 | rapid | £0.006 | 100 | £4.59 for box of 1000 or £3.63 for 5000
10k 5% | 3 | £0.02 | 60 | 62-0394 | rapid | £0.006 | 100
10k 1% | 1 | £0.01 | 20 | 62-3474 | rapid | £0.012 | 100 | £7.18 for box of 1000 or £3.63 for 5000
4.7k 5% | 1 | £0.01 | 20 | 62-0386 | rapid | £0.006 | 100
100k | 1 | £0.01 | 20 | 62-0418 | rapid | £0.006 | 100
100R 5% | 1 | £0.01 | 20 | 62-0346 | rapid | £0.006 | 100
CT burden resistors 22R | 3 | £0.04 | 60 | 62-3426 | rapid | £0.012 | 100
CT burden resistors 100R | 3 | £0.04 | 60 | 62-3426 | rapid | £0.012 | 100
120K | 1 | £0.01 | 20 | 62-3500 | rapid | £0.012 | 100
5k6 | 1 | £0.01 | 20 | 62-0388 | rapid | £0.006 | 100
Other
16 Mhz crystal | 1 | £0.21 | 20 | 90-2378 | rapid | £0.212 | 1to24
atmega328 | 1 | £2.14 | 20 | 1715487 | farnell | £2.140 | 10-24
28pin DIL | 1 | £0.45 | 20 | 2445626 | farnell | £0.453 | 10-99
MCP1825S-3302 | 1 | £0.34 | 20 | 1331485 | farnell | £0.337 | 10-24
LED
MBUS meter reader
BC307 or other PNP, BC557:1:C,2:B,3:E | 1 | £0.04 | 20 | 2453805 | farnell | £0.040 | 5-249
BC337 or other NPN,BC547:1:C,2:B,3:E | 2 | £0.08 | 40 | 2453790 | farnell | £0.040 | 5-249
220k | 1 | £0.01 | 20 | 62-0426 | rapid | £0.006 | 100
33k | 1 | £0.01 | 20 |  | rapid | £0.006 | 100
39k | 1 | £0.01 | 20 | 62-0408 | rapid | £0.006 | 100
22k | 1 | £0.01 | 20 | 62-0402 | rapid | £0.006 | 100
3k3 | 1 | £0.01 | 20 | 62-0382 | rapid | £0.006 | 100
82r | 1 | £0.01 | 20 | 62-0344 | rapid | £0.006 | 100
1K | 2 | £0.01 | 40 | 62-0370 | rapid | £0.006 | 100
2 way header female | 4 | £0.14 | 80 | 19-0081 | rapid | £0.034 | 50-99
2 way headers | 4 | £0.08 | 80 | 1593411 | farnell | £0.020 | 100-499
5v to 24v boost converter | 1 | £2.20 | 20 |  | ebay/other | £1.990 | 1
MBUS meter reader cost |  | £2.59
Total Component cost |  | £15.39
PCB cost |  | £8.20
Enclosure
EmonTx v3 aluminium enclosure | 1 | £4.27 | 20 | EBS80 | Lincoln Binns | £4.270 | 10-49 | http://www.lincolnbinns.com/e-case-b/
Laser cut facia pack | 1 | £2.00 | 20 | recycled acrylic | custom | £2.000 | 1 | Custom guide price: Laser cut clear acrylic
Enclosure screws | 8 | £0.08 | 160 | 33-3415 | rapid | £0.010 | Pack of 100
Total enclosure cost |  | £6.35
Cost price (components, case and PCB) |  | £29.93
Cost price no case |  | £23.59

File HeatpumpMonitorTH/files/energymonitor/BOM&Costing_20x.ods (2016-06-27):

 |  |  | Batch Size
 |  |  | 20
Component name | Quantity | Cost | Quantity Batch | Product | Supplier | Unit cost | Price Quantity | Other notes
Heatpump monitor PCB | 1 | £8.20 | 20 |  | Ragworm |  | 20x
Connectors and headers
3.5mm CT jack sockets | 3 | £0.77 | 60 | 20-0157 | rapid | £0.256 | 25-99
2.1mm DC ACAC socket | 1 | £0.19 | 20 | 20-0970 | rapid | £0.190 | 10-99
3 Way 3.5mm terminal block | 1 | £0.13 | 20 | 21-3001 | rapid | £0.134 | 100-500
USB mini | 1 | £0.75 | 20 | 565790511 | farnell | £0.745 | 1-24
ESP-12 | 1 | £2.00 | 20 | ESP12 | ebay/other | £2.000 | 1
2 way headers | 3 | £0.06 | 60 | 1593411 | farnell | £0.020 | 100-499
6 way headers | 2 | £0.52 | 40 | 1593415 | farnell | £0.261 | 10-49
3 way header | 1 | £0.07 | 20 | 1593412 | farnell | £0.070 | 50-99
jumper | 3 | £0.24 | 60 | 22-0690 | rapid | £0.080 | 10-99
5x2 way female header RASPI | 1 | £0.10 | 20 | 19-0284 | rapid | £0.100 | 10-99
Capacitors
100nf | 7 | £0.07 | 140 | 08-0235 | rapid | £0.010 | 100-999
22pf | 2 | £0.02 | 40 | 08-0046 | rapid | £0.012 | 10-99
10uf | 5 | £0.09 | 100 | 11-0825 | rapid | £0.017 | 100-9999
1u | 1 | £0.04 | 20 | 11-0855 | rapid | £0.039 | 10-99
47u | 1 | £0.05 | 20 | 11-0835 | rapid | £0.051 | 10-99
Resistors
470k 5% | 8 | £0.05 | 160 | 62-0434 | rapid | £0.006 | 100 | £4.59 for box of 1000 or £3.63 for 5000
10k 5% | 3 | £0.02 | 60 | 62-0394 | rapid | £0.006 | 100
or 10k 1% | 1 | £0.01 | 20 | 62-3474 | rapid | £0.012 | 100 | £7.18 for box of 1000 or £3.63 for 5000
4.7k 5% | 1 | £0.01 | 20 | 62-0386 | rapid | £0.006 | 100
100k | 1 | £0.01 | 20 | 62-0418 | rapid | £0.006 | 100
100R 5% | 1 | £0.01 | 20 | 62-0346 | rapid | £0.006 | 100
CT burden resistors 22R or 100R | 3 | £0.04 | 60 | 62-3426 | rapid | £0.012 | 100
120K | 1 | £0.01 | 20 | 62-3500 | rapid | £0.012 | 100
5k6 | 1 | £0.01 | 20 | 62-0388 | rapid | £0.006 | 100
56r | 1 | £0.01 | 20 | 62-0340 | rapid | £0.006 | 100
Other
16 Mhz crystal | 1 | £0.21 | 20 | 90-2378 | rapid | £0.212 | 1to24
1N4148 or 1N4001? | 1 | £0.01 | 20 | 50-0381 | rapid | £0.014 | 50-99
atmega328 | 1 | £2.14 | 20 | 1715487 | farnell | £2.140 | 10-24
28pin DIL | 1 | £0.45 | 20 | 2445626 | farnell | £0.453 | 10-99
MCP1702 (3.3V) | 1 | £0.34 | 20 | 1331485 | farnell | £0.337 | 10-24
LED
Total Component cost |  | £8.42
PCB cost |  | £8.20
Enclosure
EmonTx v3 aluminium enclosure | 1 | £4.27 | 20 | EBS80 | Lincoln Binns | £4.270 | 10-49 | http://www.lincolnbinns.com/e-case-b/
Laser cut facia pack | 1 | £2.00 | 20 | recycled acrylic | custom | £2.000 | 1 | Custom guide price: Laser cut clear acrylic
Enclosure screws | 8 | £0.08 | 160 | 33-3415 | rapid | £0.010 | Pack of 100
Total enclosure cost |  | £6.35
Cost price (components, case and PCB) |  | £22.96
Cost price no case |  | £16.62

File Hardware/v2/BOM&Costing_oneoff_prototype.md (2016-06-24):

## Example costing and BOM for Heatpump Monitor

### One off prototype

The following outlines example one-off or low volume cost price costing for the Heatpump Monitor. 

**Total £53.22 ex VAT** including **£28.93 ex VAT** prototype one-off PCB from [Ragworm](http://ragworm.eu) (100mm x 80mm PCB standard pricing in one-off - £34.72 inc VAT). Total £63.86 including VAT (20%) + misc shipping costs to do one-off prototype/DIY.

See [BOM&Costing_1x.ods](BOM&Costing_1x.ods) 

### 20x batch

A batch of 20x heatpump monitor boards start to give significant savings on the PCB cost and a couple of the other components, the cost price drops to £29.61 ex VAT in these quantities. 

See [BOM&Costing_20x.ods](BOM&Costing_20x.ods) 

### Custom OEM

Some of the components in the heatpump monitor are shared with other OpenEnergyMonitor units. Because we order these in much larger quantities we are able to get a lower price on some items. This drops the cost price to near £26 ex VAT.

The cost price of the heatpump monitor would be less if the PCB was ordered in larger quantities. Ordering in 50x would reduce the cost price by about £3, ordering in several hundred would reduce the cost price by about £6.

### Sale price

Following the advice of other open hardware projects the sale price we typically charge is around 2.0-2.3x the cost price for OpenEnergyMonitor's main products. There's a good series of articles on pricing and other key considerations for maker businesses here: http://blog.ponoko.com/2010/11/16/ten-rules-for-maker-businesses-by-wireds-chris-anderson-%E2%80%94-rule-1.

At a sale price of 2.0x cost price the heatpump monitor kit costs £26 x 2.0 = £52 ex VAT (£62.40 inc VAT). Its perhaps interesting that this price is very similar to the one off prototype cost.

### One off prototype example:

**All pricing below is ex VAT**

<table cellspacing="0" border="0">
	<colgroup width="273"></colgroup>
	<colgroup span="3" width="85"></colgroup>
	<colgroup width="110"></colgroup>
	<colgroup width="116"></colgroup>
	<colgroup span="2" width="85"></colgroup>
	<colgroup width="123"></colgroup>
	<colgroup width="182"></colgroup>
	<colgroup span="2" width="85"></colgroup>
	<tr>
		<td height="17" align="left"><b>Component name</b></td>
		<td align="center"><b>Quantity</b></td>
		<td align="center"><b>Cost</b></td>
		<td align="center"><b><br></b></td>
		<td align="center"><b>Product</b></td>
		<td align="center"><b>Supplier</b></td>
		<td align="center"><b>Unit cost</b></td>
		<td align="center"><b>VAT</b></td>
		<td align="center"><b>Price Quantity</b></td>
		<td align="center"><b>Minimum Order Quantity</b></td>
		<td align="center"><b><br></b></td>
		<td align="left"><b>Other notes</b></td>
	</tr>
	<tr>
		<td height="17" align="left"><b><br></b></td>
		<td align="center"><br></td>
		<td align="center"><br></td>
		<td align="center"><br></td>
		<td align="center"><br></td>
		<td align="center"><br></td>
		<td align="center"><br></td>
		<td align="center"><br></td>
		<td align="center"><br></td>
		<td align="center"><br></td>
		<td align="center"><br></td>
		<td align="left"><br></td>
	</tr>
	<tr>
		<td height="17" align="left"><b>Heatpump monitor PCB</b></td>
		<td align="center" sdval="1" sdnum="2057;">1</td>
		<td align="center" sdval="28.93" sdnum="2057;0;[$£-809]#,##0.00;[RED]-[$£-809]#,##0.00">£28.93</td>
		<td align="center"><br></td>
		<td align="center"><br></td>
		<td align="center">Ragworm</td>
		<td align="center"><br></td>
		<td align="center"><br></td>
		<td align="center" sdval="1" sdnum="2057;">1</td>
		<td align="center" sdval="1" sdnum="2057;">1</td>
		<td align="center"><br></td>
		<td align="left">One off prototype cost</td>
	</tr>
	<tr>
		<td height="17" align="left"><br></td>
		<td align="center"><br></td>
		<td align="center" sdnum="2057;0;[$£-809]#,##0.00;[RED]-[$£-809]#,##0.00"><br></td>
		<td align="center"><br></td>
		<td align="center"><br></td>
		<td align="center"><br></td>
		<td align="center"><br></td>
		<td align="center"><br></td>
		<td align="center"><br></td>
		<td align="center"><br></td>
		<td align="center"><br></td>
		<td align="left"><br></td>
	</tr>
	<tr>
		<td height="17" align="left"><b>Connectors and headers</b></td>
		<td align="center"><br></td>
		<td align="center" sdnum="2057;0;[$£-809]#,##0.00;[RED]-[$£-809]#,##0.00"><br></td>
		<td align="center"><br></td>
		<td align="center"><br></td>
		<td align="center"><br></td>
		<td align="center"><br></td>
		<td align="center"><br></td>
		<td align="center"><br></td>
		<td align="center"><br></td>
		<td align="center"><br></td>
		<td align="left"><br></td>
	</tr>
	<tr>
		<td height="17" align="left">3.5mm CT jack sockets</td>
		<td align="center" sdval="3" sdnum="2057;">3</td>
		<td align="center" sdval="1.038" sdnum="2057;0;[$£-809]#,##0.00;[RED]-[$£-809]#,##0.00">£1.04</td>
		<td align="center"><br></td>
		<td align="center">20-0157</td>
		<td align="center">rapid</td>
		<td align="center" sdval="0.346" sdnum="2057;0;[$£-809]#,##0.000;[RED]-[$£-809]#,##0.000">£0.346</td>
		<td align="center"><br></td>
		<td align="center">1-24</td>
		<td align="center" sdval="1" sdnum="2057;">1</td>
		<td align="center"><br></td>
		<td align="left"><br></td>
	</tr>
	<tr>
		<td height="17" align="left">2.1mm DC ACAC socket</td>
		<td align="center" sdval="1" sdnum="2057;">1</td>
		<td align="center" sdval="0.19" sdnum="2057;0;[$£-809]#,##0.00;[RED]-[$£-809]#,##0.00">£0.19</td>
		<td align="center"><br></td>
		<td align="center">20-0970</td>
		<td align="center">rapid</td>
		<td align="center" sdval="0.19" sdnum="2057;0;[$£-809]#,##0.000;[RED]-[$£-809]#,##0.000">£0.190</td>
		<td align="center"><br></td>
		<td align="center">10-99</td>
		<td align="center" sdval="10" sdnum="2057;">10</td>
		<td align="center"><br></td>
		<td align="left"><br></td>
	</tr>
	<tr>
		<td height="17" align="left">3 Way 3.5mm terminal block</td>
		<td align="center" sdval="9" sdnum="2057;">9</td>
		<td align="center" sdval="1.71" sdnum="2057;0;[$£-809]#,##0.00;[RED]-[$£-809]#,##0.00">£1.71</td>
		<td align="center"><br></td>
		<td align="center">21-3001</td>
		<td align="center">rapid</td>
		<td align="center" sdval="0.19" sdnum="2057;0;[$£-809]#,##0.000;[RED]-[$£-809]#,##0.000">£0.190</td>
		<td align="center"><br></td>
		<td align="center">10-99</td>
		<td align="center" sdval="10" sdnum="2057;">10</td>
		<td align="center"><br></td>
		<td align="left"><br></td>
	</tr>
	<tr>
		<td height="17" align="left">USB mini</td>
		<td align="center" sdval="1" sdnum="2057;">1</td>
		<td align="center" sdval="0.745" sdnum="2057;0;[$£-809]#,##0.00;[RED]-[$£-809]#,##0.00">£0.75</td>
		<td align="center"><br></td>
		<td align="center" sdval="565790511" sdnum="2057;">565790511</td>
		<td align="center">farnell</td>
		<td align="center" sdval="0.745" sdnum="2057;0;[$£-809]#,##0.000;[RED]-[$£-809]#,##0.000">£0.745</td>
		<td align="center"><br></td>
		<td align="center">1-24</td>
		<td align="center" sdval="1" sdnum="2057;">1</td>
		<td align="center"><br></td>
		<td align="left"><br></td>
	</tr>
	<tr>
		<td height="17" align="left">ESP-12</td>
		<td align="center" sdval="1" sdnum="2057;">1</td>
		<td align="center" sdval="2" sdnum="2057;0;[$£-809]#,##0.00;[RED]-[$£-809]#,##0.00">£2.00</td>
		<td align="center"><br></td>
		<td align="center">ESP12</td>
		<td align="center">Ebay</td>
		<td align="center" sdval="2" sdnum="2057;0;[$£-809]#,##0.000;[RED]-[$£-809]#,##0.000">£2.000</td>
		<td align="center"><br></td>
		<td align="center" sdval="1" sdnum="2057;">1</td>
		<td align="center" sdval="1" sdnum="2057;">1</td>
		<td align="center"><br></td>
		<td align="left">UK distributor</td>
	</tr>
	<tr>
		<td height="17" align="left">RFM69</td>
		<td align="center" sdval="1" sdnum="2057;">1</td>
		<td align="center" sdval="3.2" sdnum="2057;0;[$£-809]#,##0.00;[RED]-[$£-809]#,##0.00">£3.20</td>
		<td align="center"><br></td>
		<td align="center">RFM69</td>
		<td align="center">Ebay</td>
		<td align="center" sdval="3.2" sdnum="2057;0;[$£-809]#,##0.000;[RED]-[$£-809]#,##0.000">£3.200</td>
		<td align="center"><br></td>
		<td align="center" sdval="1" sdnum="2057;">1</td>
		<td align="center" sdval="1" sdnum="2057;">1</td>
		<td align="center"><br></td>
		<td align="left">UK distributor</td>
	</tr>
	<tr>
		<td height="17" align="left">2 way headers</td>
		<td align="center" sdval="3" sdnum="2057;">3</td>
		<td align="center" sdval="0.0609" sdnum="2057;0;[$£-809]#,##0.00;[RED]-[$£-809]#,##0.00">£0.06</td>
		<td align="center"><br></td>
		<td align="center" sdval="1593411" sdnum="2057;">1593411</td>
		<td align="center">farnell</td>
		<td align="center" sdval="0.0203" sdnum="2057;0;[$£-809]#,##0.000;[RED]-[$£-809]#,##0.000">£0.020</td>
		<td align="center"><br></td>
		<td align="center">100-499</td>
		<td align="center" sdval="100" sdnum="2057;">100</td>
		<td align="center"><br></td>
		<td align="left"><br></td>
	</tr>
	<tr>
		<td height="17" align="left">6 way headers</td>
		<td align="center" sdval="2" sdnum="2057;">2</td>
		<td align="center" sdval="0.522" sdnum="2057;0;[$£-809]#,##0.00;[RED]-[$£-809]#,##0.00">£0.52</td>
		<td align="center"><br></td>
		<td align="center" sdval="1593415" sdnum="2057;">1593415</td>
		<td align="center">farnell</td>
		<td align="center" sdval="0.261" sdnum="2057;0;[$£-809]#,##0.000;[RED]-[$£-809]#,##0.000">£0.261</td>
		<td align="center"><br></td>
		<td align="center">10-49</td>
		<td align="center" sdval="10" sdnum="2057;">10</td>
		<td align="center"><br></td>
		<td align="left"><br></td>
	</tr>
	<tr>
		<td height="17" align="left">3 way header</td>
		<td align="center" sdval="1" sdnum="2057;">1</td>
		<td align="center" sdval="0.0701" sdnum="2057;0;[$£-809]#,##0.00;[RED]-[$£-809]#,##0.00">£0.07</td>
		<td align="center"><br></td>
		<td align="center" sdval="1593412" sdnum="2057;">1593412</td>
		<td align="center">farnell</td>
		<td align="center" sdval="0.0701" sdnum="2057;0;[$£-809]#,##0.000;[RED]-[$£-809]#,##0.000">£0.070</td>
		<td align="center"><br></td>
		<td align="center">50-99</td>
		<td align="center" sdval="50" sdnum="2057;">50</td>
		<td align="center"><br></td>
		<td align="left"><br></td>
	</tr>
	<tr>
		<td height="17" align="left"><br></td>
		<td align="center"><br></td>
		<td align="center" sdnum="2057;0;[$£-809]#,##0.00;[RED]-[$£-809]#,##0.00"><br></td>
		<td align="center"><br></td>
		<td align="center"><br></td>
		<td align="center"><br></td>
		<td align="center" sdnum="2057;0;[$£-809]#,##0.000;[RED]-[$£-809]#,##0.000"><br></td>
		<td align="center"><br></td>
		<td align="center"><br></td>
		<td align="center"><br></td>
		<td align="center"><br></td>
		<td align="left"><br></td>
	</tr>
	<tr>
		<td height="17" align="left">jumper</td>
		<td align="center" sdval="3" sdnum="2057;">3</td>
		<td align="center" sdval="0.24" sdnum="2057;0;[$£-809]#,##0.00;[RED]-[$£-809]#,##0.00">£0.24</td>
		<td align="center"><br></td>
		<td align="center">22-0690</td>
		<td align="center">rapid</td>
		<td align="center" sdval="0.08" sdnum="2057;0;[$£-809]#,##0.000;[RED]-[$£-809]#,##0.000">£0.080</td>
		<td align="center"><br></td>
		<td align="center">10-99</td>
		<td align="center" sdval="10" sdnum="2057;">10</td>
		<td align="center"><br></td>
		<td align="left"><br></td>
	</tr>
	<tr>
		<td height="17" align="left">5x2 way female header RASPI</td>
		<td align="center" sdval="1" sdnum="2057;">1</td>
		<td align="center" sdval="0.1" sdnum="2057;0;[$£-809]#,##0.00;[RED]-[$£-809]#,##0.00">£0.10</td>
		<td align="center"><br></td>
		<td align="center">19-0284</td>
		<td align="center">rapid</td>
		<td align="center" sdval="0.1" sdnum="2057;0;[$£-809]#,##0.000;[RED]-[$£-809]#,##0.000">£0.100</td>
		<td align="center"><br></td>
		<td align="center">10-99</td>
		<td align="center" sdval="10" sdnum="2057;">10</td>
		<td align="center"><br></td>
		<td align="left"><br></td>
	</tr>
	<tr>
		<td height="17" align="left"><br></td>
		<td align="center"><br></td>
		<td align="center" sdnum="2057;0;[$£-809]#,##0.00;[RED]-[$£-809]#,##0.00"><br></td>
		<td align="center"><br></td>
		<td align="center"><br></td>
		<td align="center"><br></td>
		<td align="center" sdnum="2057;0;[$£-809]#,##0.000;[RED]-[$£-809]#,##0.000"><br></td>
		<td align="center"><br></td>
		<td align="center"><br></td>
		<td align="center"><br></td>
		<td align="center"><br></td>
		<td align="left"><br></td>
	</tr>
	<tr>
		<td height="17" align="left"><b>Capacitors</b></td>
		<td align="center"><br></td>
		<td align="center" sdnum="2057;0;[$£-809]#,##0.00;[RED]-[$£-809]#,##0.00"><br></td>
		<td align="center"><br></td>
		<td align="center"><br></td>
		<td align="center"><br></td>
		<td align="center" sdnum="2057;0;[$£-809]#,##0.000;[RED]-[$£-809]#,##0.000"><br></td>
		<td align="center"><br></td>
		<td align="center"><br></td>
		<td align="center"><br></td>
		<td align="center"><br></td>
		<td align="left"><br></td>
	</tr>
	<tr>
		<td height="17" align="left">100nf</td>
		<td align="center" sdval="7" sdnum="2057;">7</td>
		<td align="center" sdval="0.1554" sdnum="2057;0;[$£-809]#,##0.00;[RED]-[$£-809]#,##0.00">£0.16</td>
		<td align="center"><br></td>
		<td align="center">08-0235</td>
		<td align="center">rapid</td>
		<td align="center" sdval="0.0222" sdnum="2057;0;[$£-809]#,##0.000;[RED]-[$£-809]#,##0.000">£0.022</td>
		<td align="center"><br></td>
		<td align="center">10-99</td>
		<td align="center" sdval="10" sdnum="2057;">10</td>
		<td align="center"><br></td>
		<td align="left"><br></td>
	</tr>
	<tr>
		<td height="17" align="left">22pf</td>
		<td align="center" sdval="2" sdnum="2057;">2</td>
		<td align="center" sdval="0.0244" sdnum="2057;0;[$£-809]#,##0.00;[RED]-[$£-809]#,##0.00">£0.02</td>
		<td align="center"><br></td>
		<td align="center">08-0046</td>
		<td align="center">rapid</td>
		<td align="center" sdval="0.0122" sdnum="2057;0;[$£-809]#,##0.000;[RED]-[$£-809]#,##0.000">£0.012</td>
		<td align="center"><br></td>
		<td align="center">10-99</td>
		<td align="center" sdval="10" sdnum="2057;">10</td>
		<td align="center"><br></td>
		<td align="left"><br></td>
	</tr>
	<tr>
		<td height="17" align="left">10uf</td>
		<td align="center" sdval="5" sdnum="2057;">5</td>
		<td align="center" sdval="0.22" sdnum="2057;0;[$£-809]#,##0.00;[RED]-[$£-809]#,##0.00">£0.22</td>
		<td align="center"><br></td>
		<td align="center">11-0825</td>
		<td align="center">rapid</td>
		<td align="center" sdval="0.044" sdnum="2057;0;[$£-809]#,##0.000;[RED]-[$£-809]#,##0.000">£0.044</td>
		<td align="center"><br></td>
		<td align="center">1to9</td>
		<td align="center" sdval="1" sdnum="2057;">1</td>
		<td align="center"><br></td>
		<td align="left"><br></td>
	</tr>
	<tr>
		<td height="17" align="left">1u</td>
		<td align="center" sdval="1" sdnum="2057;">1</td>
		<td align="center" sdval="0.06" sdnum="2057;0;[$£-809]#,##0.00;[RED]-[$£-809]#,##0.00">£0.06</td>
		<td align="center"><br></td>
		<td align="center">11-0855</td>
		<td align="center">rapid</td>
		<td align="center" sdval="0.06" sdnum="2057;0;[$£-809]#,##0.000;[RED]-[$£-809]#,##0.000">£0.060</td>
		<td align="center"><br></td>
		<td align="center">1to9</td>
		<td align="center" sdval="1" sdnum="2057;">1</td>
		<td align="center"><br></td>
		<td align="left"><br></td>
	</tr>
	<tr>
		<td height="17" align="left">47u</td>
		<td align="center" sdval="1" sdnum="2057;">1</td>
		<td align="center" sdval="0.068" sdnum="2057;0;[$£-809]#,##0.00;[RED]-[$£-809]#,##0.00">£0.07</td>
		<td align="center"><br></td>
		<td align="center">11-0835</td>
		<td align="center">rapid</td>
		<td align="center" sdval="0.068" sdnum="2057;0;[$£-809]#,##0.000;[RED]-[$£-809]#,##0.000">£0.068</td>
		<td align="center"><br></td>
		<td align="center">1to9</td>
		<td align="center" sdval="1" sdnum="2057;">1</td>
		<td align="center"><br></td>
		<td align="left"><br></td>
	</tr>
	<tr>
		<td height="17" align="left"><br></td>
		<td align="center"><br></td>
		<td align="center" sdnum="2057;0;[$£-809]#,##0.00;[RED]-[$£-809]#,##0.00"><br></td>
		<td align="center"><br></td>
		<td align="center"><br></td>
		<td align="center"><br></td>
		<td align="center" sdnum="2057;0;[$£-809]#,##0.000;[RED]-[$£-809]#,##0.000"><br></td>
		<td align="center"><br></td>
		<td align="center"><br></td>
		<td align="center"><br></td>
		<td align="center"><br></td>
		<td align="left"><br></td>
	</tr>
	<tr>
		<td height="17" align="left"><b>Resistors</b></td>
		<td align="center"><br></td>
		<td align="center" sdnum="2057;0;[$£-809]#,##0.00;[RED]-[$£-809]#,##0.00"><br></td>
		<td align="center"><br></td>
		<td align="center"><br></td>
		<td align="center"><br></td>
		<td align="center" sdnum="2057;0;[$£-809]#,##0.000;[RED]-[$£-809]#,##0.000"><br></td>
		<td align="center"><br></td>
		<td align="center"><br></td>
		<td align="center"><br></td>
		<td align="center"><br></td>
		<td align="left"><br></td>
	</tr>
	<tr>
		<td height="17" align="left">470k 5%</td>
		<td align="center" sdval="8" sdnum="2057;">8</td>
		<td align="center" sdval="0.0496" sdnum="2057;0;[$£-809]#,##0.00;[RED]-[$£-809]#,##0.00">£0.05</td>
		<td align="center"><br></td>
		<td align="center">62-0434</td>
		<td align="center">rapid</td>
		<td align="center" sdval="0.0062" sdnum="2057;0;[$£-809]#,##0.000;[RED]-[$£-809]#,##0.000">£0.006</td>
		<td align="center"><br></td>
		<td align="center" sdval="100" sdnum="2057;">100</td>
		<td align="center">pack of 100</td>
		<td align="center"><br></td>
		<td align="left">£4.59 for box of 1000 or £3.63 for 5000</td>
	</tr>
	<tr>
		<td height="17" align="left">10k 5%</td>
		<td align="center" sdval="4" sdnum="2057;">4</td>
		<td align="center" sdval="0.0248" sdnum="2057;0;[$£-809]#,##0.00;[RED]-[$£-809]#,##0.00">£0.02</td>
		<td align="center"><br></td>
		<td align="center">62-0394</td>
		<td align="center">rapid</td>
		<td align="center" sdval="0.0062" sdnum="2057;0;[$£-809]#,##0.000;[RED]-[$£-809]#,##0.000">£0.006</td>
		<td align="center"><br></td>
		<td align="center" sdval="100" sdnum="2057;">100</td>
		<td align="center">pack of 100</td>
		<td align="center"><br></td>
		<td align="left"><br></td>
	</tr>
	<tr>
		<td height="17" align="left">or 10k 1%</td>
		<td align="center"><br></td>
		<td align="center" sdnum="2057;0;[$£-809]#,##0.00;[RED]-[$£-809]#,##0.00"><br></td>
		<td align="center"><br></td>
		<td align="center">62-3474</td>
		<td align="center">rapid</td>
		<td align="center" sdval="0.0118" sdnum="2057;0;[$£-809]#,##0.000;[RED]-[$£-809]#,##0.000">£0.012</td>
		<td align="center"><br></td>
		<td align="center" sdval="100" sdnum="2057;">100</td>
		<td align="center">pack of 100</td>
		<td align="center"><br></td>
		<td align="left">£7.18 for box of 1000 or £3.63 for 5000</td>
	</tr>
	<tr>
		<td height="17" align="left">4.7k 5%</td>
		<td align="center" sdval="1" sdnum="2057;">1</td>
		<td align="center" sdval="0.0062" sdnum="2057;0;[$£-809]#,##0.00;[RED]-[$£-809]#,##0.00">£0.01</td>
		<td align="center"><br></td>
		<td align="center">62-0386</td>
		<td align="center">rapid</td>
		<td align="center" sdval="0.0062" sdnum="2057;0;[$£-809]#,##0.000;[RED]-[$£-809]#,##0.000">£0.006</td>
		<td align="center"><br></td>
		<td align="center" sdval="100" sdnum="2057;">100</td>
		<td align="center">pack of 100</td>
		<td align="center"><br></td>
		<td align="left"><br></td>
	</tr>
	<tr>
		<td height="17" align="left">100k</td>
		<td align="center" sdval="1" sdnum="2057;">1</td>
		<td align="center" sdval="0.0062" sdnum="2057;0;[$£-809]#,##0.00;[RED]-[$£-809]#,##0.00">£0.01</td>
		<td align="center"><br></td>
		<td align="center">62-0418</td>
		<td align="center">rapid</td>
		<td align="center" sdval="0.0062" sdnum="2057;0;[$£-809]#,##0.000;[RED]-[$£-809]#,##0.000">£0.006</td>
		<td align="center"><br></td>
		<td align="center" sdval="100" sdnum="2057;">100</td>
		<td align="center">pack of 100</td>
		<td align="center"><br></td>
		<td align="left"><br></td>
	</tr>
	<tr>
		<td height="17" align="left">100R 5%</td>
		<td align="center" sdval="1" sdnum="2057;">1</td>
		<td align="center" sdval="0.0062" sdnum="2057;0;[$£-809]#,##0.00;[RED]-[$£-809]#,##0.00">£0.01</td>
		<td align="center"><br></td>
		<td align="center">62-0346</td>
		<td align="center">rapid</td>
		<td align="center" sdval="0.0062" sdnum="2057;0;[$£-809]#,##0.000;[RED]-[$£-809]#,##0.000">£0.006</td>
		<td align="center"><br></td>
		<td align="center" sdval="100" sdnum="2057;">100</td>
		<td align="center">pack of 100</td>
		<td align="center"><br></td>
		<td align="left"><br></td>
	</tr>
	<tr>
		<td height="17" align="left">CT burden resistors 22R or 100R</td>
		<td align="center" sdval="3" sdnum="2057;">3</td>
		<td align="center" sdval="0.0354" sdnum="2057;0;[$£-809]#,##0.00;[RED]-[$£-809]#,##0.00">£0.04</td>
		<td align="center"><br></td>
		<td align="center">62-3426</td>
		<td align="center">rapid</td>
		<td align="center" sdval="0.0118" sdnum="2057;0;[$£-809]#,##0.000;[RED]-[$£-809]#,##0.000">£0.012</td>
		<td align="center"><br></td>
		<td align="center" sdval="100" sdnum="2057;">100</td>
		<td align="center">pack of 100</td>
		<td align="center"><br></td>
		<td align="left"><br></td>
	</tr>
	<tr>
		<td height="17" align="left">120K</td>
		<td align="center" sdval="1" sdnum="2057;">1</td>
		<td align="center" sdval="0.0118" sdnum="2057;0;[$£-809]#,##0.00;[RED]-[$£-809]#,##0.00">£0.01</td>
		<td align="center"><br></td>
		<td align="center">62-3500</td>
		<td align="center">rapid</td>
		<td align="center" sdval="0.0118" sdnum="2057;0;[$£-809]#,##0.000;[RED]-[$£-809]#,##0.000">£0.012</td>
		<td align="center"><br></td>
		<td align="center" sdval="100" sdnum="2057;">100</td>
		<td align="center">pack of 100</td>
		<td align="center"><br></td>
		<td align="left"><br></td>
	</tr>
	<tr>
		<td height="17" align="left">5k6</td>
		<td align="center" sdval="1" sdnum="2057;">1</td>
		<td align="center" sdval="0.0062" sdnum="2057;0;[$£-809]#,##0.00;[RED]-[$£-809]#,##0.00">£0.01</td>
		<td align="center"><br></td>
		<td align="center">62-0388</td>
		<td align="center">rapid</td>
		<td align="center" sdval="0.0062" sdnum="2057;0;[$£-809]#,##0.000;[RED]-[$£-809]#,##0.000">£0.006</td>
		<td align="center"><br></td>
		<td align="center" sdval="100" sdnum="2057;">100</td>
		<td align="center">pack of 100</td>
		<td align="center"><br></td>
		<td align="left"><br></td>
	</tr>
	<tr>
		<td height="17" align="left">56r</td>
		<td align="center" sdval="1" sdnum="2057;">1</td>
		<td align="center" sdval="0.0062" sdnum="2057;0;[$£-809]#,##0.00;[RED]-[$£-809]#,##0.00">£0.01</td>
		<td align="center"><br></td>
		<td align="center">62-0340</td>
		<td align="center">rapid</td>
		<td align="center" sdval="0.0062" sdnum="2057;0;[$£-809]#,##0.000;[RED]-[$£-809]#,##0.000">£0.006</td>
		<td align="center"><br></td>
		<td align="center" sdval="100" sdnum="2057;">100</td>
		<td align="center">pack of 100</td>
		<td align="center"><br></td>
		<td align="left"><br></td>
	</tr>
	<tr>
		<td height="17" align="left"><br></td>
		<td align="center"><br></td>
		<td align="center" sdnum="2057;0;[$£-809]#,##0.00;[RED]-[$£-809]#,##0.00"><br></td>
		<td align="center"><br></td>
		<td align="center"><br></td>
		<td align="center"><br></td>
		<td align="center" sdnum="2057;0;[$£-809]#,##0.000;[RED]-[$£-809]#,##0.000"><br></td>
		<td align="center"><br></td>
		<td align="center"><br></td>
		<td align="center"><br></td>
		<td align="center"><br></td>
		<td align="left"><br></td>
	</tr>
	<tr>
		<td height="17" align="left"><b>Other</b></td>
		<td align="center"><br></td>
		<td align="center" sdnum="2057;0;[$£-809]#,##0.00;[RED]-[$£-809]#,##0.00"><br></td>
		<td align="center"><br></td>
		<td align="center"><br></td>
		<td align="center"><br></td>
		<td align="center" sdnum="2057;0;[$£-809]#,##0.000;[RED]-[$£-809]#,##0.000"><br></td>
		<td align="center"><br></td>
		<td align="center"><br></td>
		<td align="center"><br></td>
		<td align="center"><br></td>
		<td align="left"><br></td>
	</tr>
	<tr>
		<td height="17" align="left">16 Mhz crystal</td>
		<td align="center" sdval="1" sdnum="2057;">1</td>
		<td align="center" sdval="0.212" sdnum="2057;0;[$£-809]#,##0.00;[RED]-[$£-809]#,##0.00">£0.21</td>
		<td align="center"><br></td>
		<td align="center">90-2378</td>
		<td align="center">rapid</td>
		<td align="center" sdval="0.212" sdnum="2057;0;[$£-809]#,##0.000;[RED]-[$£-809]#,##0.000">£0.212</td>
		<td align="center"><br></td>
		<td align="center">1to24</td>
		<td align="center" sdval="1" sdnum="2057;">1</td>
		<td align="center"><br></td>
		<td align="left"><br></td>
	</tr>
	<tr>
		<td height="17" align="left">1N4148 or 1N4001?</td>
		<td align="center" sdval="1" sdnum="2057;">1</td>
		<td align="center" sdval="0.0144" sdnum="2057;0;[$£-809]#,##0.00;[RED]-[$£-809]#,##0.00">£0.01</td>
		<td align="center"><br></td>
		<td align="center">50-0381</td>
		<td align="center">rapid</td>
		<td align="center" sdval="0.0144" sdnum="2057;0;[$£-809]#,##0.000;[RED]-[$£-809]#,##0.000">£0.014</td>
		<td align="center"><br></td>
		<td align="center">50-99</td>
		<td align="center" sdval="50" sdnum="2057;">50</td>
		<td align="center"><br></td>
		<td align="left"><br></td>
	</tr>
	<tr>
		<td height="17" align="left">atmega328</td>
		<td align="center" sdval="1" sdnum="2057;">1</td>
		<td align="center" sdval="2.41" sdnum="2057;0;[$£-809]#,##0.00;[RED]-[$£-809]#,##0.00">£2.41</td>
		<td align="center"><br></td>
		<td align="center" sdval="1715487" sdnum="2057;">1715487</td>
		<td align="center">farnell</td>
		<td align="center" sdval="2.41" sdnum="2057;0;[$£-809]#,##0.000;[RED]-[$£-809]#,##0.000">£2.410</td>
		<td align="center"><br></td>
		<td align="center">1to9</td>
		<td align="center" sdval="1" sdnum="2057;">1</td>
		<td align="center"><br></td>
		<td align="left"><br></td>
	</tr>
	<tr>
		<td height="17" align="left">28pin DIL</td>
		<td align="center" sdval="1" sdnum="2057;">1</td>
		<td align="center" sdval="0.453" sdnum="2057;0;[$£-809]#,##0.00;[RED]-[$£-809]#,##0.00">£0.45</td>
		<td align="center"><br></td>
		<td align="center" sdval="2445626" sdnum="2057;">2445626</td>
		<td align="center">farnell</td>
		<td align="center" sdval="0.453" sdnum="2057;0;[$£-809]#,##0.000;[RED]-[$£-809]#,##0.000">£0.453</td>
		<td align="center"><br></td>
		<td align="center">10-99</td>
		<td align="center" sdval="10" sdnum="2057;">10</td>
		<td align="center"><br></td>
		<td align="left"><br></td>
	</tr>
	<tr>
		<td height="17" align="left">MCP1702 (3.3V)</td>
		<td align="center" sdval="1" sdnum="2057;">1</td>
		<td align="center" sdval="0.449" sdnum="2057;0;[$£-809]#,##0.00;[RED]-[$£-809]#,##0.00">£0.45</td>
		<td align="center"><br></td>
		<td align="center" sdval="1331485" sdnum="2057;">1331485</td>
		<td align="center">farnell</td>
		<td align="center" sdval="0.449" sdnum="2057;0;[$£-809]#,##0.000;[RED]-[$£-809]#,##0.000">£0.449</td>
		<td align="center"><br></td>
		<td align="center">1to9</td>
		<td align="center" sdval="1" sdnum="2057;">1</td>
		<td align="center"><br></td>
		<td align="left"><br></td>
	</tr>
	<tr>
		<td height="17" align="left">LED</td>
		<td align="center"><br></td>
		<td align="center" sdnum="2057;0;[$£-809]#,##0.00;[RED]-[$£-809]#,##0.00"><br></td>
		<td align="center"><br></td>
		<td align="center"><br></td>
		<td align="center"><br></td>
		<td align="center" sdnum="2057;0;[$£-809]#,##0.000;[RED]-[$£-809]#,##0.000"><br></td>
		<td align="center"><br></td>
		<td align="center"><br></td>
		<td align="center"><br></td>
		<td align="center"><br></td>
		<td align="left"><br></td>
	</tr>
	<tr>
		<td height="17" align="left"><br></td>
		<td align="center"><br></td>
		<td align="center" sdnum="2057;0;[$£-809]#,##0.00;[RED]-[$£-809]#,##0.00"><br></td>
		<td align="center"><br></td>
		<td align="center"><br></td>
		<td align="center"><br></td>
		<td align="center" sdnum="2057;0;[$£-809]#,##0.000;[RED]-[$£-809]#,##0.000"><br></td>
		<td align="center"><br></td>
		<td align="center"><br></td>
		<td align="center"><br></td>
		<td align="center"><br></td>
		<td align="left"><br></td>
	</tr>
	<tr>
		<td height="17" align="left"><b>MBUS meter reader</b></td>
		<td align="center"><br></td>
		<td align="center" sdnum="2057;0;[$£-809]#,##0.00;[RED]-[$£-809]#,##0.00"><br></td>
		<td align="center"><br></td>
		<td align="center"><br></td>
		<td align="center"><br></td>
		<td align="center" sdnum="2057;0;[$£-809]#,##0.000;[RED]-[$£-809]#,##0.000"><br></td>
		<td align="center"><br></td>
		<td align="center"><br></td>
		<td align="center"><br></td>
		<td align="center"><br></td>
		<td align="left"><br></td>
	</tr>
	<tr>
		<td height="17" align="left">BC307 or other PNP, BC557:1:C,2:B,3:E</td>
		<td align="center" sdval="1" sdnum="2057;">1</td>
		<td align="center" sdval="0.0401" sdnum="2057;0;[$£-809]#,##0.00;[RED]-[$£-809]#,##0.00">£0.04</td>
		<td align="center"><br></td>
		<td align="center" sdval="2453805" sdnum="2057;">2453805</td>
		<td align="center">farnell</td>
		<td align="center" sdval="0.0401" sdnum="2057;0;[$£-809]#,##0.000;[RED]-[$£-809]#,##0.000">£0.040</td>
		<td align="center"><br></td>
		<td align="center">5-249</td>
		<td align="center" sdval="5" sdnum="2057;">5</td>
		<td align="center"><br></td>
		<td align="left"><br></td>
	</tr>
	<tr>
		<td height="17" align="left">BC337 or other NPN,BC547:1:C,2:B,3:E</td>
		<td align="center" sdval="2" sdnum="2057;">2</td>
		<td align="center" sdval="0.0802" sdnum="2057;0;[$£-809]#,##0.00;[RED]-[$£-809]#,##0.00">£0.08</td>
		<td align="center"><br></td>
		<td align="center" sdval="2453790" sdnum="2057;">2453790</td>
		<td align="center">farnell</td>
		<td align="center" sdval="0.0401" sdnum="2057;0;[$£-809]#,##0.000;[RED]-[$£-809]#,##0.000">£0.040</td>
		<td align="center"><br></td>
		<td align="center">5-249</td>
		<td align="center" sdval="5" sdnum="2057;">5</td>
		<td align="center"><br></td>
		<td align="left"><br></td>
	</tr>
	<tr>
		<td height="17" align="left">220k</td>
		<td align="center" sdval="1" sdnum="2057;">1</td>
		<td align="center" sdval="0.00624" sdnum="2057;0;[$£-809]#,##0.00;[RED]-[$£-809]#,##0.00">£0.01</td>
		<td align="center"><br></td>
		<td align="center">62-0426</td>
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

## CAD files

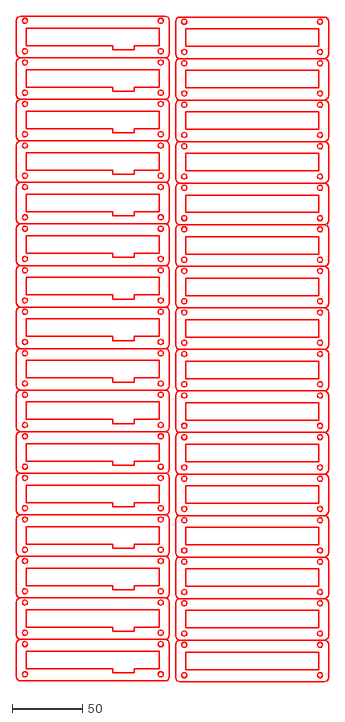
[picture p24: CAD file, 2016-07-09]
HeatpumpMonitorTH/Hardware/Fascia/TiledFascia.dxf
221.6 x 472.5

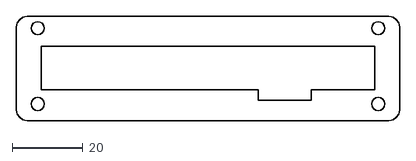
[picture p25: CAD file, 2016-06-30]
HeatpumpMonitorTH/Hardware/Fascia/Fascia2.dxf
108.5 x 29.5

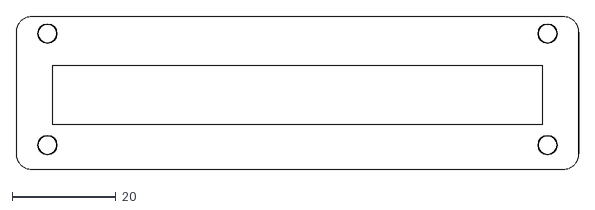
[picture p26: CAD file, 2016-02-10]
HeatpumpMonitorTH/Hardware/Fascia/Fascia.dxf
108.6 x 29.6

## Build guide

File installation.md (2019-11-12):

# Installation and setup

The following image shows the function of each connector:

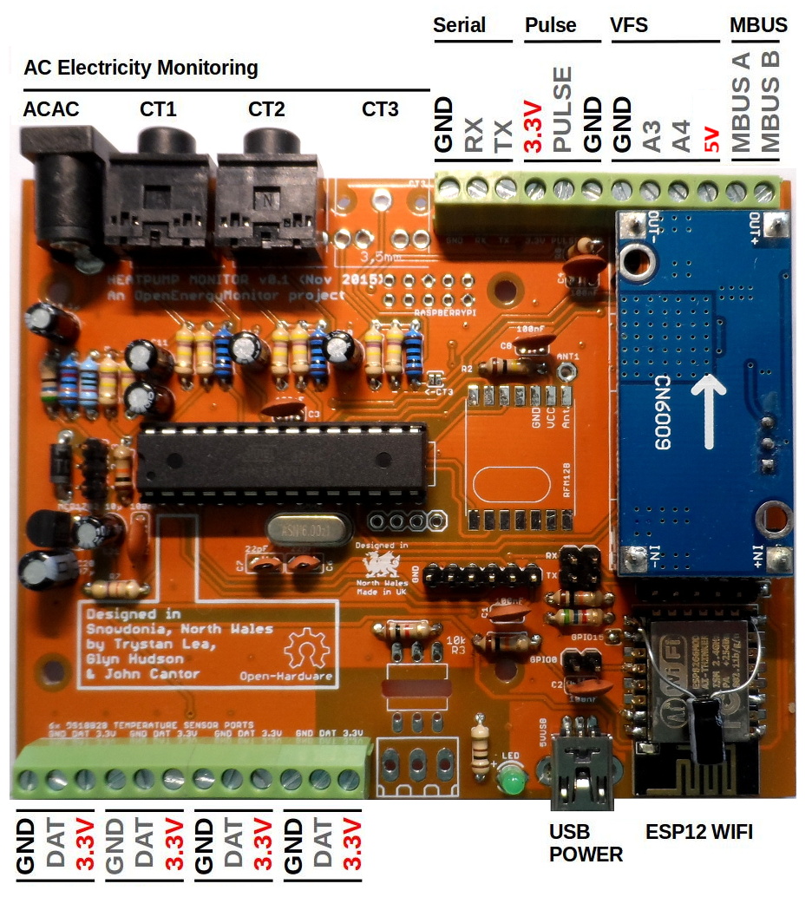
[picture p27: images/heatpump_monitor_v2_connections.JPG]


#### Note: Heatpump Dashboard naming convention

The heatpump dashboard available on energy.emoncms.org does not have a configuration interface, it instead just looks for feeds in the emoncms.org account with the following names:

- **heatpump_elec**: Heatpump electrical power in Watts
- **heatpump_elec_kwh**: Heatpump cumulative electricity consumption in kWh 
- **heatpump_heat**: Heatpump heat output in Watts
- **heatpump_heat_kwh**: Heatpump cumulative heat output in kWh
- **heatpump_flowT**: Heatpump central heating/DHW water flow temperature.
- **heatpump_returnT**: Heatpump central heating/DHW water return temperature.
- **outside_temperature**: Outside/Ambient temperature
- **DHW_cylinderT**: Hot Water Cylinder temperature

The minimum requirement for the heatpump dashboard is a cumulative kWh feed of heatpump electricity consumption named: **heatpump_elec_kwh**.

Beyond this addition of the further feeds just extends and improves the dashboard further.

### Electricity monitoring: IRDA Elster A100C Watt Hour reader

The Heatpump Monitor supports reading from the Irda port on Elster A100C energy meters using the [OpenEnergyMonitor pulse sensor](https://shop.openenergymonitor.com/optical-utility-meter-led-pulse-sensor/). This provides a convenient way of reading the actual watt hours as recorded on the meter avoiding errors that may be caused by a multitude of sources via the other optional methods.

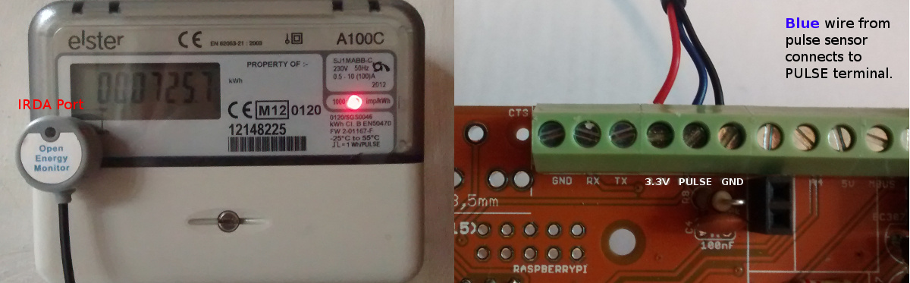
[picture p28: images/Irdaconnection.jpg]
IRDA Reader


Selection and use of the IRDA reader over pulse counting is done in the Heatpump Monitor firmware here:

[Firmware/Arduino/HeatpumpMonitor_AutoTemp/HeatpumpMonitor_AutoTemp.ino#L19](https://github.com/openenergymonitor/HeatpumpMonitor/blob/master/Firmware/Arduino/HeatpumpMonitor_AutoTemp/HeatpumpMonitor_AutoTemp.ino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)

Set ELSTER_IRDA_ENABLE to 1:

    #define ELSTER_IRDA_ENABLE 1
    
**When using the Elster IRDA meter reader the 100nF capacitor may need to be removed**

**Emoncms configuration**

See the [Software setup guide](https://github.com/openenergymonitor/HeatpumpMonitor/blob/master/software_setup.md) for automated setup method.

<table>
<tr><th>Input name</th><th>Input processing and feeds</th><th>Recommended feed name</th></tr>
<tr><td>PulseIRDA</td><td><b>Log to feed</b> record one standard feed with 'log to feed'.<br><b>Wh accumulator</b> record a second feed with the wh accumulator process, this process creates a feed where any data gaps are joined producing more reliable kwh graphs.</td><td>wh_accumulator: <b>heatpump_elec_kwh</b></td></tr>
</table>

### Electricity monitoring: Pulse counting

Many meters have pulse outputs, examples include: single phase and three phase electrical energy meters, Gas meters, Water meters. The pulse output may be a flashing LED or a switching relay (usually solid state) or both.

In the case of an electricity meter, a pulse output corresponds to a defined amount of energy passing through the meter (kWh/Wh). For single-phase domestic electricity meters (e.g. the Elster A100c) each pulse usually equals one Wh (1000 pulses per kWh).  With higher power meters (often three-phase), each pulse corresponds to a greater amount of energy e.g. 2, or even 10, Wh per pulse. 

The connection of the pulse counting sensor is exactly the same as in the Elster Irda meter reader connection above. The same OpenEnergyMonitor pulse sensor used for the Irda can be used for optical pulse counting when attached over the flashing red LED present on most meters. 

Alternatively wired pulse counting is also an option. For wired pulse counting two wires are needed one from the 3.3V supply terminal going to the meter and another switched pulse output coming back to the PULSE input terminal on the heatpump monitor.

When using the pulse counting input with wired pulse output meters such as an Elster A100C or Ampy single phase meter two additional components are needed to provide reliable pulse counting. A pull down resistor is needed across the pulse input (100k) and ground and then a 100nf capacitor is needed to filter any high frequency pulses outside the expected range. The footprint for these are now on the PCB just below the terminals.

For more information on pulse counting see the Building Blocks page: [Introduction to Pulse Counting](https://learn.openenergymonitor.org/electricity-monitoring/pulse-counting/introduction-to-pulse-counting)

The pulse counting input on the heatpump monitor is just a interrupt enabled digital input on the atmega328.

**Emoncms configuration**

<table>
<tr><th>Input name</th><th>Input processing and feeds</th><th>Recommended feed name</th></tr>
<tr><td>PulseIRDA</td><td><b>Log to feed</b> record one standard feed with 'log to feed'.<br><b>Wh accumulator</b> record a second feed with the wh accumulator process, this process creates a feed where any data gaps are joined producing more reliable kwh graphs.</td><td>wh_accumulator: <b>heatpump_elec_kwh</b></td></tr>
</table>

### Electricity monitoring: CT and AC-AC adapter

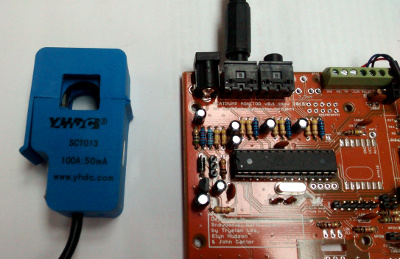
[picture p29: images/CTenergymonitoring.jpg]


In addition to the elster irda meter reader and pulse counting options the heatpump monitor also supports standard OpenEnergyMonitor CT and AC-AC Adapter based electricity monitoring. The AC-AC Adapter is required for voltage signal measurement and real power calculation which gives greater measurement accuracy.

CT Burden resistor sizing: The current range measurable by the CT based measurement is dependent on both the CT sensor used and the burden resistor size on the heat pump monitoring board. In order to obtain higher measurement resolution it is recommended to size the burden resistor to match closely the maximum rated electrical power input of the heat pump.

The included burden resistor in the heatpump monitor kit is 100 Ohms, this provides a AC power measurement range of **0 - 5.4 kW**. This provides ample range for many small domestic heatpumps. A smaller burden resistor can be used instead for larger measurement range at lower resolution. See Building Blocks guide [CT sensors - interfacing with arduino](https://learn.openenergymonitor.org/electricity-monitoring/ct-sensors/interface-with-arduino)

**Calibration and Accuracy**

The CT and AC-AC power measurement circuitry was designed for indicative power measurement, better than many home energy monitors available but less accurate than billing grade class 1 or 2 electricity meters. In order to draw reliable conclusions on heat pump COP performance it is recommended to use the Elster Irda Watt hour reader or pulse counting input in conjunction with a class 1 or 2 electricity meter for accumulated electricity consumption measurement. This can be in parallel with the CT based measurement which has the advantage of providing higher temporal resolution power readings useful when analysing heating runs in detail.

In order to confirm the accuracy of the heat pump monitor electricity measurement note down a manual meter reading from the heat pump kwh meter when the heat pump monitor is first powered up, note down the date and time of this reading. After a measurement period of around 1 week check the accumulated electricity consumption recorded by the heat pump monitor both from the pulse counting input, the CT sensors against the consumption as read manually on the kwh meter.

See [Building Blocks: Sources of error in the emontx voltage and current inputs](https://learn.openenergymonitor.org/electricity-monitoring/ctac/emontx-error-sources)

**Emoncms configuration**

<table>
<tr><th>Input name</th><th>Input processing and feeds</th><th>Recommended feed name</th></tr>
<tr><td>OEMct1</td><td><b>Log to feed</b> record one standard power feed with 'log to feed'.<br><b>power to kWh</b> record a second feed with the power to kwh process, this process creates a cumulative kWh feed from the power input.</td><td>log_to_feed: <b>heatpump_elec</b><br>power_to_kwh: <b>heatpump_elec_kwh</b></td></tr>
<tr><td>OEMct2</td><td><b>Log to feed</b> record one standard power feed with 'log to feed'.<br><b>power to kWh</b> record a second feed with the power to kwh process, this process creates a cumulative kWh feed from the power input.</td><td></td></tr>
<tr><td>OEMct1Wh</td><td><b>Wh accumulator</b> use the wh accumulator process to record the cumulative watt hour data in a feed where any data gaps are joined producing more reliable kwh graphs.</td><td>heatpump_elec_kwh</td></tr>
<tr><td>OEMct2Wh</td><td><b>Wh accumulator</b> use the wh accumulator process to record the cumulative watt hour data in a feed where any data gaps are joined producing more reliable kwh graphs.</td><td></td></tr>
</table>

### Heat metering: MBUS Kamstrup heat meter

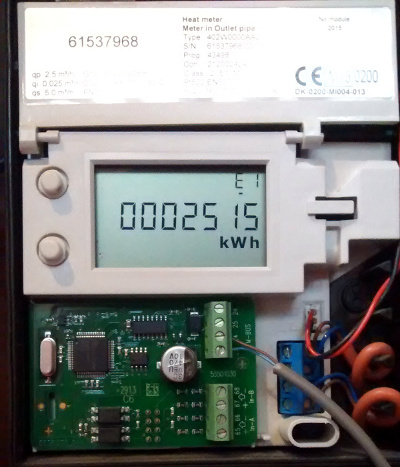
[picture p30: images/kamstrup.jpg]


A core feature of the heatpump monitor board is the MBUS meter reader and integrated firmware for reading heat metering data from Kamstrup Multical 402 heat meters. [https://www.kamstrup.com/en-en/products-solutions/thermal-energy-meters/multical-403](https://www.kamstrup.com/en-en/products-solutions/thermal-energy-meters/multical-403)

Ensure the heat pump monitor is un-powered before connection. Connect using 2-core wire the MBUS reader terminals (top-right) with the MBUS connection of your kamstrup heat meter. The polarity does not matter but care needs to be taken not to short the two wires as this may cause damage to the MBUS interface or card.

Ensure the blue voltage converter board is fitted and positioned with the arrow pointing upwards as shown in the diagram above. The output of the voltage converter should be nearest the MBUS terminal connections.

Once connected the heat pump monitor will auto detect the Kamstrup heat meter address and pass the polled data through without further configuration.

Troubleshooting: If the kamstrup meter data does not appear straight away, wait several minutes for the reader to rescan. The voltage across the MBUS reader terminals should be close to 34V.

**Emoncms configuration**

<table>
<tr><th>Input name</th><th>Input processing and feeds</th><th>Recommended feed name</th></tr>
<tr><td>KSflowT</td><td>Flow temperature (Celcius)<br><b>Log to feed</b> record to PHPFina feed at 10s interval.</td><td>heatpump_flowT</td></tr>
<tr><td>KSreturnT</td><td>Return temperature (Celcius)<br><b>Log to feed</b> record to PHPFina feed at 10s interval.</td><td>heatpump_returnT</td></tr>
<tr><td>KSdeltaT</td><td>Difference between flow and return temperature (Kelvin)<br><b>Log to feed</b> record to PHPFina feed at 10s interval.</td><td>heatpump_deltaT</td></tr>
<tr><td>KSflowrate</td><td>Water Flowrate (Litres/hour)<br><b>Log to feed</b> record to PHPFina feed at 10s interval.</td><td></td></tr>
<tr><td>KSheat</td><td>Heatpump heat output (Watts)<br><b>Log to feed</b> record to PHPFina feed at 10s interval.<br><b>Power to kWh</b> use the power to kwh process to generate a higher resolution kWh feed from the kamstrup power data to be used in parallel with the kWh reading from the kamstrup meter.</td><td>log_to_feed: <b>heatpump_heat</b><br>power_to_kwh: <b>heatpump_heat_kwh</b></td></tr>
<tr><td>KSkWh</td><td>Total cumulative kWh of heat measured by kamstrup (kWh)<br><b>Log to feed</b> record to PHPFina feed at 10s interval.</td><td>heatpump_heat_kwh</td></tr>
</table>

### Heat metering: VFS Flow meter (Sika or Grundfos)

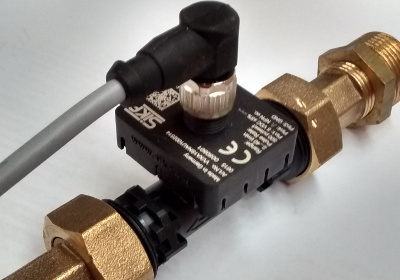
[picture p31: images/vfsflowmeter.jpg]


A Vortex Flow Sensor with an analog voltage output such as the Grundfos VFS range or Sika VFS range can be connected to the VFS terminals, top-right next to the MBUS reader terminals. There are two analog inputs on the VFS terminal that map to two 10bit ADC Channels on the Atmega328. For standard configuration use A3 for flowrate measurement and A4 for temperature measurement.

There are a multitude of VFS flow sensors each catering for different flow ranges, the calibration for the VFS sensor is set in the Heatpump monitor firmware here:

[Firmware/Arduino/HeatpumpMonitor_AutoTemp/HeatpumpMonitor_AutoTemp.ino#L52](https://github.com/openenergymonitor/HeatpumpMonitor/blob/master/Firmware/Arduino/HeatpumpMonitor_AutoTemp/HeatpumpMonitor_AutoTemp.ino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)

    // --------------------------------------------------
    // VFS config
    // --------------------------------------------------
    double VFS_maxflow          = 40.0;  // Litres/minute
    double VFS_maxflow_voltage  = 3.5;   // Volts
    double VFS_zeroflow_voltage = 0.25;  // Volts
    double VFS_maxtemp          = 100;   // Celcius
    double VFS_maxtemp_voltage  = 3.5;   // Volts
    double VFS_zerotemp_voltage = 0.5; // Volts
    
The calibration values to use here can be found the VFS sensor datasheet.

Testing is ongoing to verify the potential accuracy of heat measurement based on the VFS flowrate and DS18B20 based flow and return temperature readings.

**Emoncms configuration**

<table>
<tr><th>Input name</th><th>Input processing and feeds</th><th>Recommended feed name</th></tr>
<tr><td>VFSflowT</td><td>Flow temperature measured by temperature sensor in VFS flow meter.<br><b>Log to feed</b> record to PHPFina feed at 10s interval</td><td>heatpump_flowT</td></tr>
<tr><td>VFSflowrate</td><td>Flow rate in Litres/hour.<br><b>Log to feed</b> record to PHPFina feed at 10s interval.<br><b>Log to feed</b> record to PHPFina feed at 10s interval.</td></tr>
<tr><td>VFSheat</td><td>Heat output measured in Watts by VFS<br><b>Log to feed</b> record power to PHPFina feed at 10s interval.<br><b>Power to kWh</b> use the power to kwh process to calculate cumulative kWh feed</td><td>log_to_feed: <b>heatpump_heat</b><br>power_to_kwh: <b>heatpump_heat_kwh</b></td></tr>
</table>

### DS18B20 Temperature sensors

**Emoncms configuration**

Using the latest HeatpumpMonitor_AutoTemp firmware, DS18B20 temperature sensors are detected automatically and sent with a key/name that includes a unqiue ID so that removing a fautly sensor does not mix up the order. The naming is of the form: T[ID], T682.

These temperature inputs can then be named within emoncms to a more useful descriptive name.

## Power up

With the sensors connected as above and ATmega firmware configured as needed, the final step is to power up the unit and configure the WIFI.

**ATmega to ESP8266 jumper link** For data to be transfered from the ATmega microcontroller across to the ESP8266 module the jumper link labeled TX between both 6way UART headers needs to be linked across. This creates a serial link between both units. This jumper needs to be removed before programming either the ESP8266 module or the ATmega328.

### EmonESP Config

On first power up the ESP WIFI module will create a WIFI access point. Connect to this directly and once connected navigate to ip address 192.168.4.1 in your browser.

The EmonESP interface which looks much like this should appear:

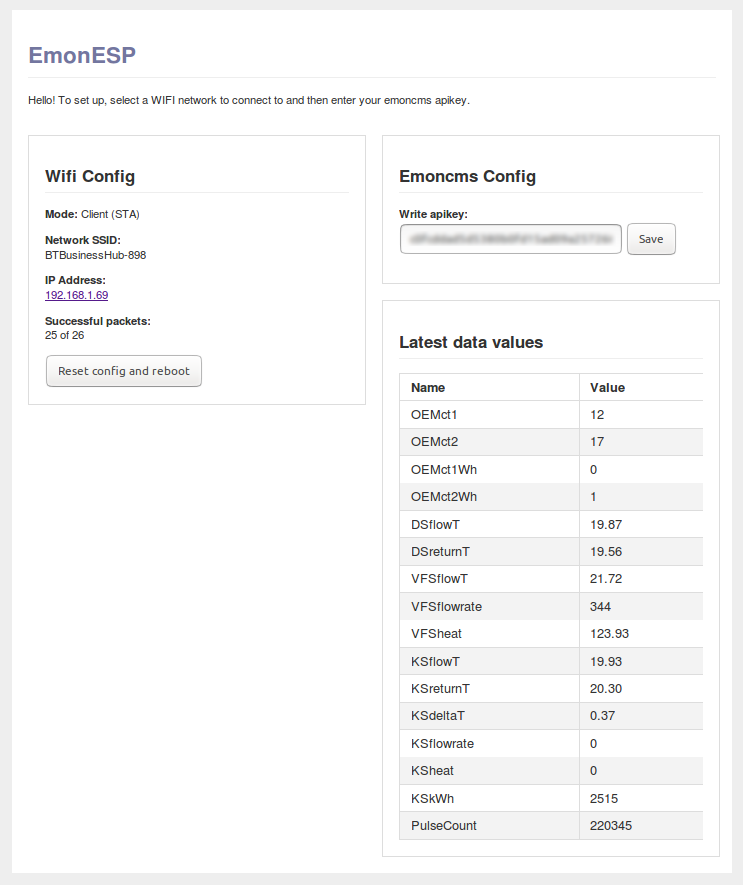
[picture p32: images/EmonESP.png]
EmonESP


Use this interface to scan and connect to the WIFI network you wish to connect to. Once connected the IP address of the heatpump monitor will be shown. Navigate to this IP address and switch over from the WIFI access point to your local network. 

Next enter you emoncms.org account apikey. If data is appearing in the Latest data values pane and the emoncms apikey is set you should now see a set of inputs appear on your emoncms.org inputs page.

### Emoncms Inputs

The input list will look much like this but without the configured feeds. Use the emoncms configuration details above to configure emoncms to record the heatpump monitor data.

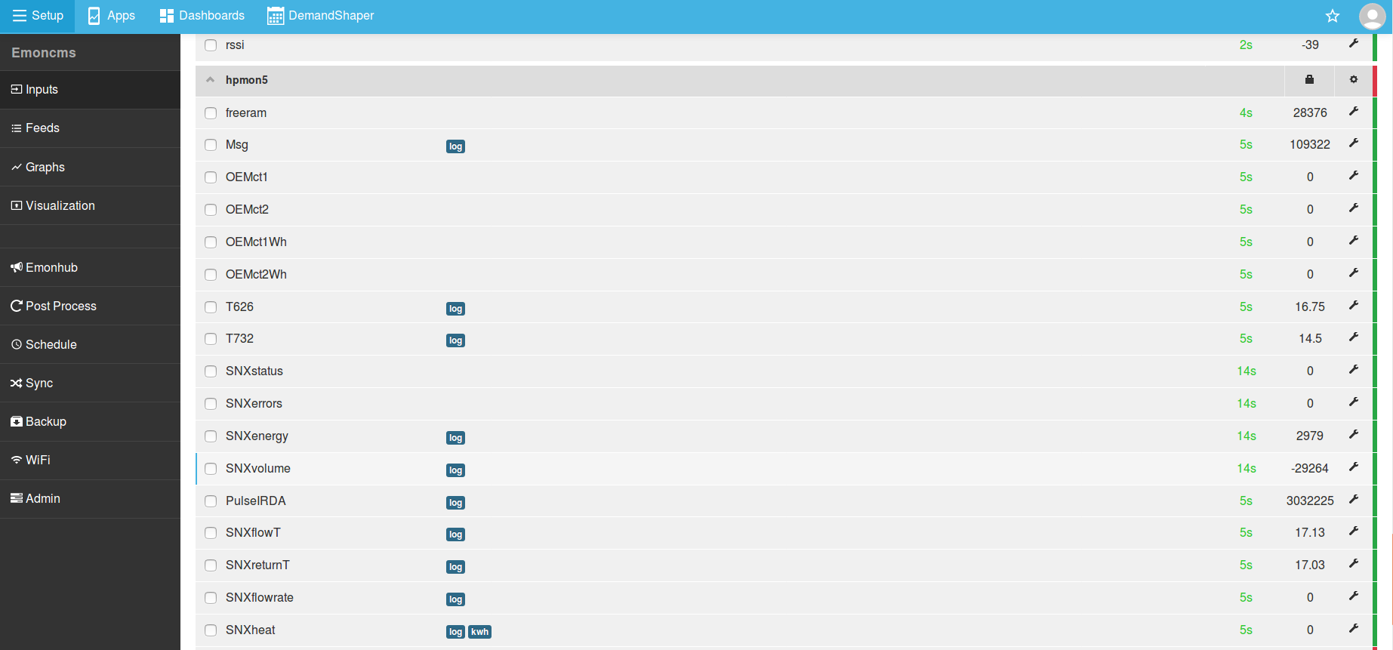
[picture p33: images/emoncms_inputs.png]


### Emoncms Feeds

The result of configuring the inputs will be a set of heatpump monitor related feeds, depending on your configuration this will look something like this:

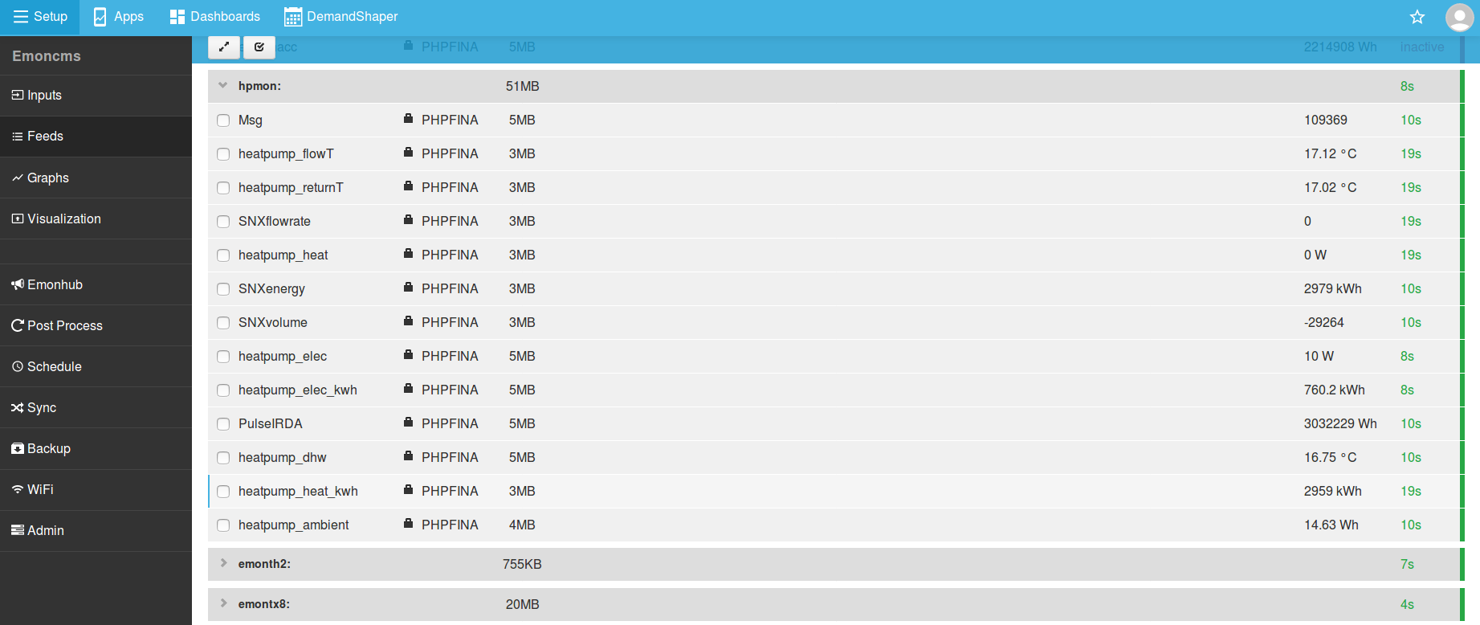
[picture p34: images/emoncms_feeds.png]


### Emoncms Heatpump Monitor dashboard

Open the heatpump monitor dashboard Apps > Add + > My Heatpump

Configure via spanner (top-right) as required.



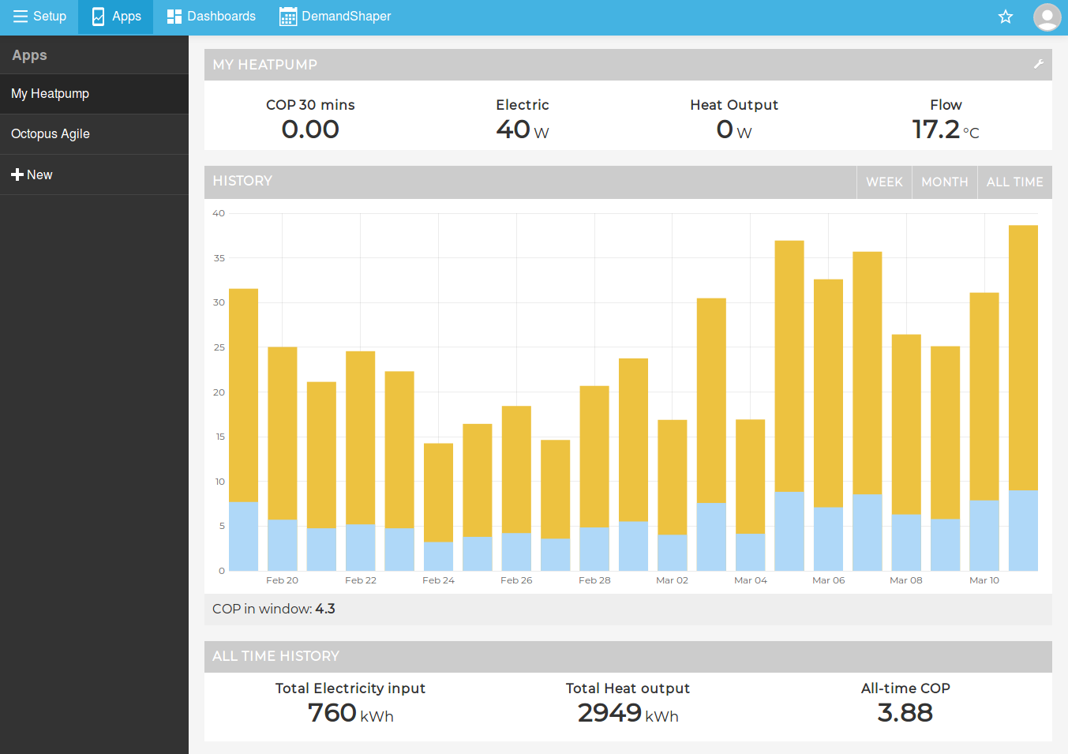
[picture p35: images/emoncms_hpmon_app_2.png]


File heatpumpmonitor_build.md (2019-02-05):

# Heatpump Monitor Build

**Please note: 100k / 10k blue resistors look very similar!** When assembling be sure to use select the 10k resistor for the ACAC voltage divider input.

The heatpump monitor comes as a component kit with all the resistors, capacitors, connectors, IC's and other parts required to complete the build. The full Bill of Materials can be found [here](https://github.com/openenergymonitor/HeatpumpMonitor/blob/master/costingexample.md)

**Packaged Kit**

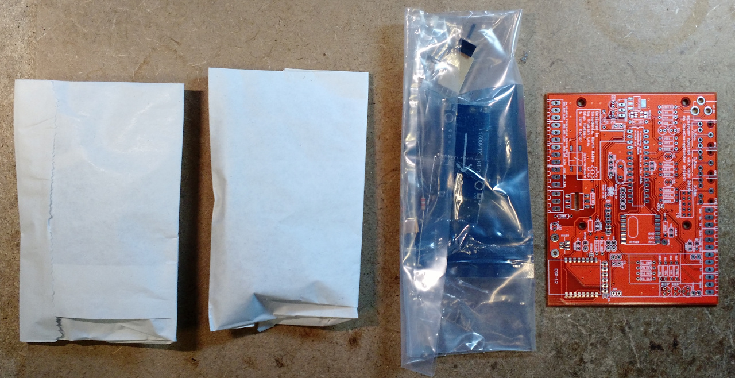
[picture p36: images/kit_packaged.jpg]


**Core kit components**

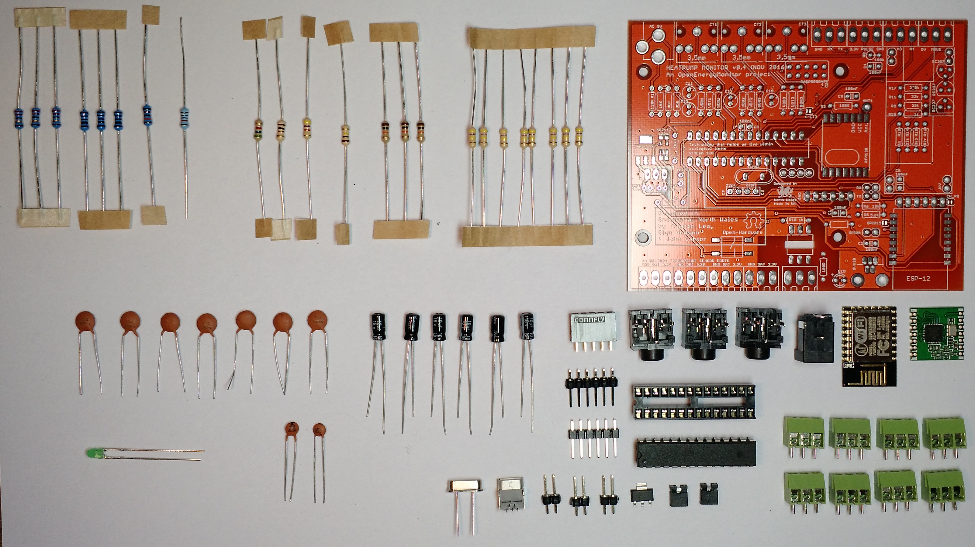
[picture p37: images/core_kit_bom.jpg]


**MBUS Reader kit components**

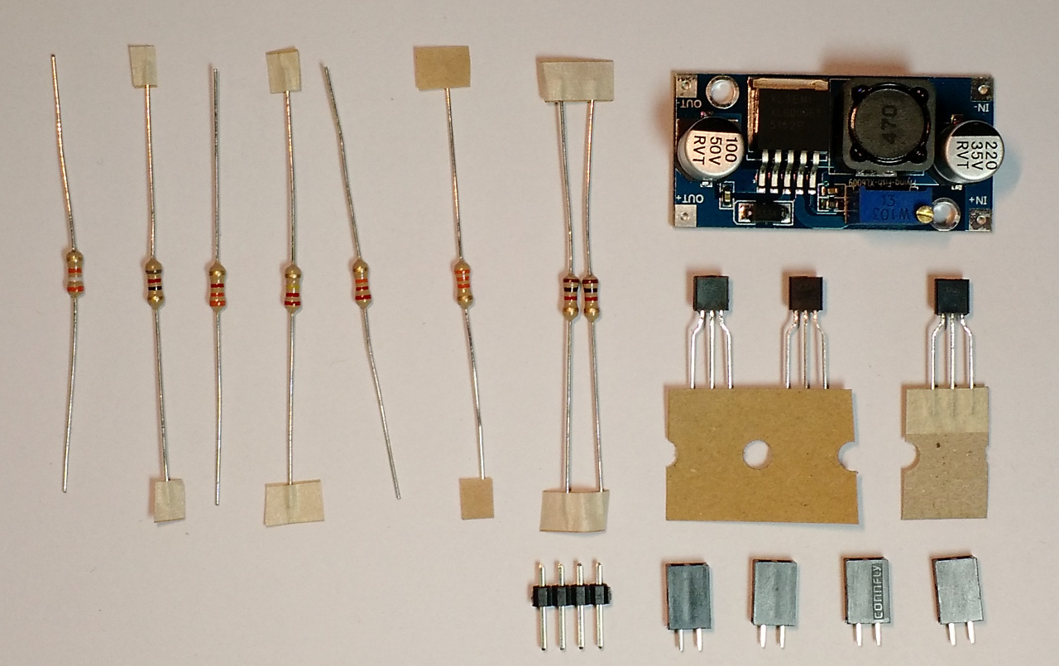
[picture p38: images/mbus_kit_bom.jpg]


**Resistor reference**

The following resistors are included in the kit.

<table cellspacing="0" border="0">
	<colgroup width="63"></colgroup>
	<colgroup width="219"></colgroup>
	<colgroup width="162"></colgroup>
	<colgroup width="245"></colgroup>
	<tr>
		<td height="17" align="center"><b>Quantity</b></td>
		<td align="left"><b>Resistance</b></td>
		<td align="left"><b>Colour code</b></td>
		<td align="left"><b>Function</b></td>
	</tr>
	<tr>
		<td height="17" align="center" sdval="8" sdnum="2057;">8</td>
		<td align="left">470k (5%)</td>
		<td align="left">Yellow-purple-yellow</td>
		<td align="left">CT + ACAC Voltage dividers</td>
	</tr>
	<tr>
		<td height="17" align="center" sdval="1" sdnum="2057;">1</td>
		<td align="left">120k (blue, 1%)</td>
		<td align="left">Brown-red-black-orange</td>
		<td align="left">ACAC voltage divider top</td>
	</tr>
	<tr>
		<td height="17" align="center" sdval="1" sdnum="2057;">1</td>
		<td align="left">10k (blue, 1%)</td>
		<td align="left">Brown-black-black-red</td>
		<td align="left">ACAC voltage divider bottom</td>
	</tr>
	<tr>
		<td height="17" align="center" sdval="1" sdnum="2057;">3</td>
		<td align="left">10k (5%)</td>
		<td align="left">Brown-black-orange</td>
		<td align="left">Mixed use</td>
	</tr>
	<tr>
		<td height="17" align="center" sdval="1" sdnum="2057;">1</td>
		<td align="left">4.7k (5%)</td>
		<td align="left">Yellow-purple-red</td>
		<td align="left">DS18B20 Temperature sensing</td>
	</tr>
	<tr>
		<td height="17" align="center" sdval="1" sdnum="2057;">1</td>
		<td align="left">100k (5%)</td>
		<td align="left">Brown-black-yellow</td>
		<td align="left">Pulse counting dropdown</td>
	</tr>
	<tr>
		<td height="17" align="center" sdval="1" sdnum="2057;">1</td>
		<td align="left">100R (5%)</td>
		<td align="left">Brown-black-brown</td>
		<td align="left">LED current limiting resistor</td>
	</tr>
	<tr>
		<td height="17" align="center" sdval="1" sdnum="2057;">1</td>
		<td align="left">5.6k (5%)</td>
		<td align="left">Green-blue-red</td>
		<td align="left">Serial 5V to 3.3V level converter</td>
	</tr>
	<tr>
		<td height="17" align="center" sdval="3" sdnum="2057;">3</td>
		<td align="left">22R (1%)</td>
		<td align="left"></td>
		<td align="left">CT burden resistors OPTION 1 (1%)</td>
	</tr>
	<tr>
		<td height="17" align="center" sdval="3" sdnum="2057;">3</td>
		<td align="left">100R (1%)</td>
		<td align="left"></td>
		<td align="left">CT burden resistors OPTION 2 (1%)</td>
	</tr>
</table>

MBUS Reader kit resistors:

<table cellspacing="0" border="0">
	<colgroup width="63"></colgroup>
	<colgroup width="219"></colgroup>
	<colgroup width="162"></colgroup>
	<colgroup width="245"></colgroup>
	<tr>
		<td height="17" align="center" sdval="1" sdnum="2057;">1</td>
		<td align="left">220k (5%)</td>
		<td align="left">Red-red-yellow</td>
		<td align="left">MBUS Reader</td>
	</tr>
	<tr>
		<td height="17" align="center" sdval="1" sdnum="2057;">1</td>
		<td align="left">33k (5%)</td>
		<td align="left">Orange-orange-orange</td>
		<td align="left">MBUS Reader</td>
	</tr>
	<tr>
		<td height="17" align="center" sdval="1" sdnum="2057;">1</td>
		<td align="left">39k (5%)</td>
		<td align="left">Orange-purple-orange</td>
		<td align="left">MBUS Reader</td>
	</tr>
	<tr>
		<td height="17" align="center" sdval="1" sdnum="2057;">1</td>
		<td align="left">22k (5%)</td>
		<td align="left">Red-red-orange</td>
		<td align="left">MBUS Reader</td>
	</tr>
	<tr>
		<td height="17" align="center" sdval="1" sdnum="2057;">1</td>
		<td align="left">3k3 (5%)</td>
		<td align="left">Orange-orange-red</td>
		<td align="left">MBUS Reader</td>
	</tr>
	<tr>
		<td height="17" align="center" sdval="1" sdnum="2057;">1</td>
		<td align="left">82R (5%)</td>
		<td align="left">Grey-red-black</td>
		<td align="left">MBUS Reader</td>
	</tr>
	<tr>
		<td height="17" align="center" sdval="2" sdnum="2057;">2</td>
		<td align="left">1k (5%)</td>
		<td align="left">Brown-black-red</td>
		<td align="left">MBUS Reader</td>
	</tr>
</table>

Component values including resistor resistance and capacitor capacitance are printed on the PCB. See resistor color code graphic here to help with matching the resistors [images/resistor-color-chart.jpg](images/resistor-color-chart.jpg).

Several of the resistors only have a reference name printed, the following are all part of the CT sensor and ACAC sensor biasing circuits and are all 470k resistors (470k (yellow-purple-yellow) was historically choosen to increase battery lifespan in battery powered nodes - lower values down to around 10k could be choosen instead here for a more stable biasing voltage):

    VDT: Voltage Divider Top (for AC-AC Voltage sensor)
    VDB: Voltage Divider Bottom (for AC-AC Voltage sensor)
    VDT1: Voltage Divider Top 1 (for CT sensor 1)
    VDB1: Voltage Divider Bottom 1 (for CT sensor 1)
    VDT2: Voltage Divider Top 2 (for CT sensor 2)
    VDB2: Voltage Divider Bottom 2 (for CT sensor 2)
    VDT3: Voltage Divider Top 3 (for CT sensor 3)
    VDB3: Voltage Divider Bottom 3 (for CT sensor 3)

**CT Burden resistors:**

The included burden resistor is 100 Ohms, this provides a AC power measurement range of **0 - 5.4 kW**. A smaller burden resistor can be used instead for larger measurement range at lower resolution, 22 Ohms would provide 0 - 24 kW range. See Building Blocks guide [CT sensors - interfacing with arduino](https://openenergymonitor.org/emon/buildingblocks/ct-sensors-interface)

Example calculation:

    Max Power = (((VREF ÷ 2) ÷ Burden resistance) × CT turns) × 230V ÷ sqrt(2)
    Max Power = (((3.3V ÷ 2) ÷ 100R) × 2000 turns) × 230V ÷ sqrt(2) 
    Copy into calculator: (((3.3÷2)÷100)×2000)×230÷sqrt(2) 

Burden resistor PCB name reference:

    BUR1: Burden resistor 1 (for CT sensor 1)
    BUR2: Burden resistor 2 (for CT sensor 2)
    BUR3: Burden resistor 3 (for CT sensor 3)
    
Capacitors: C11, C13, C12, C19 all 10uF

The following image can also be used as a reference of component locations. 
    
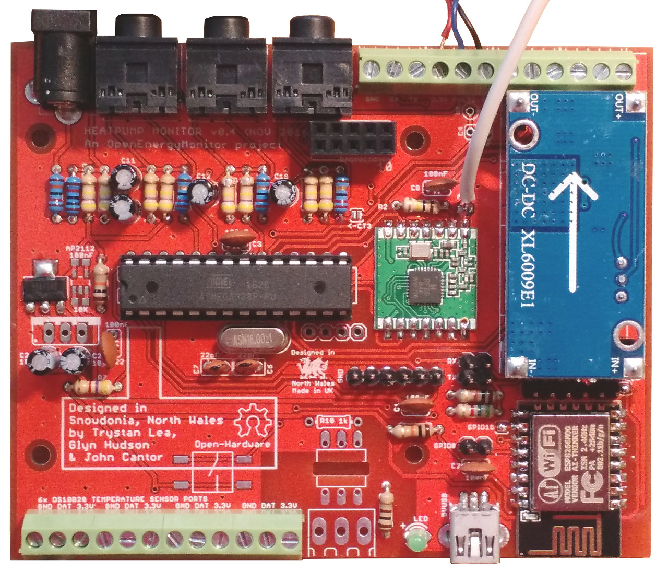
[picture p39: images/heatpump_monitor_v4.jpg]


**Tip 1:** It is usually easier to start by soldering the lower profile components first such as the resistors and to build up to the taller components. 

**Tip 2:** Test that the ATmega328 part works first before soldering in the ESP8266 module so that any issues with the ATmega328 part can be isolated before adding the ESP WIFI part. 

Check that the power supply voltages are all as expected before inserting the ATmega328 in the 28pin holder.

**ESP8266 Supply capacitor:** An additional 10uF may be required across the supply to the ESP8266 module. The ground is top-left and 3.3v top-right. Adding this capacitor solved an issue with the unit resetting regularly - indicating a power supply issue.

**ESP CH_PD and GPIO15 Solder jumpers** Both of these solder jumpers need to be connected with a small blob of solder for the ESP module to work.

### Build Guide Images

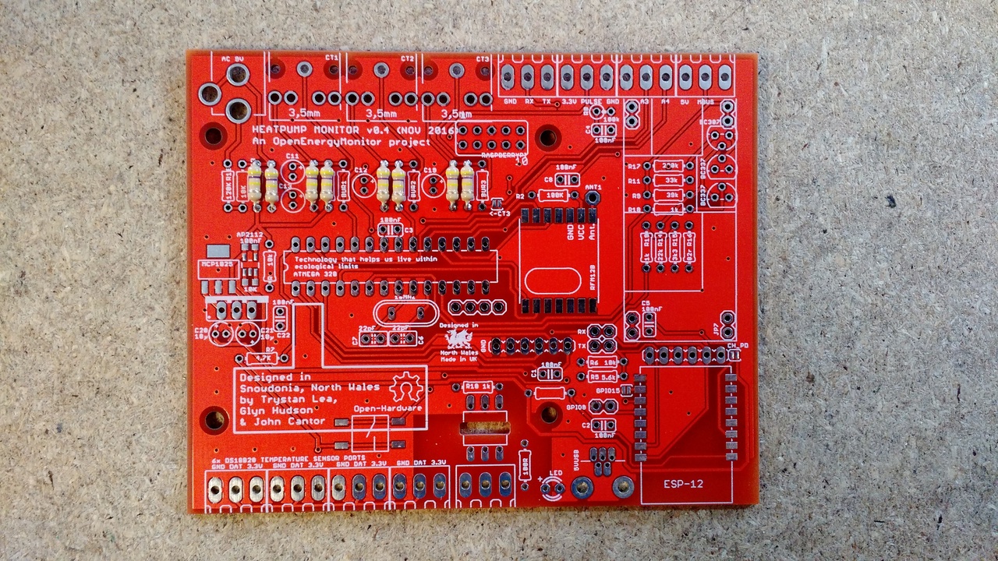
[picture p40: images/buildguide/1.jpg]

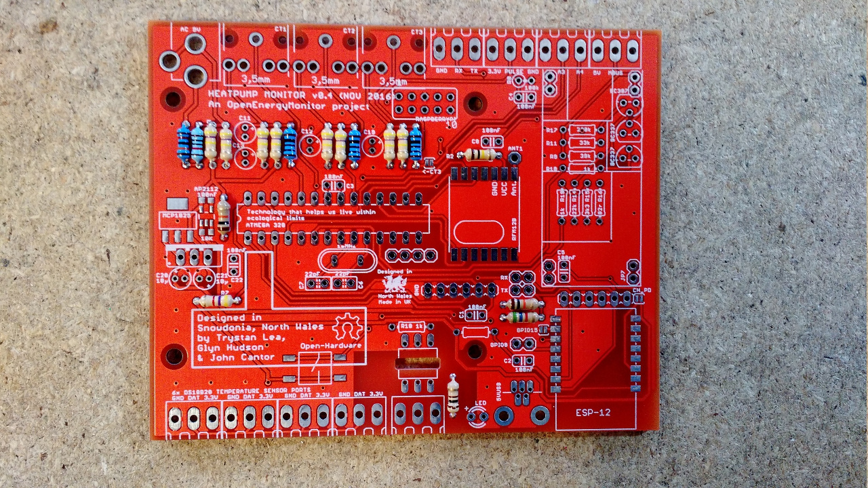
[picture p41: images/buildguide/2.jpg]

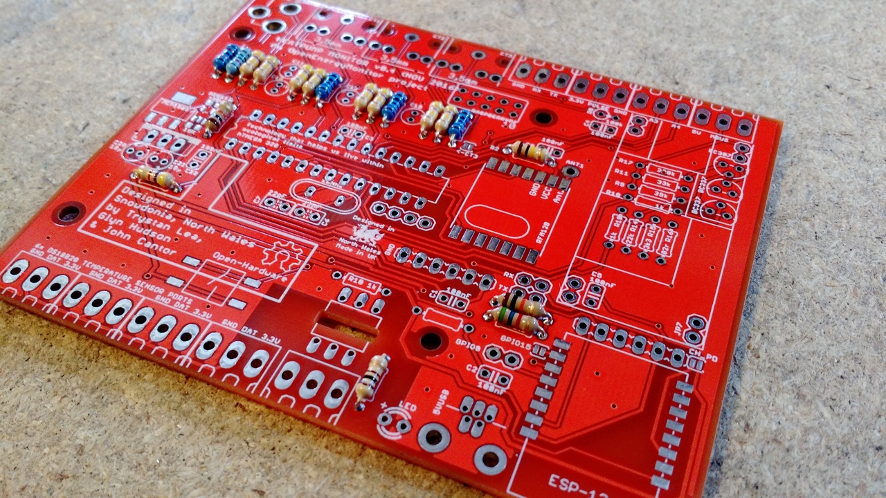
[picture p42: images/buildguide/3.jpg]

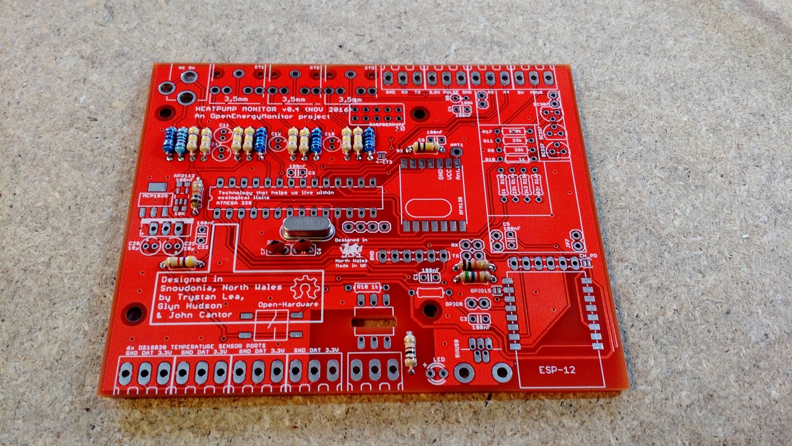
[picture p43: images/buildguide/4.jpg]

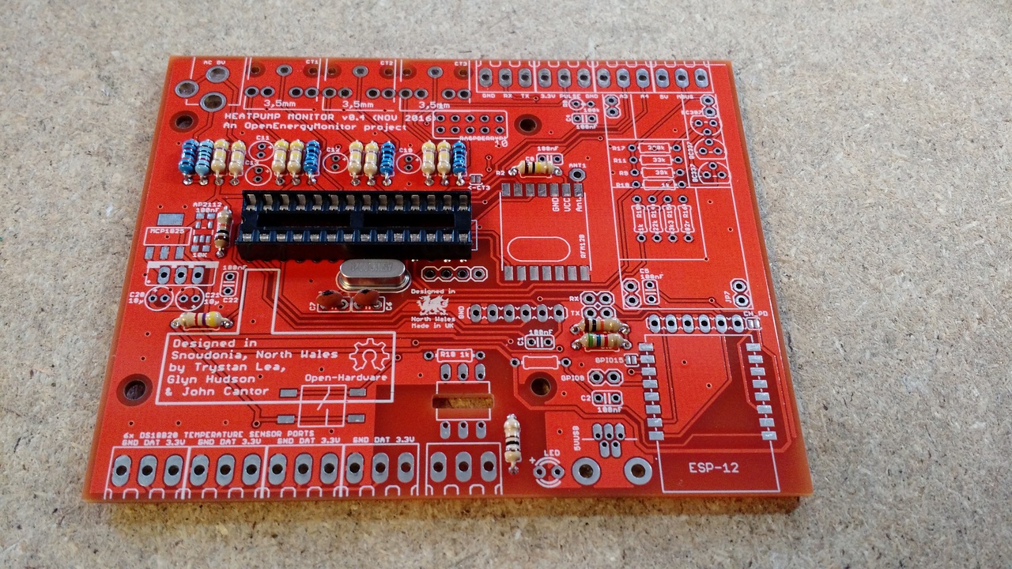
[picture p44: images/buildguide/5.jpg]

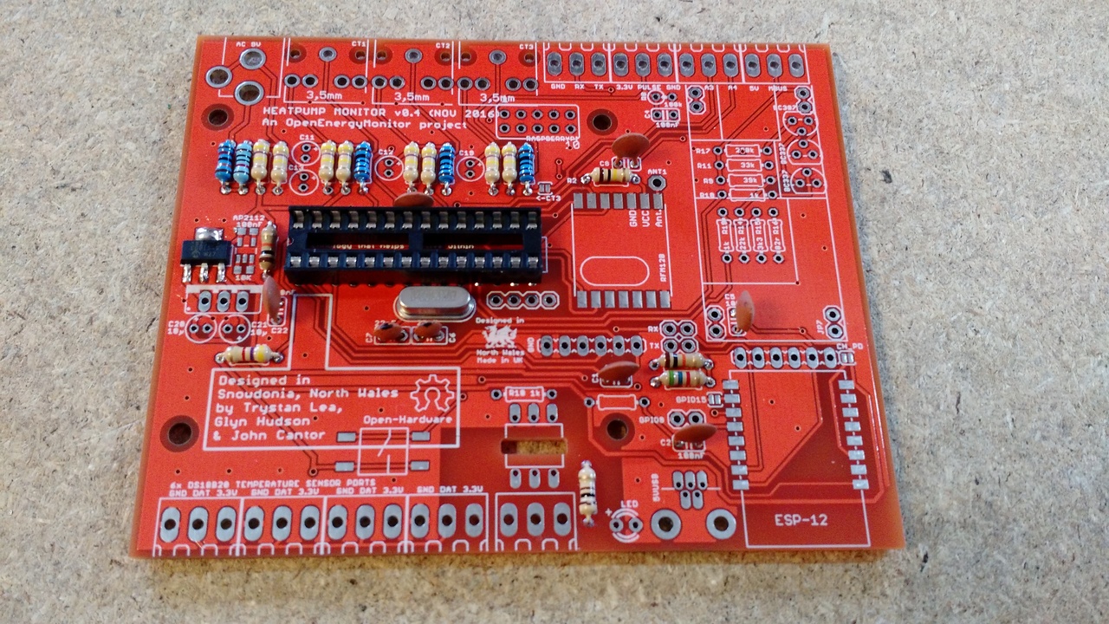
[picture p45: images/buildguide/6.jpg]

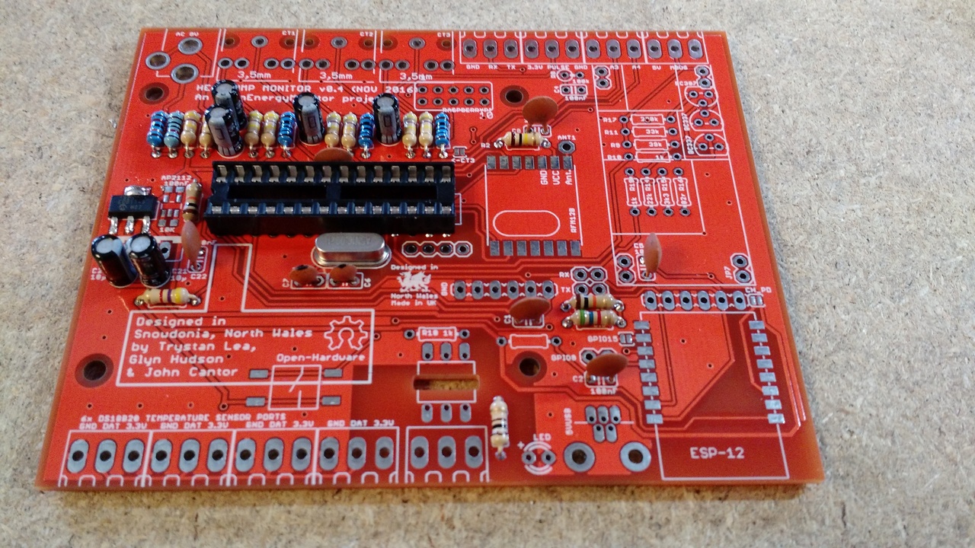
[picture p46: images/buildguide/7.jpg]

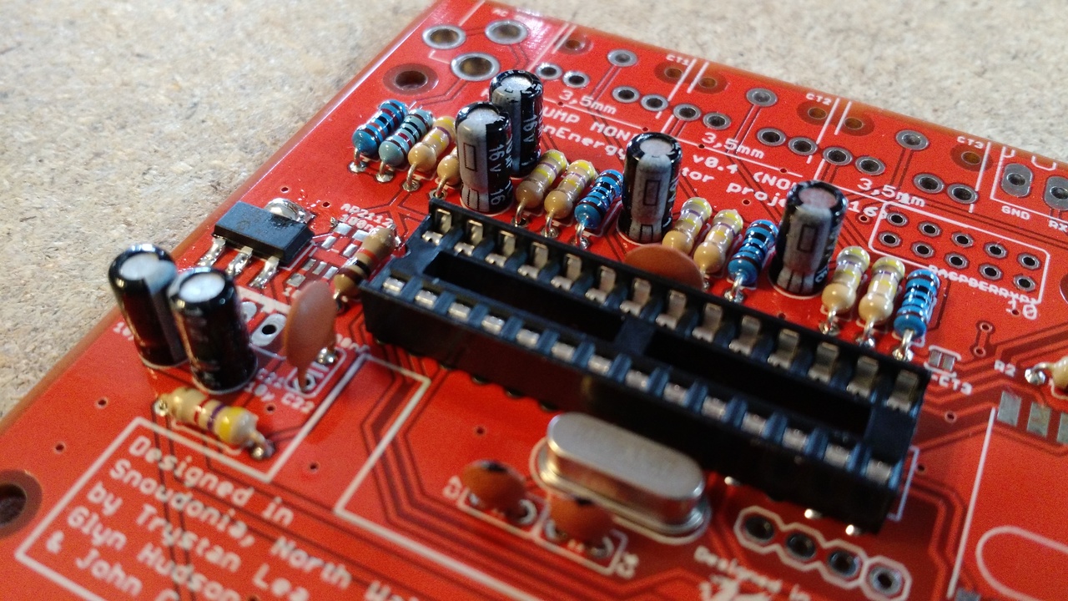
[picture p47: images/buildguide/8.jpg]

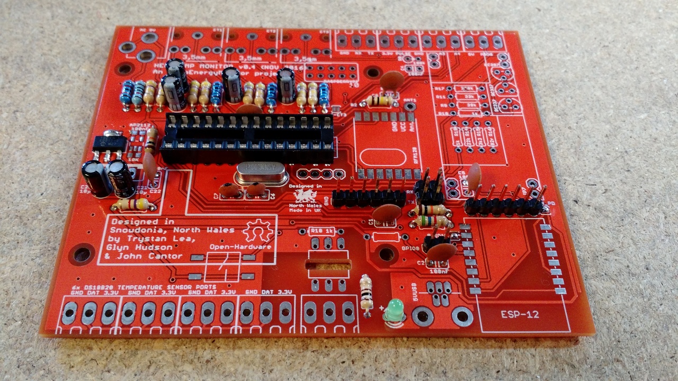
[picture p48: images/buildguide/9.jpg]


**Voltage check**

At this point with the voltage regulator soldered in, mini USB and capacitors its possible to check that the board is producing 3.3V from the 5.0V USB supply. Use a multimeter and connect across GND and 3.3V on one of the DS18B20 temperature sensor inputs.
Check that the voltage regulator is not getting warm.

**Arduino Upload check**

This is also a good point to check that its possible to upload firmware to the ATmega328 microcontroller. Place the ATmega328 in the 28pin chip holder temporarily and try uploading the Arduino ATmega328 firmware, follow the instructions below in the *Uploading the ATmega328 Firmware*.

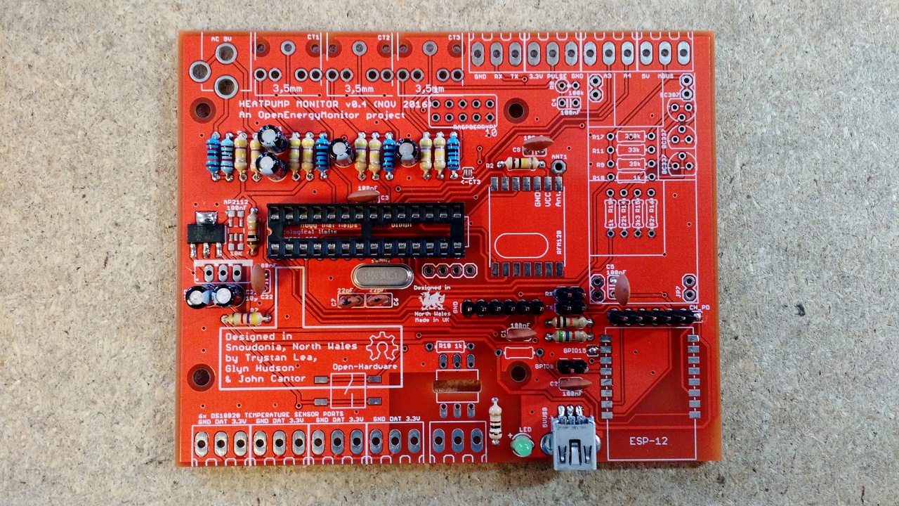
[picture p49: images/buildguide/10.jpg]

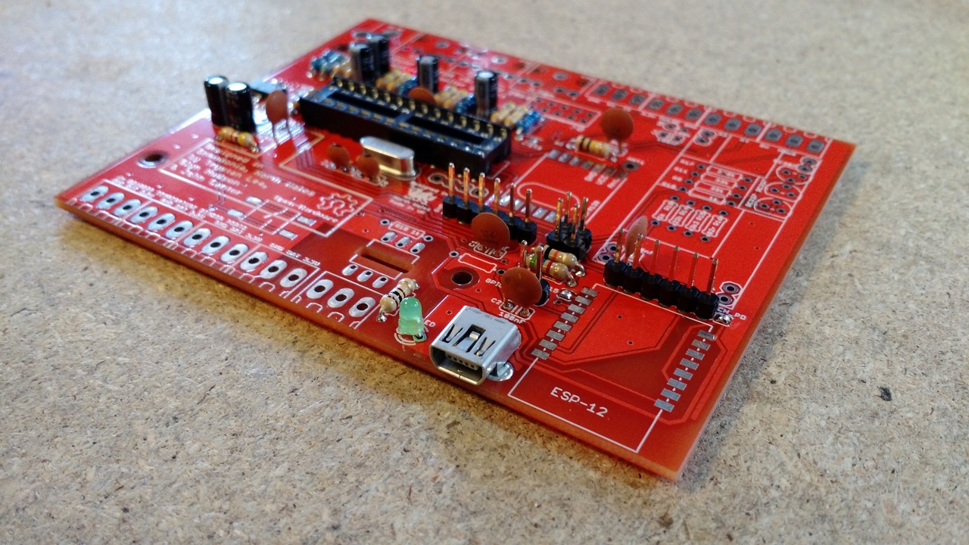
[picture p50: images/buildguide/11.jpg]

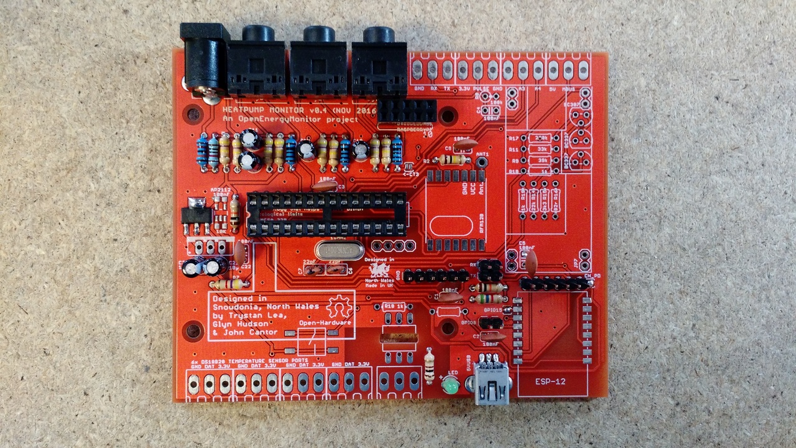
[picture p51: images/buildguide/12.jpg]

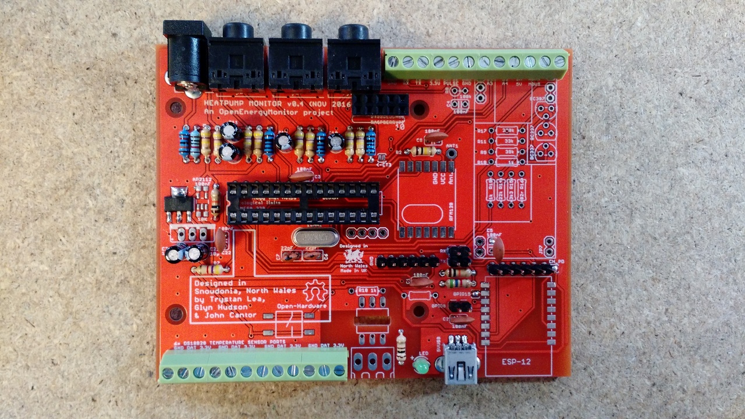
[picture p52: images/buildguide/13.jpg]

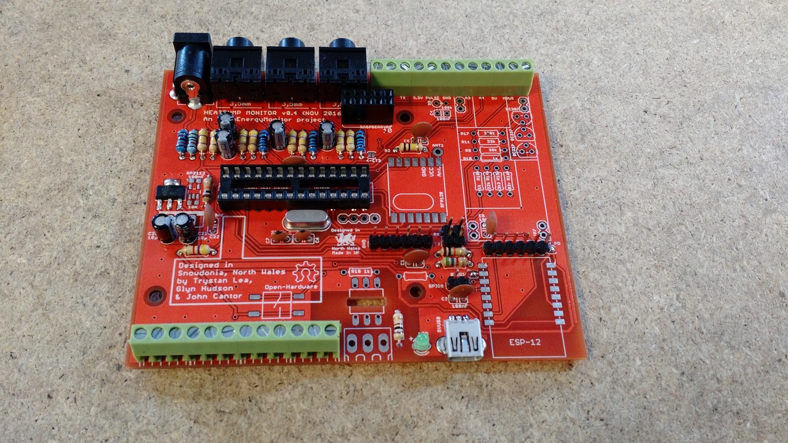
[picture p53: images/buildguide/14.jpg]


Once happy that the components so far are all soldered correctly and that the board voltages are still correct and that its still possible to upload code to the Arduino ATmega328, the next step is to solder in the radio module and ESP8266 Wifi module.

Start by placing a small blob of solder on one of the pads on the board.
Then place the module on the board and adjust into position heating up the soldered pad so that a holding connection is made at this one point. Triple check the positioning of the modules before soldering the rest of the pads.

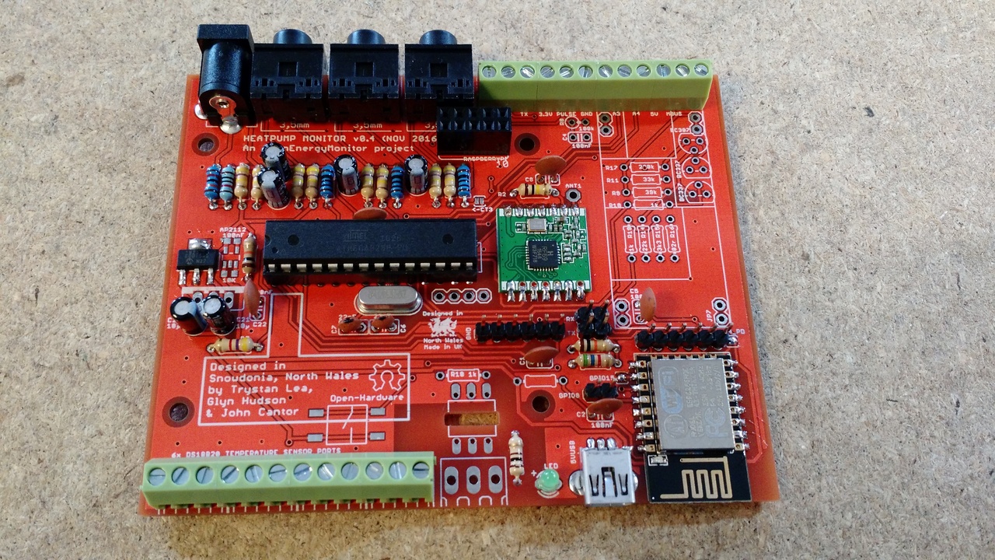
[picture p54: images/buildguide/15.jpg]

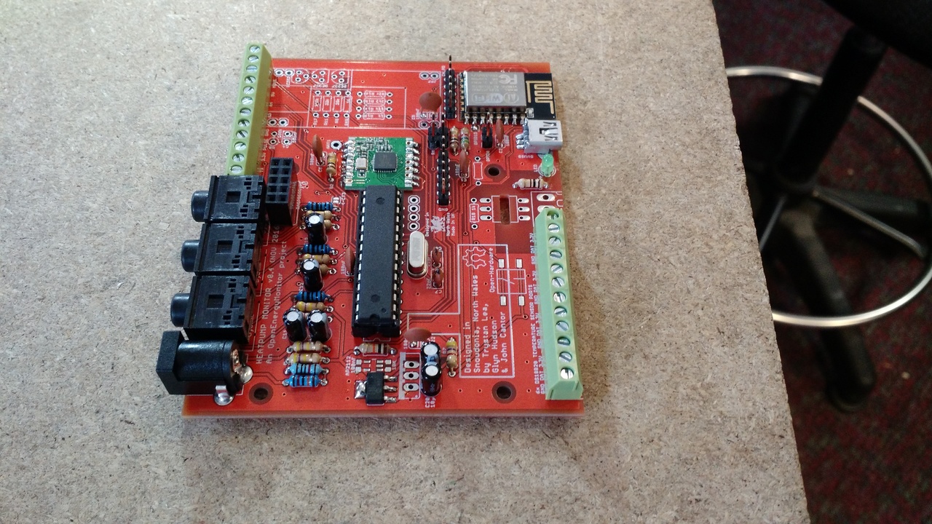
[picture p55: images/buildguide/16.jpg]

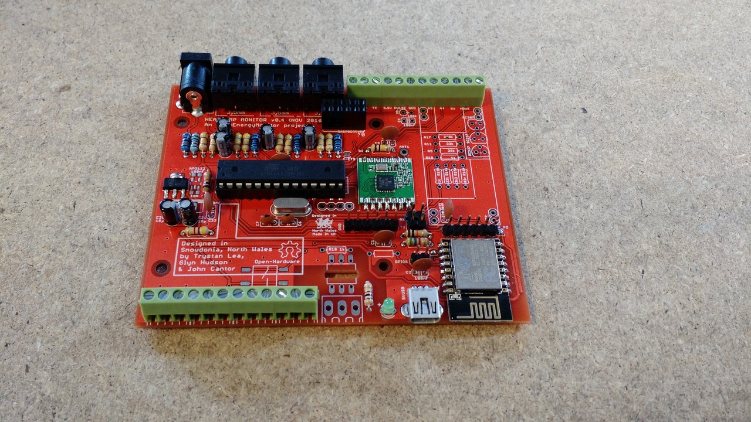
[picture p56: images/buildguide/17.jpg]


MBUS resistor and transistor reference:

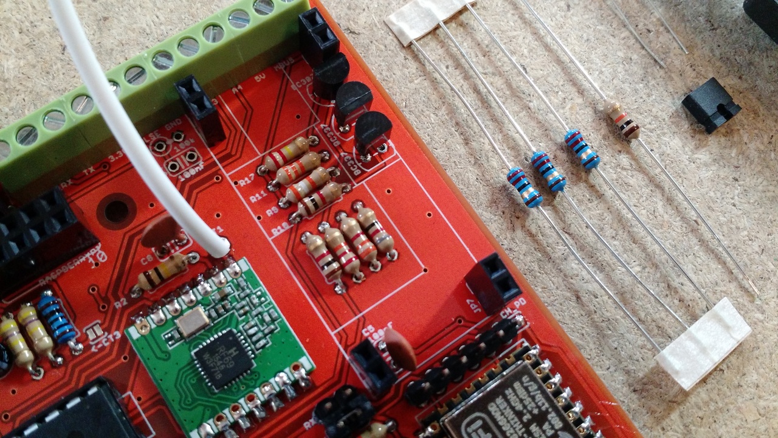
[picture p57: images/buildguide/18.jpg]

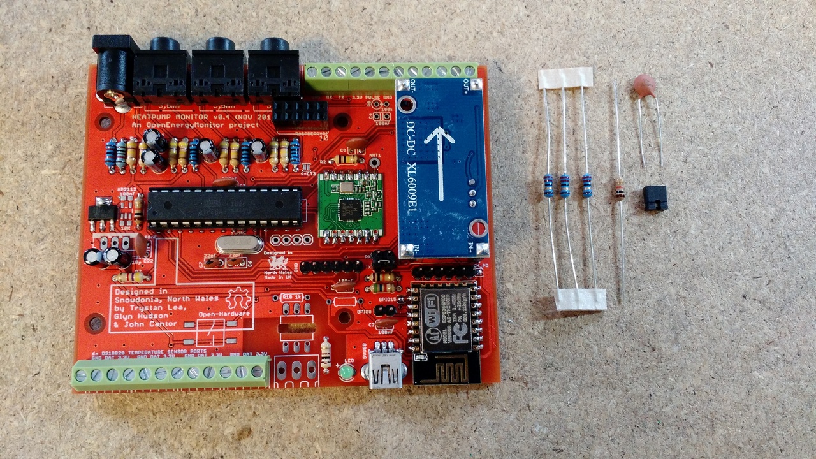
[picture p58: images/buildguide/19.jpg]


Finished article:

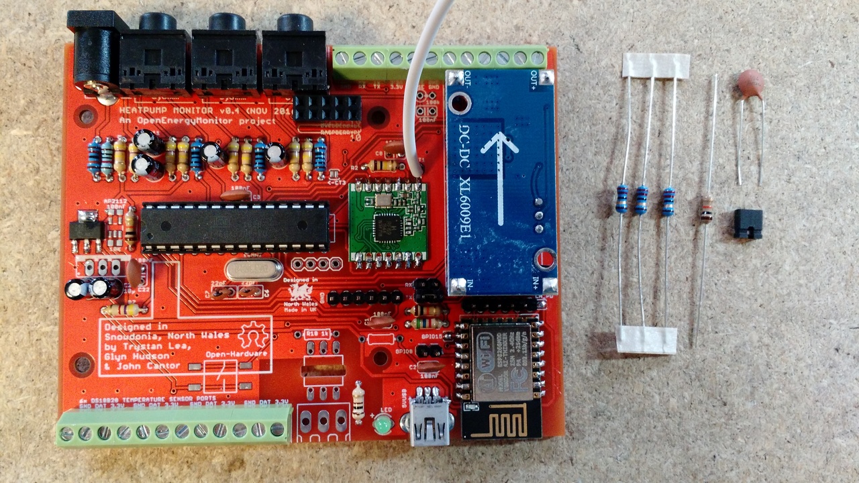
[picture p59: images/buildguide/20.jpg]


Optional enclosure kit:

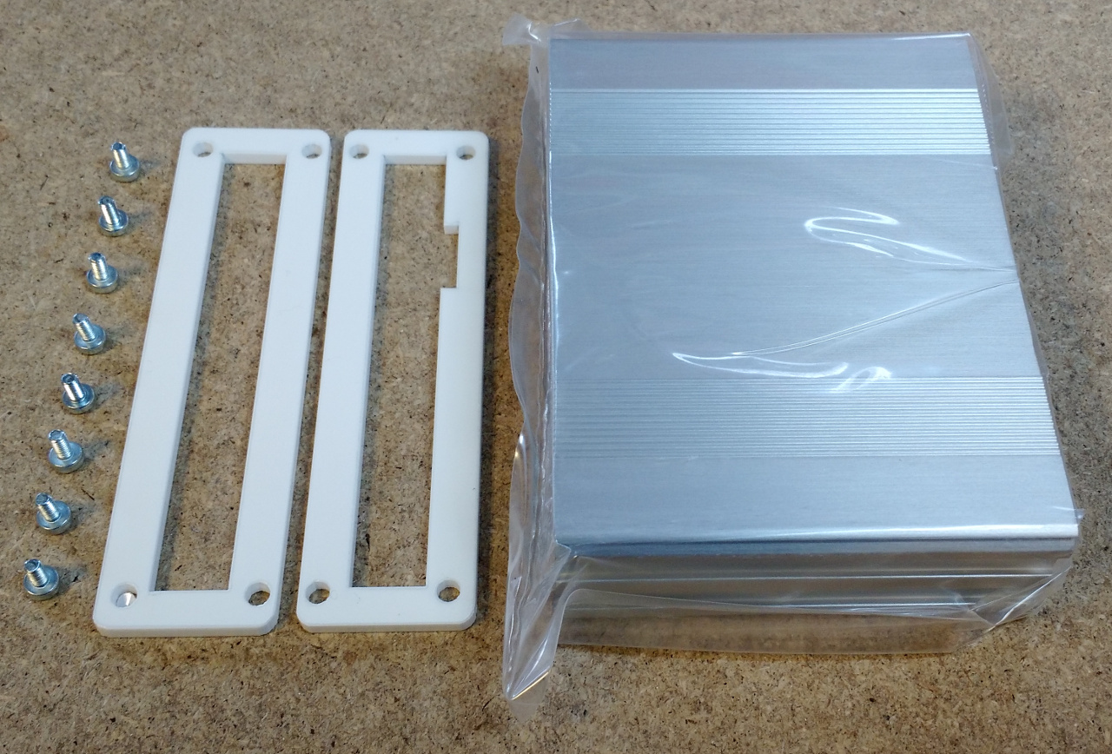
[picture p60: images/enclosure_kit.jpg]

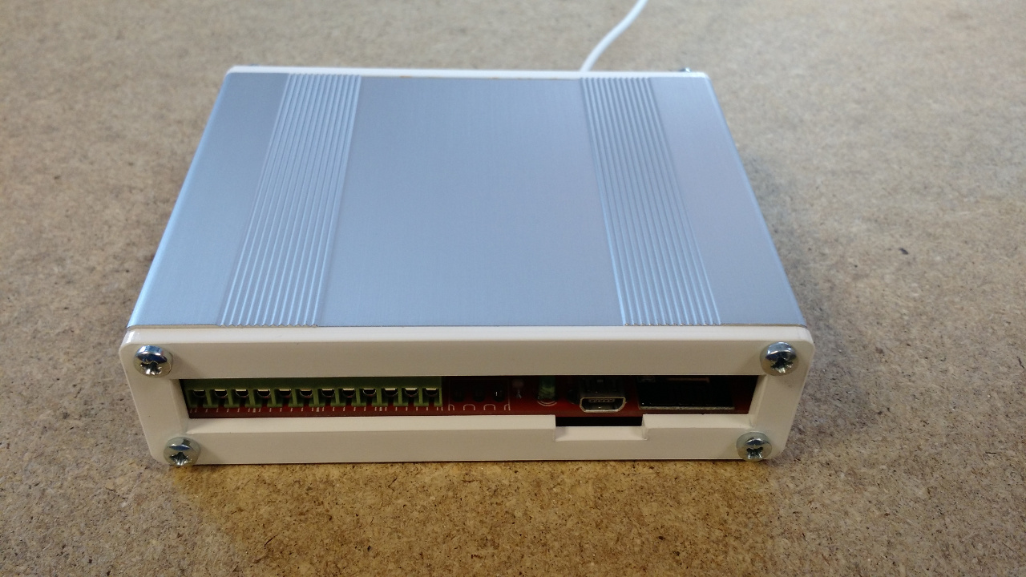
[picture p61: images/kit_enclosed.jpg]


## Uploading Firware

The Heatpump monitor has two microcontrollers. Firmware for these must be loaded separately:

### Uploading the ATmega328 Firmware

The default heatpump monitor firmware can be found here: [https://github.com/openenergymonitor/HeatpumpMonitor/tree/master/Firmware/Arduino/HeatpumpMonitor_AutoTemp](https://github.com/openenergymonitor/HeatpumpMonitor/tree/master/Firmware/Arduino/HeatpumpMonitor_AutoTemp)

Use a USB to UART programmer connected to the 6-way UART header closest to the ATmega328 to upload this firmware using the Arduino IDE. Be sure to select "Uno" as the board type in the Arduino IDE. 

If you're using the cable sold through the OpenEnergyMonitor Shop, the drivers for Windows and Mac can be downloaded here: [http://www.silabs.com/products/mcu/Pages/USBtoUARTBridgeVCPDrivers.aspx](http://www.silabs.com/products/mcu/Pages/USBtoUARTBridgeVCPDrivers.aspx)

The Heatpump Monitor repository contains all the Arduino libraries required to compile the heatpump monitor firmware. Once the Ardunio IDE is installed it can be configured to use these libraries by going to: **File > Preferences** and setting the sketchbook location to **HeatpumpMonitor/Firmware/Arduino** (including the full path to your HeatpumpMonitor folder on your system).

### Uploading the ESP8266 Firmware: EmonESP

The EmonESP ESP8266 Firmware and upload guide can be found here: [https://github.com/openenergymonitor/EmonESP](https://github.com/openenergymonitor/EmonESP)

**GPIO0 Jumper:** Place a jumper across the GPIO0 header just left of the ESP8266 module to place the ESP8266 module in bootloader mode. Power cycle the board to reset the ESP8266 module. Once the firmware is uploaded remove the GPIO0 jumper so that the ESP8266 starts up without going into bootloader mode at the next power cycle.

---

**TX Jumper:** Place the second jumper across the TX header to link the Atmega micro to the ESP8266 module. Required for sending data on to emoncms via WIFI.

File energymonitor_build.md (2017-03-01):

# Energy Monitor Build

A cut down version of the heatpump monitor can be used as a WIFI energy monitor without the additional components used for the MBUS reader, RFM69 and other connectors.

BOM:

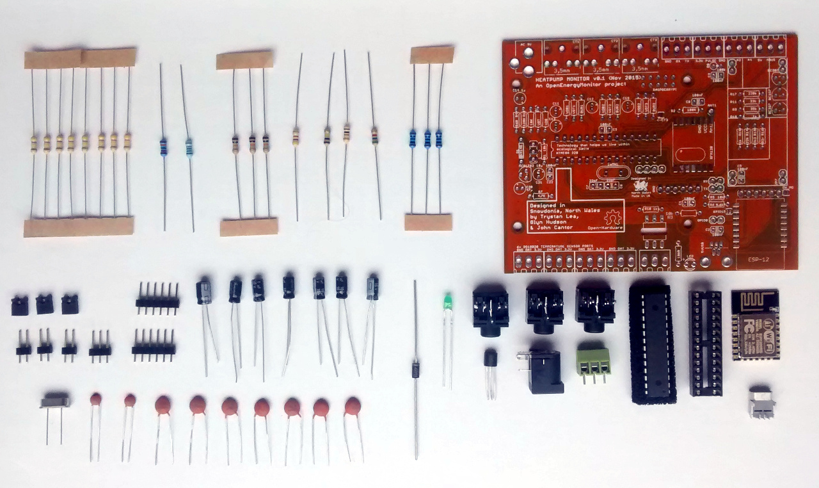
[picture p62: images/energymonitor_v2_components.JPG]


**Resistor reference**

The following resistors are included in the kit.

<table cellspacing="0" border="0">
	<colgroup width="63"></colgroup>
	<colgroup width="219"></colgroup>
	<colgroup width="162"></colgroup>
	<colgroup width="245"></colgroup>
	<tr>
		<td height="17" align="center"><b>Quantity</b></td>
		<td align="left"><b>Resistance</b></td>
		<td align="left"><b>Colour code</b></td>
		<td align="left"><b>Function</b></td>
	</tr>
	<tr>
		<td height="17" align="center" sdval="8" sdnum="2057;">8</td>
		<td align="left">470k (5%)</td>
		<td align="left">Yellow-purple-yellow</td>
		<td align="left">CT + ACAC Voltage dividers</td>
	</tr>
	<tr>
		<td height="17" align="center" sdval="1" sdnum="2057;">1</td>
		<td align="left">120k (blue, 1%)</td>
		<td align="left">Brown-red-black-orange</td>
		<td align="left">ACAC voltage divider top</td>
	</tr>
	<tr>
		<td height="17" align="center" sdval="1" sdnum="2057;">1</td>
		<td align="left">10k (blue, 1%)</td>
		<td align="left">Brown-black-black-red</td>
		<td align="left">ACAC voltage divider bottom</td>
	</tr>
	<tr>
		<td height="17" align="center" sdval="1" sdnum="2057;">3</td>
		<td align="left">10k (5%)</td>
		<td align="left">Brown-black-orange</td>
		<td align="left">Mixed use</td>
	</tr>
	<tr>
		<td height="17" align="center" sdval="1" sdnum="2057;">1</td>
		<td align="left">4.7k (5%)</td>
		<td align="left">Yellow-purple-red</td>
		<td align="left">DS18B20 Temperature sensing</td>
	</tr>
	<tr>
		<td height="17" align="center" sdval="1" sdnum="2057;">1</td>
		<td align="left">100k (5%)</td>
		<td align="left">Brown-black-yellow</td>
		<td align="left">Pulse counting dropdown</td>
	</tr>
	<tr>
		<td height="17" align="center" sdval="1" sdnum="2057;">1</td>
		<td align="left">100R (5%)</td>
		<td align="left">Brown-black-brown</td>
		<td align="left">LED current limiting resistor</td>
	</tr>
	<tr>
		<td height="17" align="center" sdval="1" sdnum="2057;">1</td>
		<td align="left">5.6k (5%)</td>
		<td align="left">Green-blue-red</td>
		<td align="left">Serial 5V to 3.3V level converter</td>
	</tr>
	<tr>
		<td height="17" align="center" sdval="3" sdnum="2057;">3</td>
		<td align="left">CT burden resistors (1%)</td>
		<td align="left">see note</td>
		<td align="left"><br></td>
	</tr>
</table>

Component values including resistor resistance and capacitor capacitance are printed on the PCB. See resistor color code graphic here to match the resistors [images/resistor-color-chart.jpg](images/resistor-color-chart.jpg).

Several of the resistors only have a reference name printed, the following are all part of the CT sensor and ACAC sensor biasing circuits and are all 470k resistors (470k (yellow-purple-yellow) was historically choosen to increase battery lifespan in battery powered nodes - lower values down to around 10k could be choosen instead here for a more stable biasing voltage):

    VDT: Voltage Divider Top (for AC-AC Voltage sensor)
    VDB: Voltage Divider Bottom (for AC-AC Voltage sensor)
    VDT1: Voltage Divider Top 1 (for CT sensor 1)
    VDB1: Voltage Divider Bottom 1 (for CT sensor 1)
    VDT2: Voltage Divider Top 2 (for CT sensor 2)
    VDB2: Voltage Divider Bottom 2 (for CT sensor 2)
    VDT3: Voltage Divider Top 3 (for CT sensor 3)
    VDB3: Voltage Divider Bottom 3 (for CT sensor 3)

**CT Burden resistors:**

The included burden resistor is 100 Ohms, this provides a AC power measurement range of **0 - 5.4 kW**. A smaller burden resistor can be used instead for larger measurement range at lower resolution, 22 Ohms would provide 0 - 24 kW range. See Building Blocks guide [CT sensors - interfacing with arduino](https://openenergymonitor.org/emon/buildingblocks/ct-sensors-interface)

Example calculation:

    Max Power = (((VREF ÷ 2) ÷ Burden resistance) × CT turns) × 230V ÷ sqrt(2)
    Max Power = (((3.3V ÷ 2) ÷ 100R) × 2000 turns) × 230V ÷ sqrt(2) 
    Copy into calculator: (((3.3÷2)÷100)×2000)×230÷sqrt(2) 

Burden resistor PCB name reference:

    BUR1: Burden resistor 1 (for CT sensor 1)
    BUR2: Burden resistor 2 (for CT sensor 2)
    BUR3: Burden resistor 3 (for CT sensor 3)
    
Capacitors: C11, C13, C12, C19 all 10uF

The following image can also be used as a reference of component locations. 
    
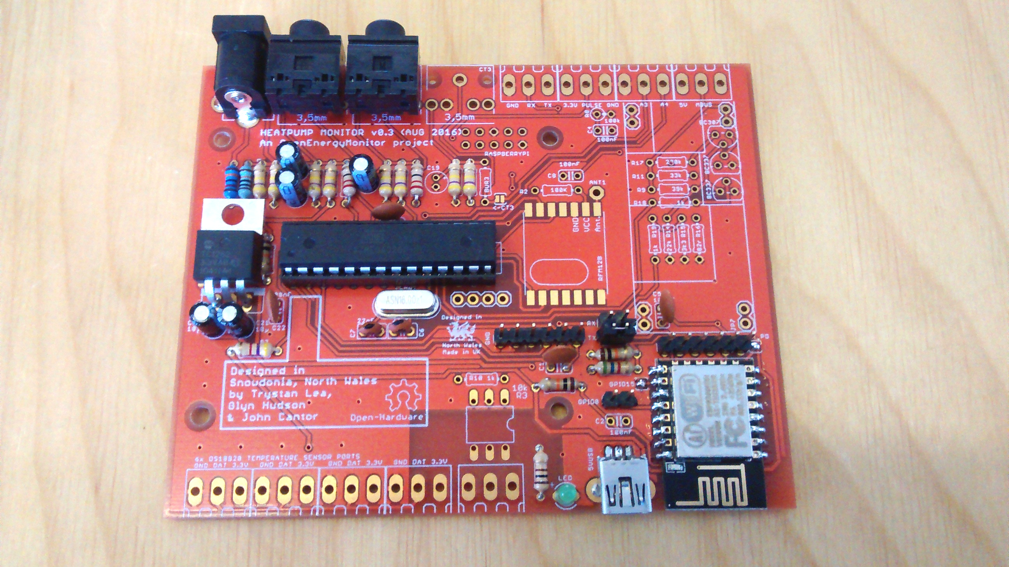
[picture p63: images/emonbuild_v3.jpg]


**Voltage regulator note:**The voltage regulator shown in the picture above is the large through-hole TC1262-3.3V, the board also supports the smaller MCP1825 surface mount voltage regulator. 

**Tip 1:** It is usually easier to start by soldering the lower profile components first such as the resistors and to build up to the taller components. 

**Tip 2:** Test that the ATmega328 part works first before soldering in the ESP8266 module so that any issues with the ATmega328 part can be isolated before adding the ESP WIFI part. 

Check that the power supply voltages are all as expected before inserting the ATmega328 in the 28pin holder.

**ESP8266 Supply capacitor:** An additional 10uF is required across the supply to the ESP8266 module. The ground is top-left and 3.3v top-right.

**ESP CH_PD and GPIO15 Solder jumpers** Both of these solder jumpers need to be connected with a small blob of solder for the ESP module to work.

### Uploading the ATmega328 Firmware

The energy monitor only firmware can be found here: [https://github.com/openenergymonitor/HeatpumpMonitor/tree/master/Firmware/Arduino/BasicEnergyMonitor](https://github.com/openenergymonitor/HeatpumpMonitor/tree/master/Firmware/Arduino/BasicEnergyMonitor)

Use a USB to UART programmer connected to the 6-way UART header closest to the ATmega328 to upload this firmware using the Arduino IDE. There's a guide on uploading Arduino firmware here: [http://openenergymonitor.org/emon/buildingblocks/setting-up-the-arduino-environment](http://openenergymonitor.org/emon/buildingblocks/setting-up-the-arduino-environment)

### Uploading the ESP8266 Firmware: EmonESP

The EmonESP ESP8266 Firmware and upload guide can be found here: [https://github.com/openenergymonitor/EmonESP](https://github.com/openenergymonitor/EmonESP)

**GPIO0 Jumper:** Place a jumper across the GPIO0 header just left of the ESP8266 module to place the ESP8266 module in bootloader mode. Power cycle the board to reset the ESP8266 module. Once the firmware is uploaded remove the GPIO0 jumper so that the ESP8266 starts up without going into bootloader mode at the next power cycle.

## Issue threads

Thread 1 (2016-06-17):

Optimised Rx 5v UART Protection

glynhudson, 2016-06-17:
The ESP is a 3.3V max device, using a 5V FTDI cable (even just for Rx + Tx) can damage it. The HP monitor currently includes a voltage divider on the RX input (R6 10k, R5 5.6K). This does the job but the same can be achieved with a single 1N4148 diode in reverse bias

```
Whenever the 5V device transmits, it pulls the bus down, and the diode conducts to 0.5~7V, when it releases or pulls the bus UP to 5V, the diode blocks the current from flowing, and a resistor on the 3.3V device should pull the bus on the 3.3V side back to 3.3V.
```
http://www.ceus-now.com/how-does-this-logic-level-converter-on-the-adafruit-huzzah-work/

No protection is needed on the Tx since this is transmitting (at 3.3V) from the ESP.

**Solution:**

Put a 1N4148 diode in series on the Rx line with cathode (-) connected to to the 5V FTDI cable and  anode (+) connecting to the ESP, see Huzza shematic:

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

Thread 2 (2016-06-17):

ESP FTDI upload auto reset

glynhudson, 2016-06-17:
If we want to be able to upload via FTDI without having to manually put the ESP into bootloader mode this circuit can be used to achieve this using the chip-power down pin (CH_PD):

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

This works with all ESP's and 3.3V and 5V FTDI. The B5819W Schotkey diode is used to convert 5V > 3.3V, we don't needs this on the HP monitor since we have a dedicated 3.3V voltage regulator onboard.

Design notes:
http://hallard.me/esp8266-autoreset/

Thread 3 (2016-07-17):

Need stronger LDO

glynhudson, 2016-07-17:
Using the MCP1702 as the LDO is problematic. The ESP can current spike up to [300mA](http://blog.hekkers.net/tag/esp-12/). The spikes are quite narrow, so are mostly supplied by the reservoir/decoupling caps after the LDO.  There is a limit to how fat you can make these though without driving the LDO out of its stable region (22uF is the max in the spec).  The risk is the LDO runs into its current limit mode and folds the output voltage towards ground to protect itself. The symptoms will be frequent global resets since the ATMega will pick up on the supply rail flicker, generating a POR.

Check the waveforms at JP1 - the heavier load on the positive half cycle might well be taking the wall wart into saturation, upsetting that finely-tuned simultaneous power&sample section.

TrystanLea, 2017-03-01:
Fixed in v3/v4

Closed 2017-03-01.

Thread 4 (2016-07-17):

RF Module PCB design & supply decoupling

glynhudson, 2016-07-17:
For the RF Module footprint, I see you have connected in the secondary GND on P14. This is quite important for EMI - you can improve further by "stitching" the top and bottom floods in this area with "random" vias.  If you make changes in this area, I suggest altering the top silk also - confusing the crystal position  then flipping the RF module around has been a common construction error.

I'd also find space for pads for a series L just before C8 in the module Vcc feed - it is supplied after the ESP-12 so the supply decoupling may need improving. C8 is probably too large, it will be inductive in the RF range of interest. You can get a handle on this by checking the background RSSI with ANT shorted locally to GND (BTW, if you juggle R2,C8 around, putting C8 closest to the Vcc pin, there is probably enough room for an explicit GND pad right next to ANT - very useful for an external rubber duck pigtail

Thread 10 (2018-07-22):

eagleCAD ESP12E schematic view label correction

danbates2, 2018-07-22:
a note here that GPIO4 and 5 schematic part labels may be swapped and need checking.

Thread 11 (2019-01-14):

Website

cassiel74, 2019-01-14:
https://heatpumpmonitor.org/
Forbidden...
virtual host issue? or choiche?

Closed 2020-01-09.

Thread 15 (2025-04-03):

Link preview broken

langestefan, 2025-04-03:
When I link to [https://heatpumpmonitor.org/](https://heatpumpmonitor.org/) from a website or forum on websites like linkedin a preview box shows up, this box seems to be broken.

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

Closed 2025-04-21.

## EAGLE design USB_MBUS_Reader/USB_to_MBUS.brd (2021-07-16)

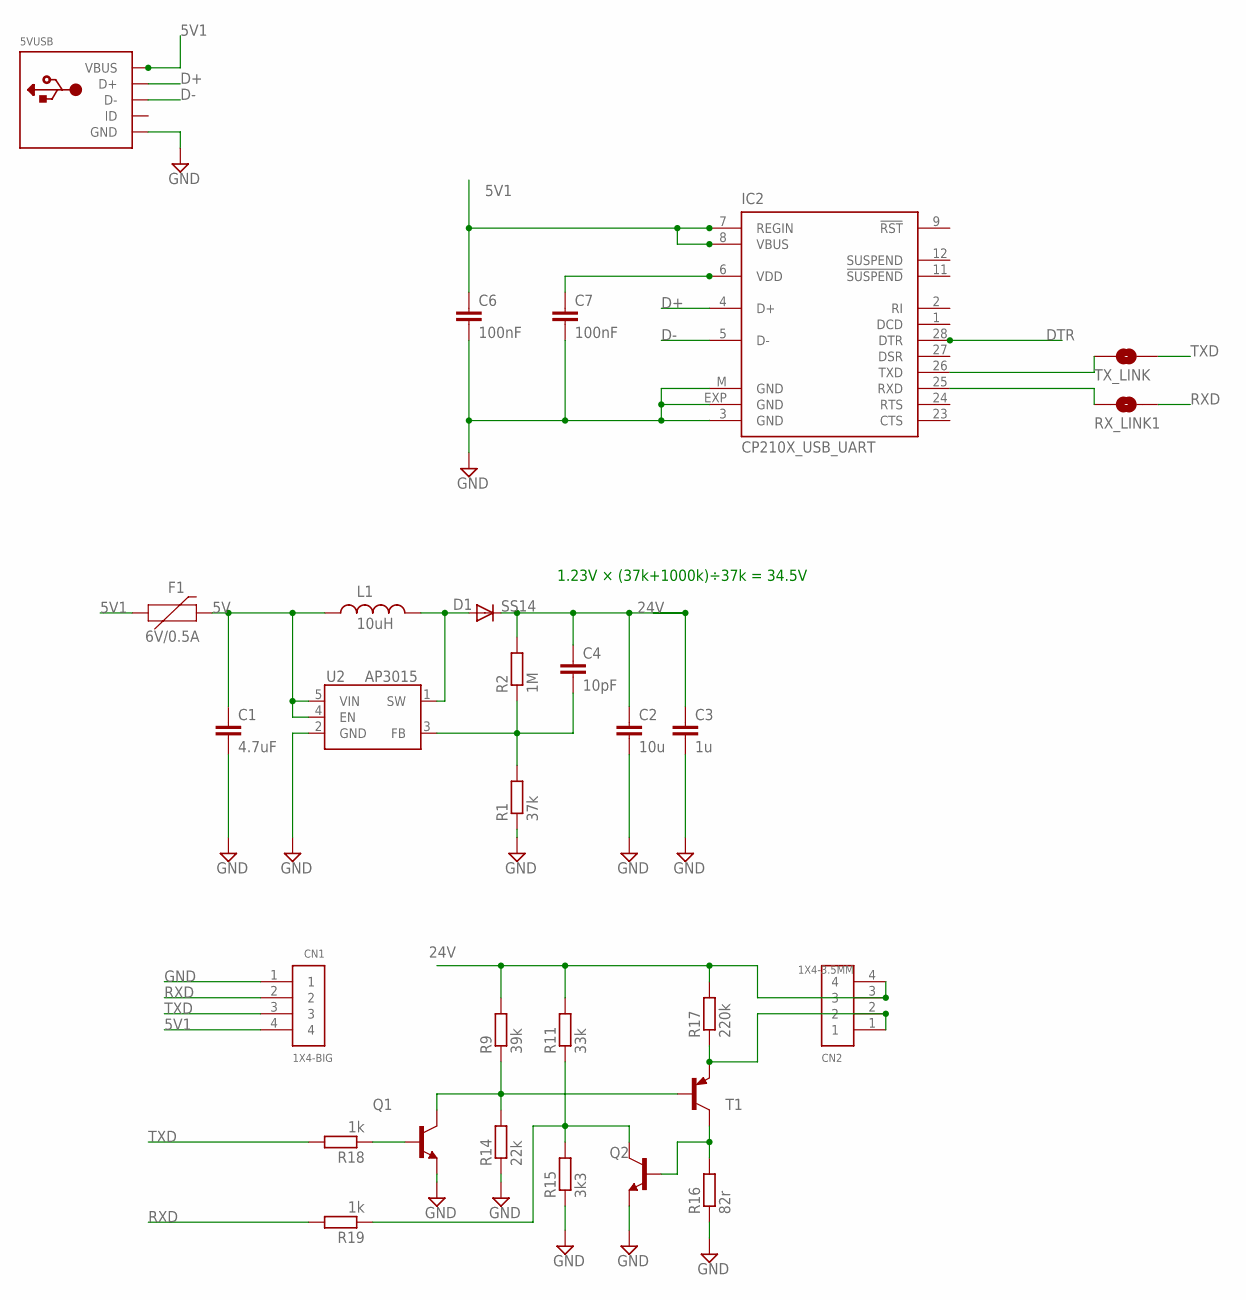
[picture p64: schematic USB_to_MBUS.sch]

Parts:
5VUSB: USBMOLEX; USB-MINIB-THM-MOLEX
C1: 4.7uF; 0603
C2: 10u; 1206
C3: 1u; 1206
C4: 10pF; 0603-CAP
C6, C7: 100nF; 0603-CAP
CN1: 1X4-BIG; 1X04-BIG
CN2: 1X4-3.5MM; 1X04-3.5MM
D1: SS14; SOD-123
F1: 6V/0.5A; 1206
IC2: CP210X_USB_UART; MLP28
L1: 10uH; CR54
Q1, Q2: BC808-NPN-SOT23-BEC; SOT23-BEC
R1: 37k; R0603
R2: 1M; R0603
R9: 39k; R0603
R11: 33k; R0603
R14: 22k; R0603
R15: 3k3; R0603
R16: 82r; R0603
R17: 220k; R0603
R18, R19: 1k; R0603
RX_LINK1: SOLDERJUMPERNC; SJ_2S
T1: BC807-16-PNP-SOT23-BEC; SOT23-BEC
TX_LINK: SOLDERJUMPERNC; SJ_2S
U2: AP3015; SOT-23-5

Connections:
5V: C1.1, F1.2, L1.P$1 (1), U2.4 (EN), U2.5 (VIN)
5V1: 5VUSB.VBUS, C6.1, CN1.4, F1.1, IC2.7 (REGIN), IC2.8 (VBUS)
24V: C2.1, C3.1, C4.1, CN2.3, CN2.4, D1.C, R2.2, R9.2, R11.2, R17.2
D+: 5VUSB.D+, IC2.4 (D+)
D-: 5VUSB.D-, IC2.5 (D-)
DTR: IC2.28 (DTR)
GND: 5VUSB.GND, C1.2, C2.2, C3.2, C6.2, C7.2, CN1.1, IC2.3 (GND), IC2.EXP (GND), IC2.M (GND), Q1.E, Q2.E, R1.1, R14.1, R15.1, R16.1, U2.2 (GND)
unnamed: C7.1, IC2.6 (VDD)
unnamed: C4.2, R1.2, R2.1, U2.3 (FB)
unnamed: D1.A, L1.P$2 (2), U2.1 (SW)
unnamed: IC2.26 (TXD), TX_LINK.1
unnamed: IC2.25 (RXD), RX_LINK1.1
unnamed: CN2.1, CN2.2, R17.1, T1.E
unnamed: Q2.B, R16.2, T1.C
unnamed: Q1.C, R9.1, R14.2, T1.B
unnamed: Q2.C, R11.1, R15.2, R19.1
unnamed: Q1.B, R18.1
RXD: CN1.2, R19.2, RX_LINK1.2
TXD: CN1.3, R18.2, TX_LINK.2

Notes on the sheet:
1.23V × (37k+1000k)÷37k = 34.5V

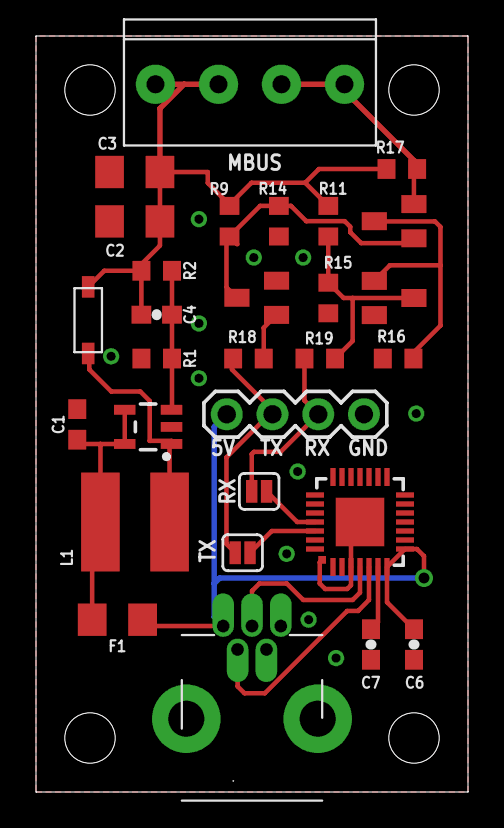
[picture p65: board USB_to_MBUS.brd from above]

Board: 2 copper layers, 24.0 x 42.0 mm, 30 parts (1 on the bottom side), 18 nets.

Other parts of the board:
LOGO1: OSHW_LOGO_6MILX0200-NT; OSHW_6X200_NOTEXT

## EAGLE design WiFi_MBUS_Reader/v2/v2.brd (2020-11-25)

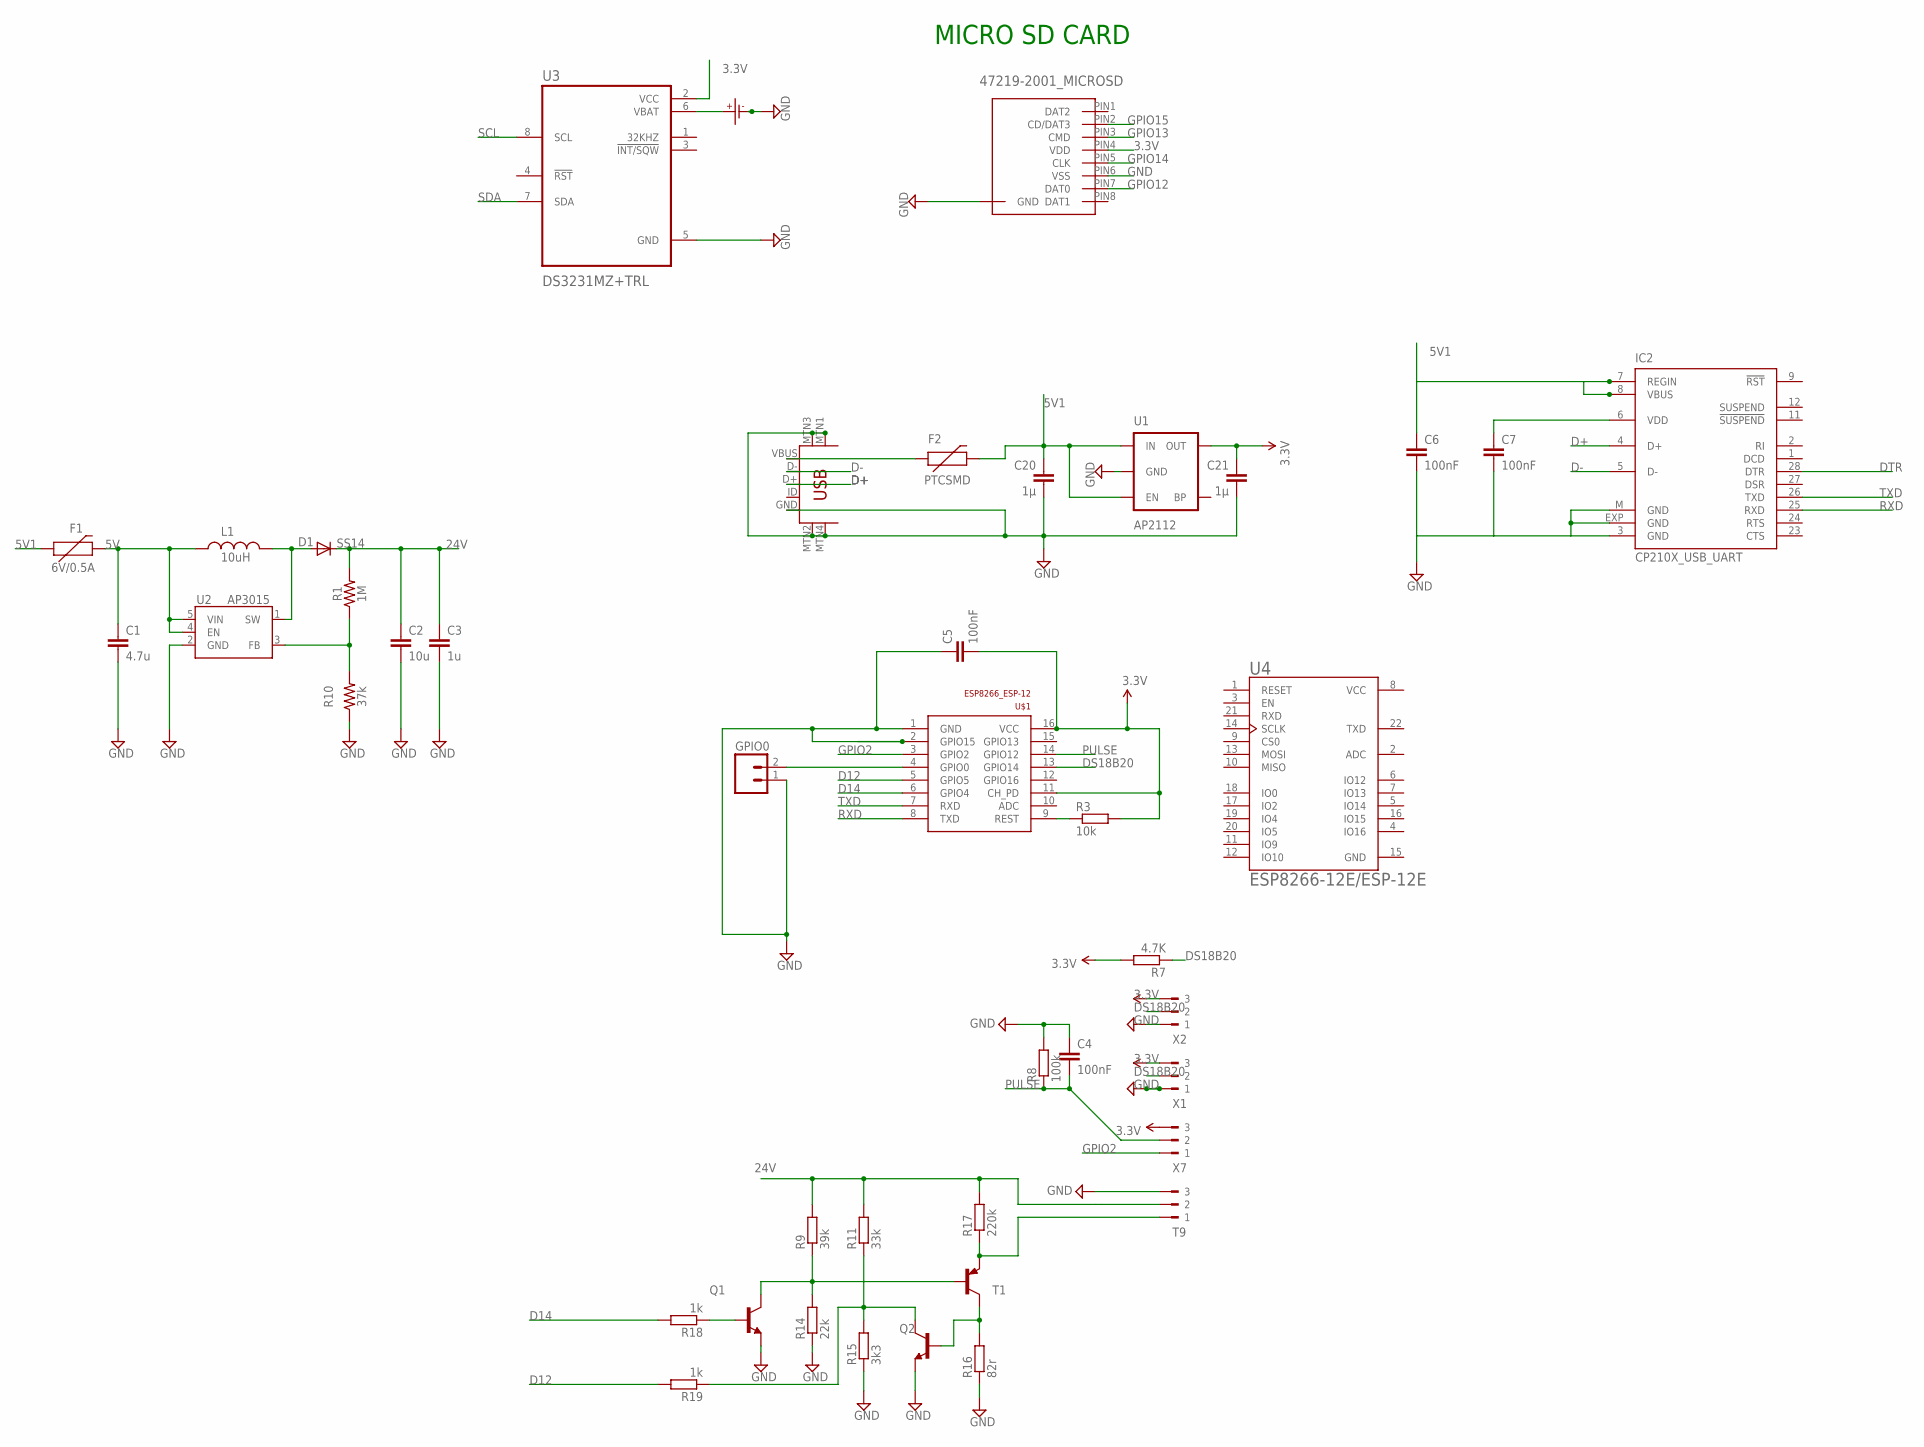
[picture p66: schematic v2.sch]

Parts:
C1: 4.7u; 0805
C2: 10u; 1206
C3: 1u; 1206
C4, C5: 100nF; C0603
C6, C7: 100nF; 0603-CAP
C20, C21: 1µ; C0603
CR1: CR1220SMD; MPN Harwin S8411-45R
D1: SS14; SOD-123
F1: 6V/0.5A; 1206
F2: PTCSMD; PTC-1206
GPIO0: M02PTH; 1X02
IC2: CP210X_USB_UART; MLP28
L1: 10uH; CR54
MICRO_SD: 47219-2001_MICROSD
Q1, Q2: BC808-NPN-SOT23-BEC; SOT23-BEC
R1: 1M; 0805
R3: 10k; R0603
R7: 4.7K; R0603
R8: 100k; R0603
R9: 39k; R0603
R10: 37k; 0805
R11: 33k; R0603
R14: 22k; R0603
R15: 3k3; R0603
R16: 82r; R0603
R17: 220k; R0603
R18, R19: 1k; R0603
T1: BC807-16-PNP-SOT23-BEC; SOT23-BEC
T9: 180-3
U1: AP2112; SOT23-5
U2: AP3015; SOT-23-5
U3: DS3231MZ+TRL; SOIC127P600X175-8N
U4: ESP8266-12E/ESP-12E; XCVR_ESP8266-12E/ESP-12E
U$1: ESP8266_ESP-12; ESP8266-ESP12
U$10: USB-MINIB-5PIN; USB-MINIB-CISECO
X1, X2, X7: 180-3

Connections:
3.3V: C5.2, C21.1, MICRO_SD.PIN4 (VDD), R3.2, R7.2, U1.5 (OUT), U3.2 (VCC), U$1.11 (CH_PD), U$1.16 (VCC), X1.3, X2.3, X7.3
5V: C1.1, F1.2, L1.P$1 (1), U2.4 (EN), U2.5 (VIN)
5V1: C6.1, C20.1, F1.1, F2.2, IC2.7 (REGIN), IC2.8 (VBUS), U1.1 (IN), U1.3 (EN)
24V: C2.1, C3.1, D1.C, R1.2, R9.2, R11.2, R17.2, T9.2
D12: R19.2, U$1.5 (GPIO5)
D14: R18.2, U$1.6 (GPIO4)
D+: IC2.4 (D+), U$10.D+
D-: IC2.5 (D-), U$10.D-
DS18B20: R7.1, U$1.13 (GPIO14), X1.2, X2.2
DTR: IC2.28 (DTR)
GND: C1.2, C2.2, C3.2, C4.1, C5.1, C6.2, C7.2, C20.2, C21.2, CR1.P- (P$-), GPIO0.1, IC2.3 (GND), IC2.EXP (GND), IC2.M (GND), MICRO_SD.P$1 (GND), MICRO_SD.P$2 (GND), MICRO_SD.P$3 (GND), MICRO_SD.P$4 (GND), MICRO_SD.PIN6 (VSS), Q1.E, Q2.E, R8.2, R10.1, R14.1, R15.1, R16.1, T9.3, U1.2 (GND), U2.2 (GND), U3.5 (GND), U4.15 (GND), U$1.1 (GND), U$1.2 (GPIO15), U$10.GND, U$10.MTN1 (MTN2), U$10.MTN2 (MTN3), U$10.MTN3 (MTN1), U$10.MTN4, X1.1, X2.1
GPIO2: U$1.3 (GPIO2), X7.1
GPIO12: MICRO_SD.PIN7 (DAT0)
GPIO13: MICRO_SD.PIN3 (CMD)
GPIO14: MICRO_SD.PIN5 (CLK)
GPIO15: MICRO_SD.PIN2 (CD/DAT3)
unnamed: C7.1, IC2.6 (VDD)
unnamed: F2.1, U$10.VBUS
unnamed: R1.1, R10.2, U2.3 (FB)
unnamed: D1.A, L1.P$2 (2), U2.1 (SW)
unnamed: CR1.P+ (P$+), U3.6 (VBAT)
unnamed: R17.1, T1.E, T9.1
unnamed: Q2.B, R16.2, T1.C
unnamed: Q1.C, R9.1, R14.2, T1.B
unnamed: Q2.C, R11.1, R15.2, R19.1
unnamed: Q1.B, R18.1
unnamed: GPIO0.2, U$1.4 (GPIO0)
unnamed: R3.1, U$1.9 (REST)
PULSE: C4.2, R8.1, U$1.14 (GPIO12), X7.2
RXD: IC2.25 (RXD), U$1.8 (TXD)
SCL: U3.8 (SCL)
SDA: U3.7 (SDA)
TXD: IC2.26 (TXD), U$1.7 (RXD)
VCC: U4.8 (VCC)

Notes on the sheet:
MICRO SD CARD

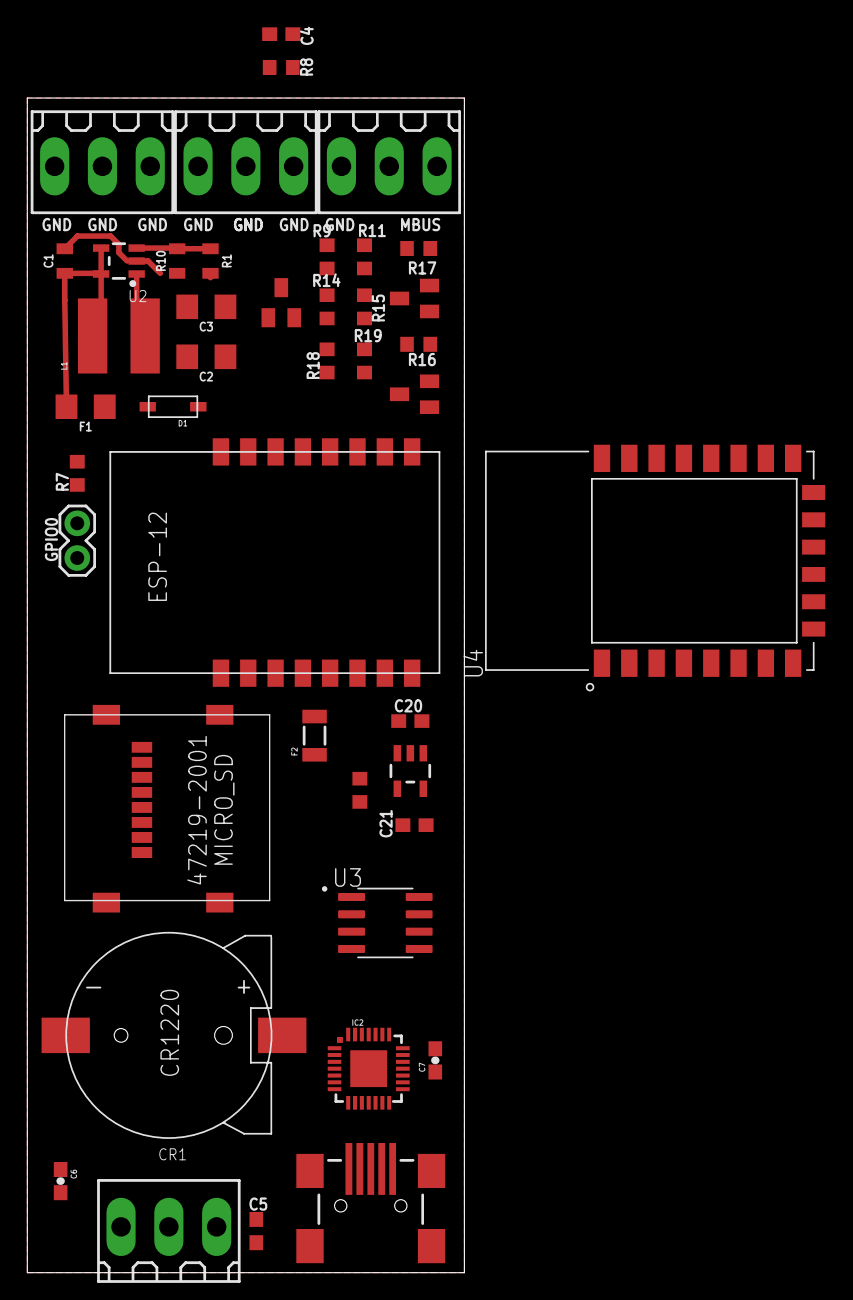
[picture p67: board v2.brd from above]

Board: 2 copper layers, 32.0 x 86.0 mm, 44 parts (1 on the bottom side), 26 nets.

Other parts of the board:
LOGO1: OSHW_LOGO_6MILX0200-NT; OSHW_6X200_NOTEXT

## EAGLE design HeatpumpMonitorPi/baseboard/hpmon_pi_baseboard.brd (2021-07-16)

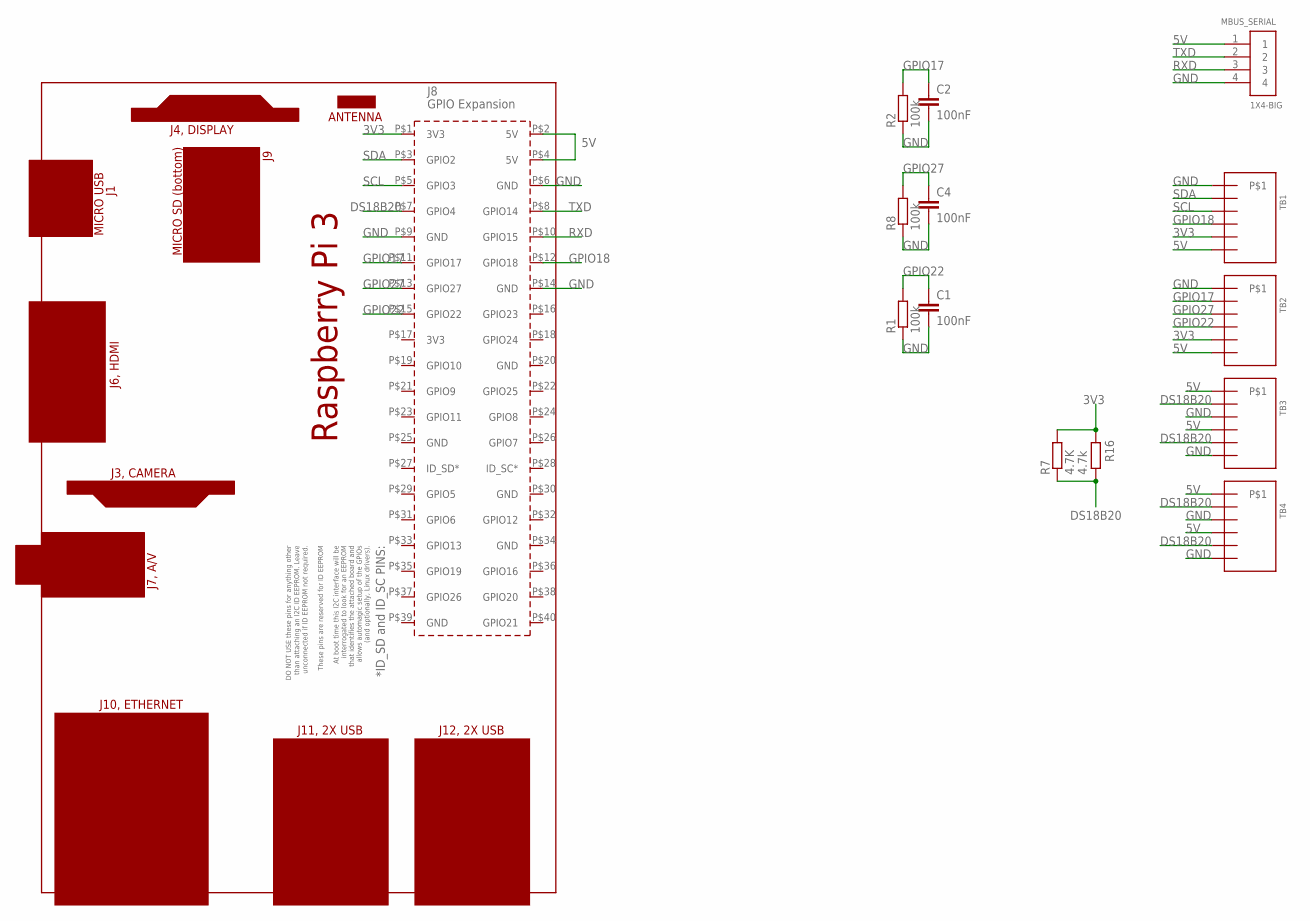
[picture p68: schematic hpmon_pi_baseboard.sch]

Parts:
C1, C2, C4: 100nF; C025-024X044
MBUS_SERIAL: 1X4-BIG; 1X04-BIG
PCB1: RPI3RPI3; RPI3
R1, R2, R8: 100k; 0207/2V
R7: 4.7K; 0204/7
R16: 4.7k; R0603
TB1, TB2, TB3, TB4: 3.5MM_TB_X6; 3.5MM_X6

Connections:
3V3: PCB1.P$1 (3V3), R7.2, R16.2, TB1.P$5, TB2.P$5
5V: MBUS_SERIAL.1, PCB1.P$2 (5V), PCB1.P$4 (5V), TB1.P$6, TB2.P$6, TB3.P$1, TB3.P$4, TB4.P$1, TB4.P$4
DS18B20: PCB1.P$7 (GPIO4), R7.1, R16.1, TB3.P$2, TB3.P$5, TB4.P$2, TB4.P$5
GND: C1.2, C2.2, C4.2, MBUS_SERIAL.4, PCB1.P$6 (GND), PCB1.P$9 (GND), PCB1.P$14 (GND), R1.1, R2.1, R8.1, TB1.P$1, TB2.P$1, TB3.P$3, TB3.P$6, TB4.P$3, TB4.P$6
GPIO17: C2.1, PCB1.P$11 (GPIO17), R2.2, TB2.P$2
GPIO18: PCB1.P$12 (GPIO18), TB1.P$4
GPIO22: C1.1, PCB1.P$15 (GPIO22), R1.2, TB2.P$4
GPIO27: C4.1, PCB1.P$13 (GPIO27), R8.2, TB2.P$3
RXD: MBUS_SERIAL.3, PCB1.P$10 (GPIO15)
SCL: PCB1.P$5 (GPIO3), TB1.P$3
SDA: PCB1.P$3 (GPIO2), TB1.P$2
TXD: MBUS_SERIAL.2, PCB1.P$8 (GPIO14)

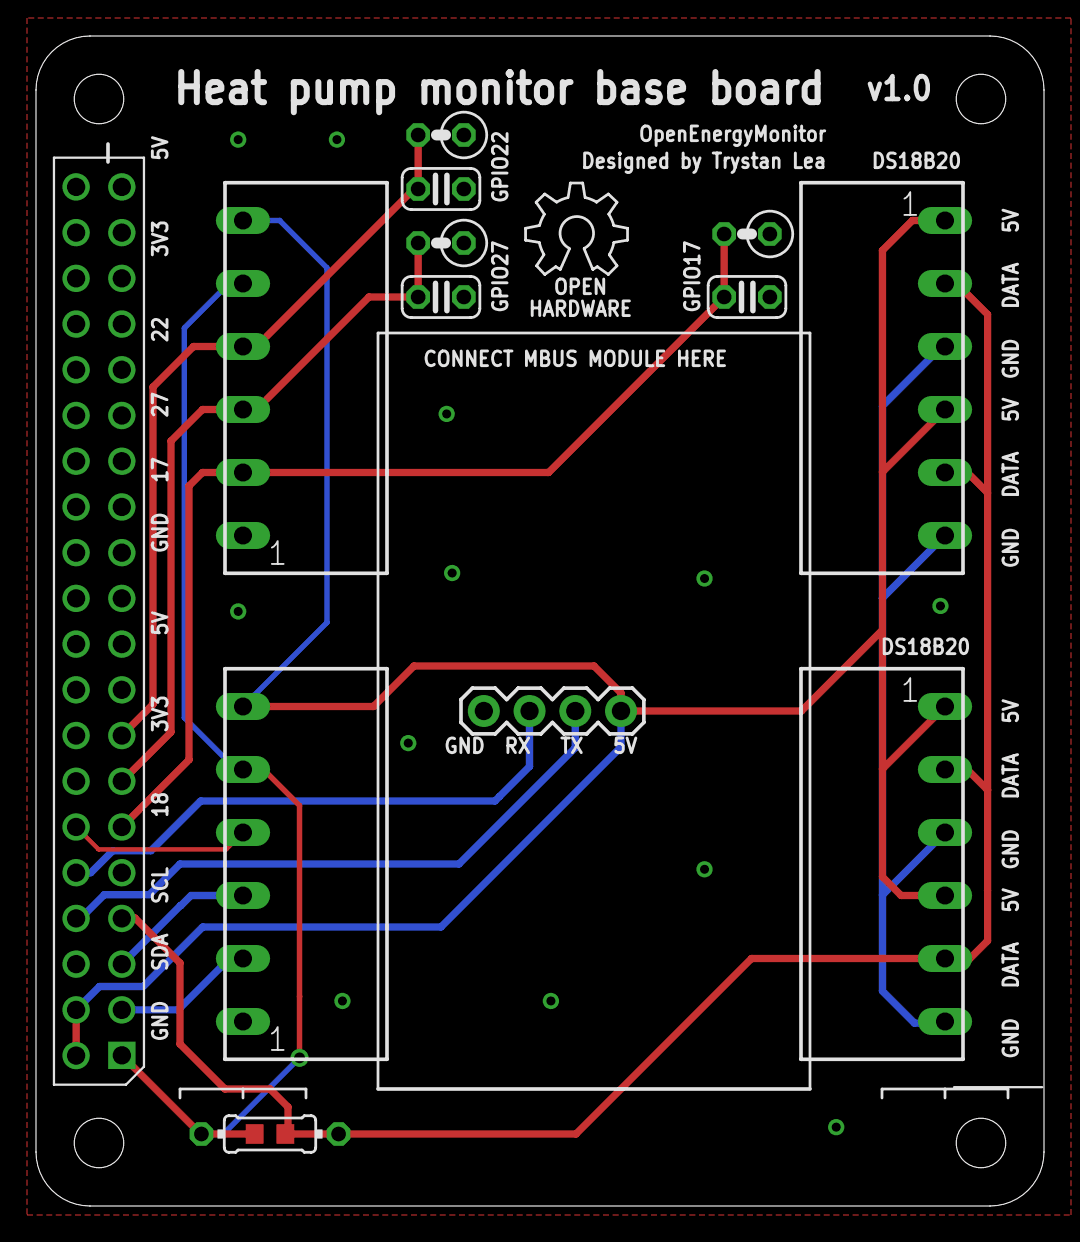
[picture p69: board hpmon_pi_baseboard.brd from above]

Board: 2 copper layers, 56.0 x 65.0 mm, 15 parts (0 on the bottom side), 12 nets.

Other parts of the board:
LOGO2: OSHW_LOGO_6MILX0200-NT; OSHW_6X200_NOTEXT

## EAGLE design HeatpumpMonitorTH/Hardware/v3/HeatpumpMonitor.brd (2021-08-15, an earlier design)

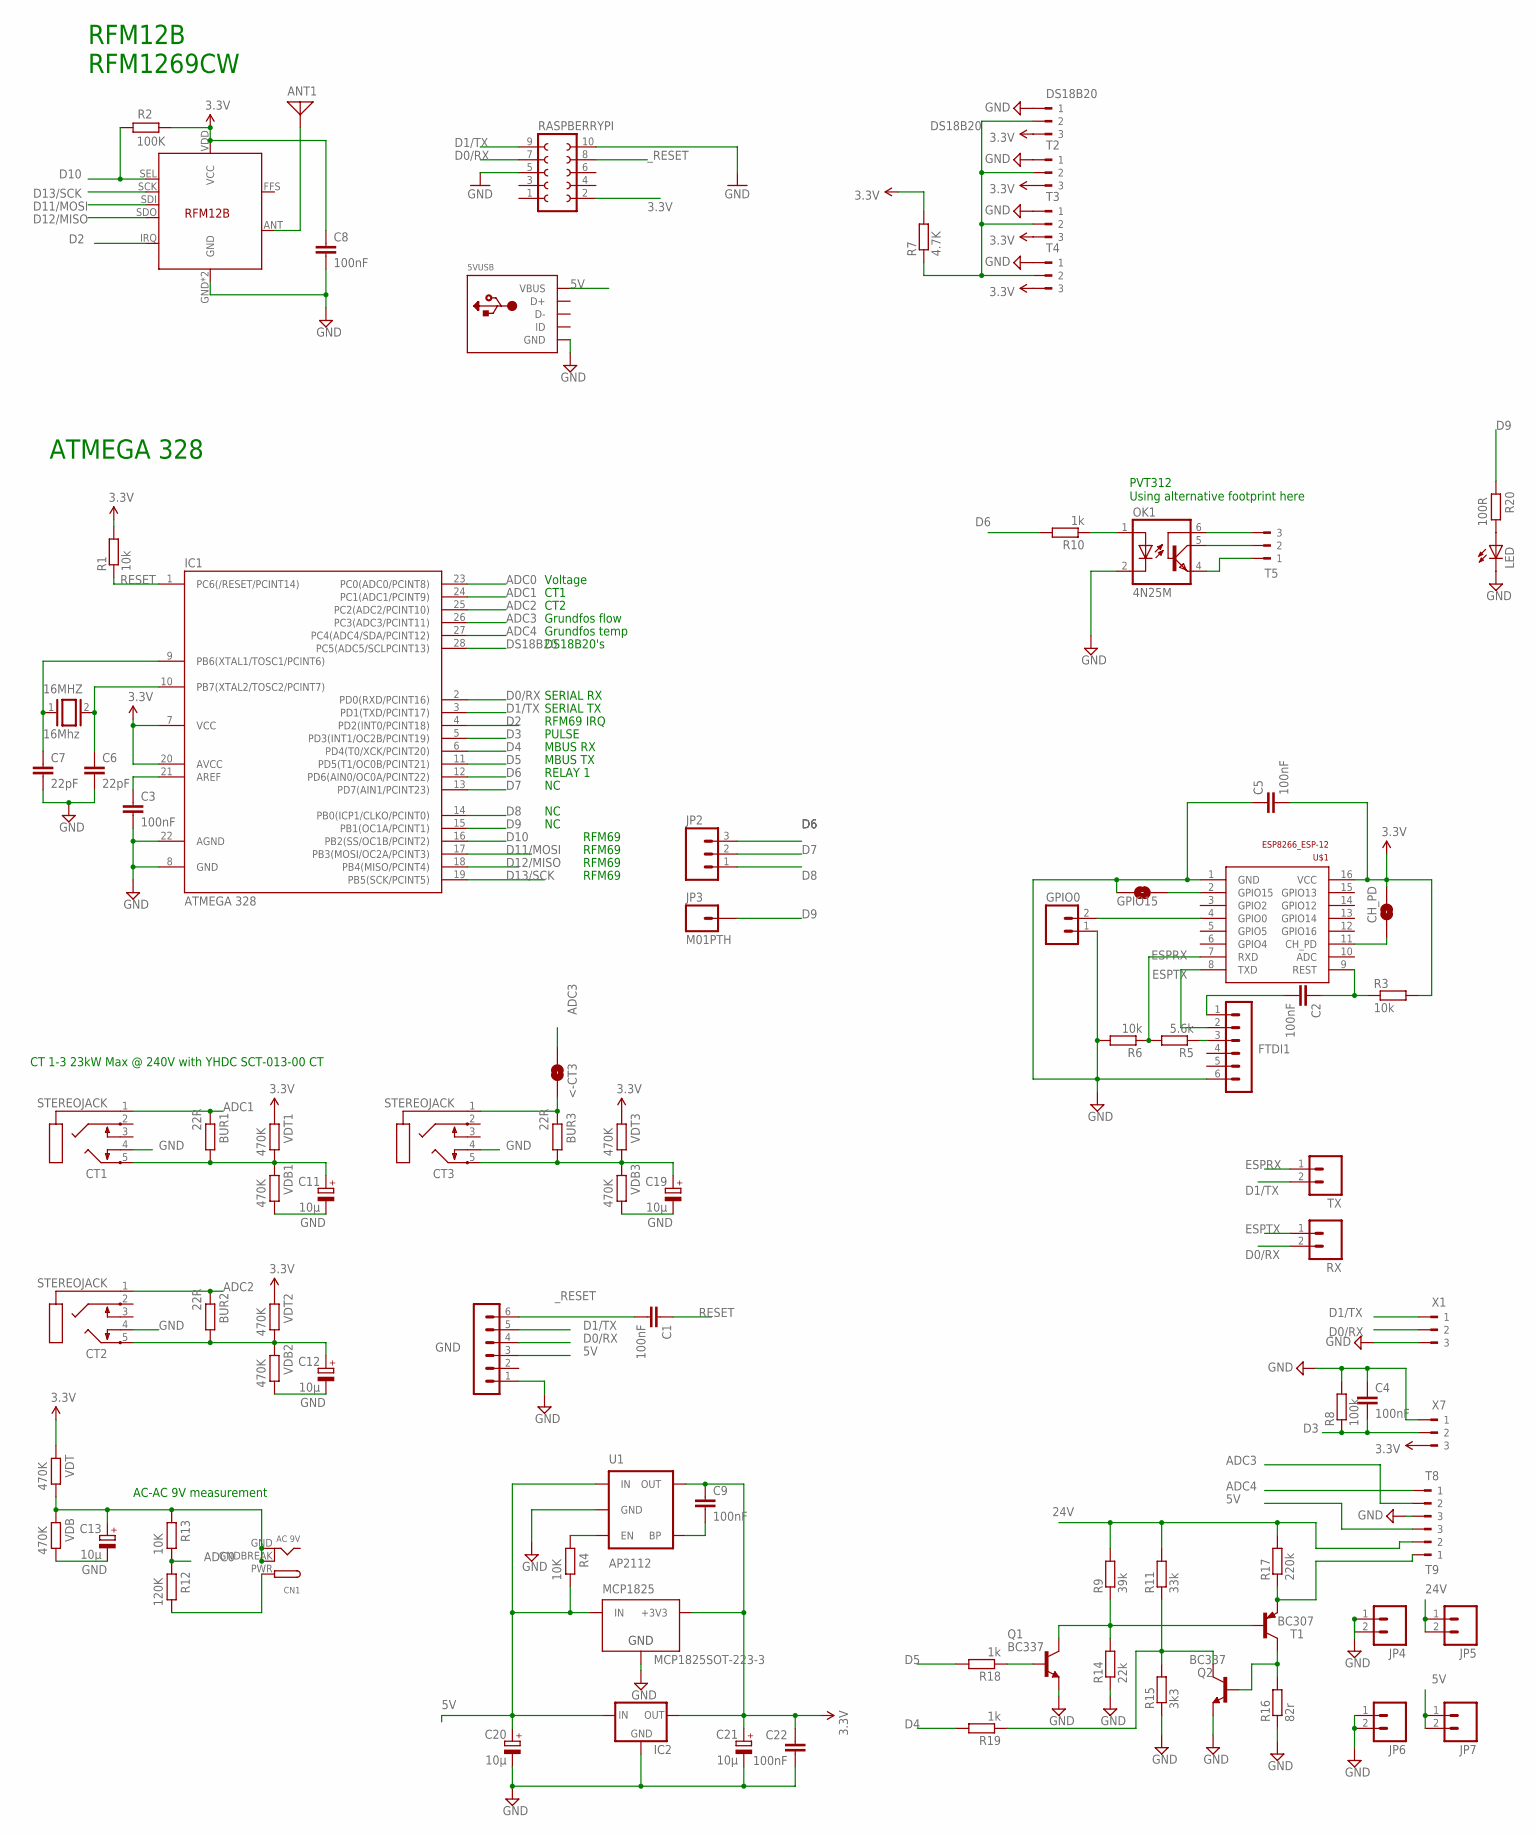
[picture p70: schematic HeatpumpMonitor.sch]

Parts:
5VUSB: USBMOLEX; USB-MINIB-THM-MOLEX
16MHZ: 16Mhz; QS
<-CT3: SOLDERJUMPERNO; SJ_2S-NO
ANT1: ANTENNA; PAD-01
BUR1, BUR2, BUR3: 22R; 0204/7
C1, C2, C3, C4, C5, C8, C22: 100nF; C025-024X044
C6, C7: 22pF; C2.5-2
C9: 100nF; C0603
C11, C12, C13, C19, C20, C21: 10µ; E1,8-4
CH_PD: SOLDERJUMPERNO; SJ_2S-NO
CN1: AC 9V; DCJACK_2MM_PTH
CT1, CT2, CT3: STEREOJACK; STX3100
DS18B20: 180-3
FTDI1: FTDI; MA06-1
GND: FTDI; MA06-1
GPIO0: M02PTH; 1X02
GPIO15: SOLDERJUMPERNO; SJ_2S-NO
IC1: ATMEGA 328; DIL28-3
IC2: 78XXS
JP2: M03PTH; 1X03
JP3: M01PTH; 1X01
JP4, JP5, JP6, JP7: M02PTH; 1X02
LED: LED3MM
MCP1825: MCP1825SOT-223-3; SOT-223
OK1: 4N25M; DIL06
Q1, Q2: BC337; TO92
R1, R3, R6: 10k; 0204/7
R2: 100K; 0204/7
R4: 10K; R0603
R5: 5.6k; 0204/7
R7: 4.7K; 0204/7
R8: 100k; 0207/2V
R9: 39k; 0204/7
R10, R18, R19: 1k; 0204/7
R11: 33k; 0204/7
R12: 120K; 0204/7
R13: 10K; 0204/7
R14: 22k; 0204/7
R15: 3k3; 0204/7
R16: 82r; 0204/7
R17: 220k; 0204/7
R20: 100R; 0204/7
RASPBERRYPI: FE05-2
RX: M02PTH; 1X02
T1: BC307; TO92
T2, T3, T4, T5, T8, T9: 180-3
TX: M02PTH; 1X02
U1: AP2112; SOT23-5
U$1: ESP8266_ESP-12; ESP8266-ESP12
U$14: RFM12B
VDB, VDB1, VDB2, VDB3: 470K; 0204/7
VDT, VDT1, VDT2, VDT3: 470K; 0204/7
X1, X7: 180-3

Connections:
3.3V: C5.2, C8.1, C9.1, C21.+, C22.1, CH_PD.1, DS18B20.3, IC1.7 (VCC), IC1.20 (AVCC), IC2.OUT, MCP1825.3 (+3V3), R1.2, R2.1, R3.2, R7.2, RASPBERRYPI.2, T2.3, T3.3, T4.3, U1.5 (OUT), U$1.16 (VCC), U$14.VDD (VCC), VDT.2, VDT1.2, VDT2.2, VDT3.2, X7.3
5V: 5VUSB.VBUS, C20.+, GND.3, IC2.IN, JP7.1, JP7.2, MCP1825.1 (IN), R4.1, T9.3, U1.1 (IN)
24V: JP5.1, JP5.2, R9.2, R11.2, R17.2, T9.2
AC: CN1.PWR, R12.1
ADC0: IC1.23 (PC0(ADC0/PCINT8)), R12.2, R13.1
ADC1: BUR1.2, CT1.1, IC1.24 (PC1(ADC1/PCINT9))
ADC2: BUR2.2, CT2.1, IC1.25 (PC2(ADC2/PCINT10))
ADC3: <-CT3.2, IC1.26 (PC3(ADC3/PCINT11)), T8.2
ADC4: IC1.27 (PC4(ADC4/SDA/PCINT12)), T8.1
D0/RX: GND.4, IC1.2 (PD0(RXD/PCINT16)), RASPBERRYPI.7, RX.2, X1.2
D1/TX: GND.5, IC1.3 (PD1(TXD/PCINT17)), RASPBERRYPI.9, TX.2, X1.1
D2: IC1.4 (PD2(INT0/PCINT18)), U$14.IRQ
D3: C4.2, IC1.5 (PD3(INT1/OC2B/PCINT19)), R8.1, X7.2
D4: IC1.6 (PD4(T0/XCK/PCINT20)), R19.2
D5: IC1.11 (PD5(T1/OC0B/PCINT21)), R18.2
D6: IC1.12 (PD6(AIN0/OC0A/PCINT22)), JP2.3, R10.2
D7: IC1.13 (PD7(AIN1/PCINT23)), JP2.2
D8: IC1.14 (PB0(ICP1/CLKO/PCINT0)), JP2.1
D9: IC1.15 (PB1(OC1A/PCINT1)), JP3.1, R20.2
D10: IC1.16 (PB2(SS/OC1B/PCINT2)), R2.2, U$14.SEL
D11/MOSI: IC1.17 (PB3(MOSI/OC2A/PCINT3)), U$14.SDI
D12/MISO: IC1.18 (PB4(MISO/PCINT4)), U$14.SDO
D13/SCK: IC1.19 (PB5(SCK/PCINT5)), U$14.SCK
DIG1: ANT1.1, U$14.ANT
DS18B20: DS18B20.2, IC1.28 (PC5(ADC5/SCLPCINT13)), R7.1, T2.2, T3.2, T4.2
ESPRX: R5.2, R6.1, TX.1, U$1.7 (RXD)
ESPTX: FTDI1.2, RX.1, U$1.8 (TXD)
GND: 5VUSB.GND, C3.2, C4.1, C5.1, C6.2, C7.2, C8.2, C11.-, C12.-, C13.-, C19.-, C20.-, C21.-, C22.2, CT1.4, CT2.4, CT3.4, DS18B20.1, FTDI1.6, GND.1, GPIO0.1, GPIO15.2, IC1.8 (GND), IC1.22 (AGND), IC2.GND, JP4.1, JP4.2, JP6.1, JP6.2, LED.K (C), MCP1825.2 (GND), OK1.2 (C), Q1.1 (E), Q2.1 (E), R6.2, R8.2, R14.1, R15.1, R16.1, RASPBERRYPI.5, RASPBERRYPI.10, T2.1, T3.1, T4.1, T8.3, U1.2 (GND), U$1.1 (GND), U$14.GND, U$14.P$12 (GND), VDB.1, VDB1.1, VDB2.1, VDB3.1, X1.3, X7.1
unnamed: 16MHZ.2, C6.1, IC1.10 (PB7(XTAL2/TOSC2/PCINT7))
unnamed: BUR2.1, C12.+, CT2.5, VDB2.2, VDT2.1
unnamed: C2.2, FTDI1.1
unnamed: <-CT3.1, BUR3.2, CT3.1
unnamed: OK1.1 (A), R10.1
unnamed: OK1.6 (BAS), T5.3
unnamed: C9.2, U1.4 (BP)
unnamed: BUR3.1, C19.+, CT3.5, VDB3.2, VDT3.1
unnamed: OK1.5 (COL), T5.2
unnamed: OK1.4 (EMI), T5.1
unnamed: R4.2, U1.3 (EN)
unnamed: 16MHZ.1, C7.1, IC1.9 (PB6(XTAL1/TOSC1/PCINT6))
unnamed: R17.1, T1.1 (E), T9.1
unnamed: LED.A, R20.1
unnamed: Q2.2 (B), R16.2, T1.3 (C)
unnamed: Q1.3 (C), R9.1, R14.2, T1.2 (B)
unnamed: C3.1, IC1.21 (AREF)
unnamed: Q2.3 (C), R11.1, R15.2, R19.1
unnamed: Q1.2 (B), R18.1
unnamed: GPIO15.1, U$1.2 (GPIO15)
unnamed: GPIO0.2, U$1.4 (GPIO0)
unnamed: C13.+, CN1.GND, CN1.GNDBREAK, R13.2, VDB.2, VDT.1
unnamed: FTDI1.3, R5.1
unnamed: BUR1.1, C11.+, CT1.5, VDB1.2, VDT1.1
unnamed: CH_PD.2, U$1.11 (CH_PD)
unnamed: C2.1, R3.1, U$1.9 (REST)
RESET: C1.1, IC1.1 (PC6(/RESET/PCINT14)), R1.1
_RESET: C1.2, GND.6, RASPBERRYPI.8

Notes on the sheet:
ATMEGA 328
RFM12B RFM1269CW
CT 1-3 23kW Max @ 240V with YHDC SCT-013-00 CT
AC-AC 9V measurement
Voltage
CT1
CT2
SERIAL RX
SERIAL TX
RFM69 IRQ
MBUS RX
MBUS TX
PULSE
Grundfos flow
Grundfos temp
DS18B20's
RELAY 1
RFM69
PVT312 Using alternative footprint here

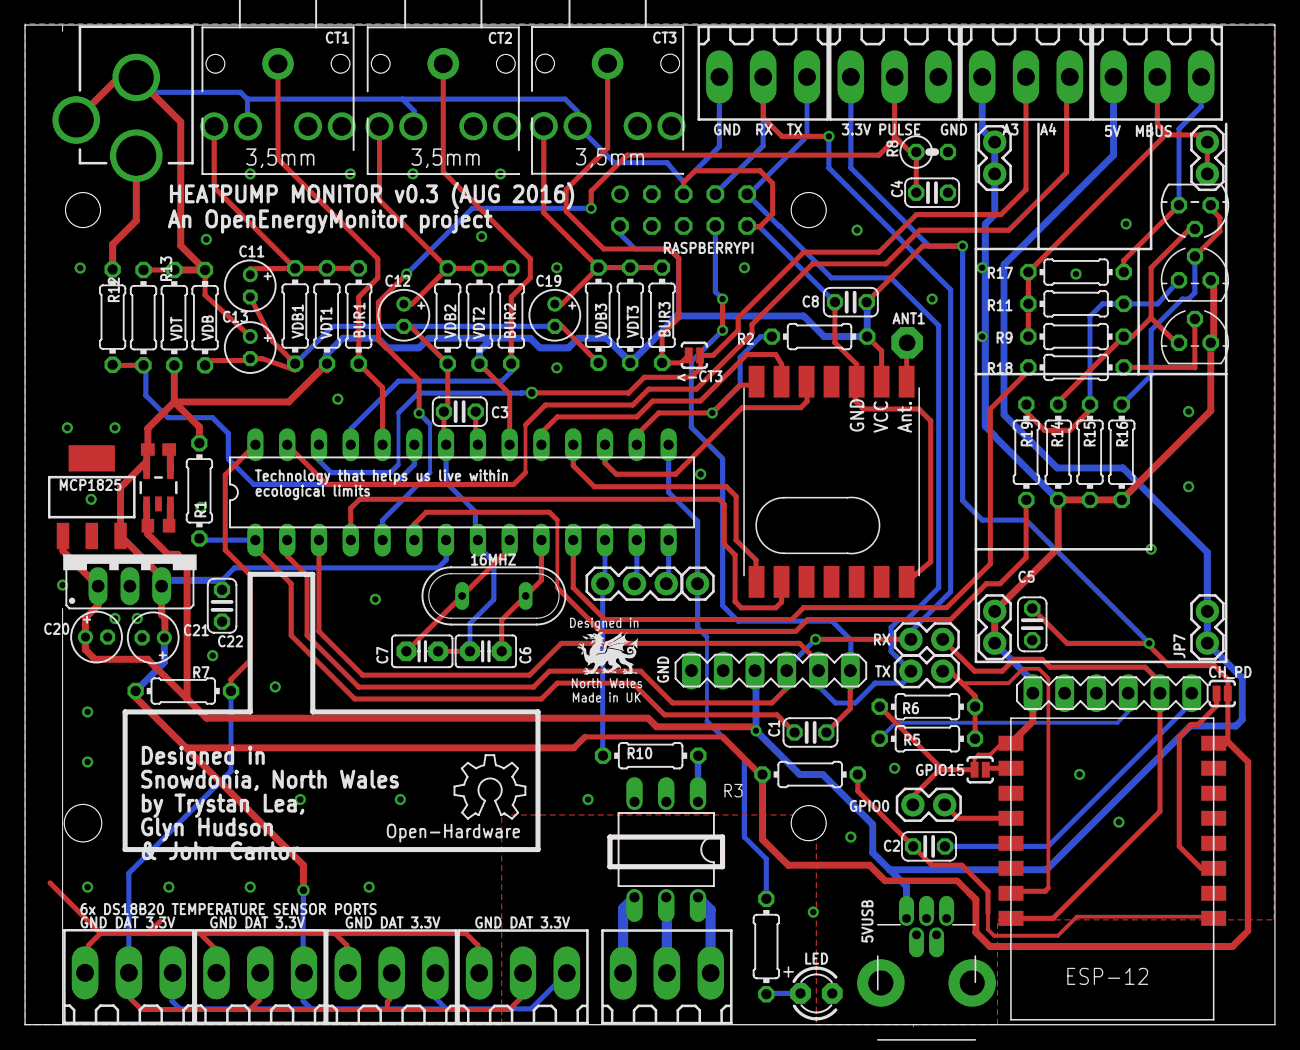
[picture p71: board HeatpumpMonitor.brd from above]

Board: 2 copper layers, 99.9 x 79.9 mm, 90 parts (0 on the bottom side), 56 nets.

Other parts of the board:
LOGO1: OSHW_LOGO_6MILX0200-NT; OSHW_6X200_NOTEXT

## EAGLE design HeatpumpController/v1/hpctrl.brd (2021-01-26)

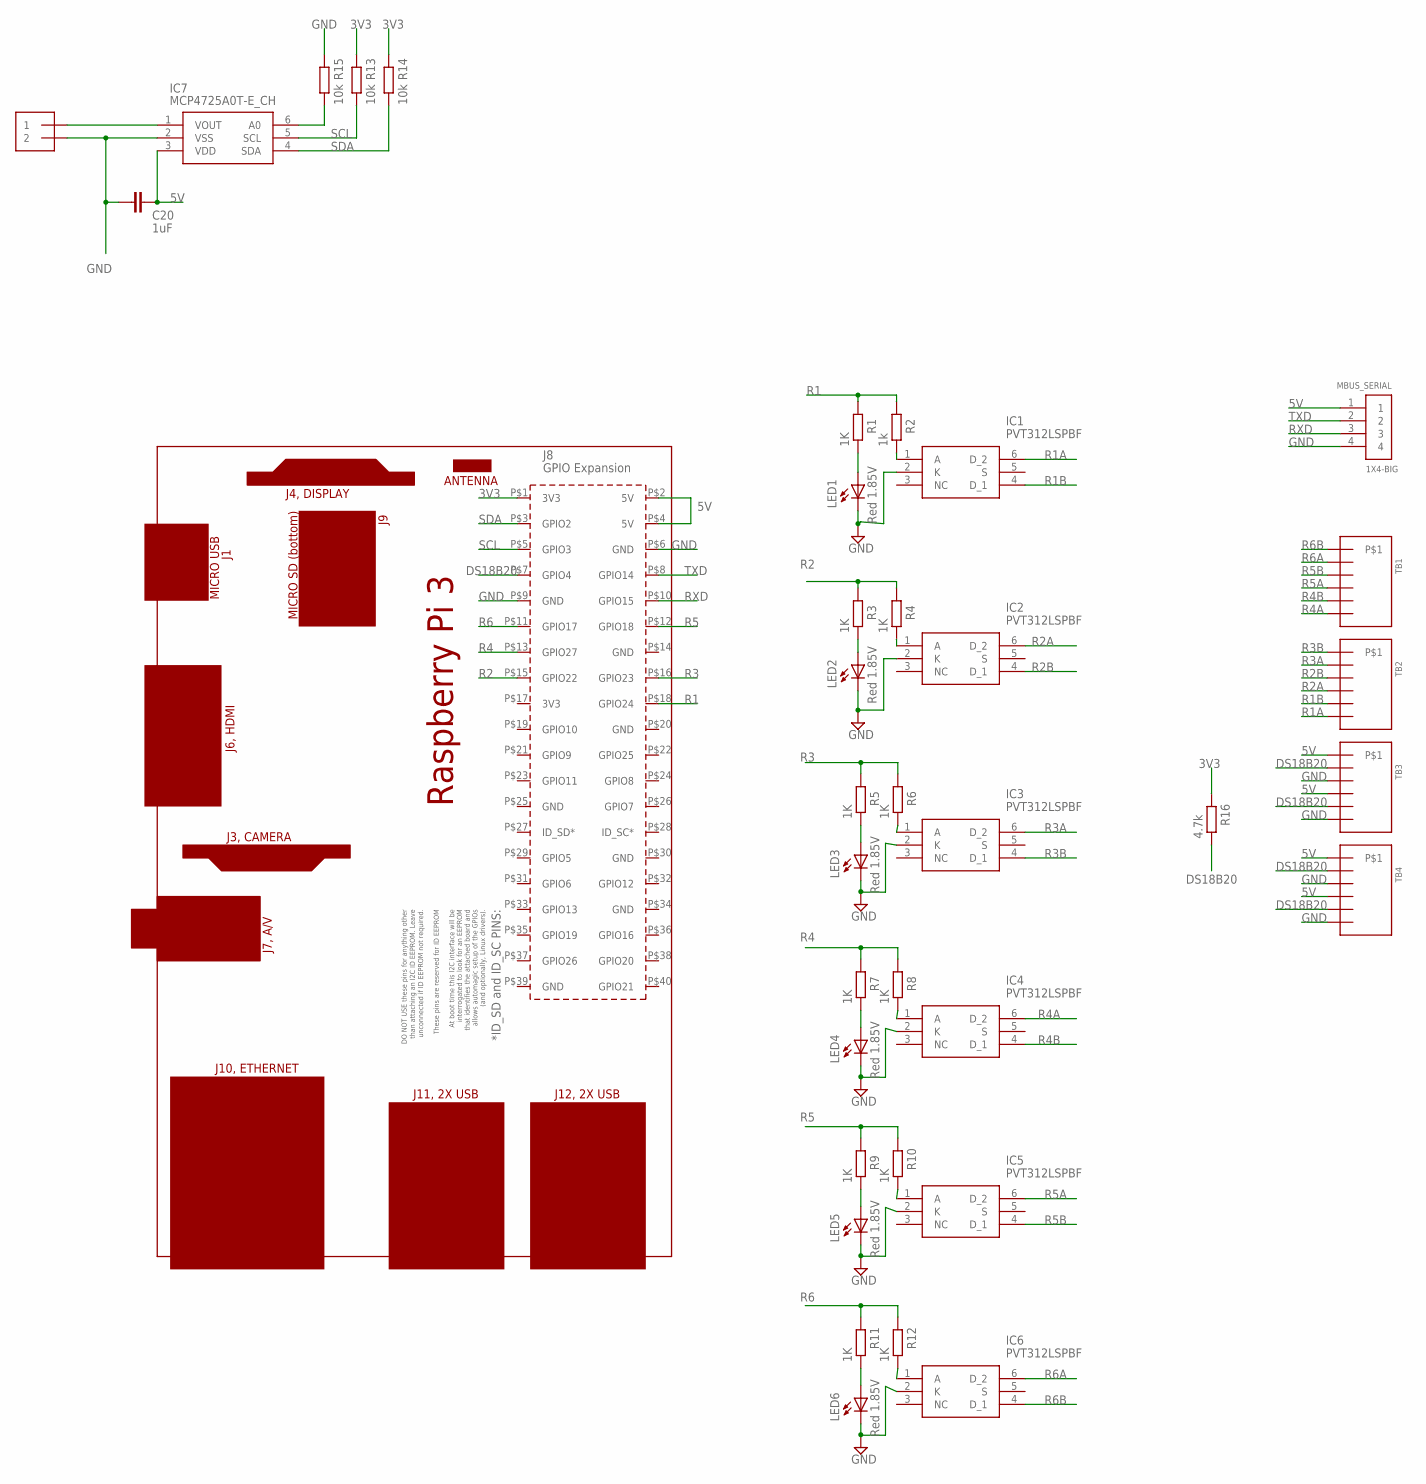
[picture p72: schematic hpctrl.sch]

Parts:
C20: 1uF; C0805
IC1, IC2, IC3, IC4, IC5, IC6: PVT312LSPBF; SOP254P978X342-6N
IC7: MCP4725A0T-E_CH; SOT95P270X145-6N
J1: 1X2-3.5MM
LED1, LED2, LED3, LED4, LED5, LED6: Red 1.85V; CHIP-LED0805
MBUS_SERIAL: 1X4-BIG; 1X04-BIG
PCB1: RPI3RPI3; RPI3
R1, R3, R4, R5, R6, R7, R8, R9, R10, R11, R12: 1K; R0603
R2: 1k; R0603
R13, R14, R15: 10k; R0603
R16: 4.7k; R0603
TB1, TB2, TB3, TB4: 3.5MM_TB_X6; 3.5MM_X6

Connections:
3V3: PCB1.P$1 (3V3), R13.2, R14.2, R16.2
5V: C20.1, IC7.3 (VDD), MBUS_SERIAL.1, PCB1.P$2 (5V), PCB1.P$4 (5V), TB3.P$1, TB3.P$4, TB4.P$1, TB4.P$4
DS18B20: PCB1.P$7 (GPIO4), R16.1, TB3.P$2, TB3.P$5, TB4.P$2, TB4.P$5
GND: C20.2, IC1.2 (K), IC2.2 (K), IC3.2 (K), IC4.2 (K), IC5.2 (K), IC6.2 (K), IC7.2 (VSS), J1.2, LED1.C, LED2.C, LED3.C, LED4.C, LED5.C, LED6.C, MBUS_SERIAL.4, PCB1.P$6 (GND), PCB1.P$9 (GND), R15.2, TB3.P$3, TB3.P$6, TB4.P$3, TB4.P$6
unnamed: IC1.1 (A), R2.1
unnamed: IC7.1 (VOUT), J1.1
unnamed: LED2.A, R3.1
unnamed: IC2.1 (A), R4.1
unnamed: LED3.A, R5.1
unnamed: IC3.1 (A), R6.1
unnamed: LED4.A, R7.1
unnamed: IC4.1 (A), R8.1
unnamed: LED5.A, R9.1
unnamed: IC5.1 (A), R10.1
unnamed: LED6.A, R11.1
unnamed: IC6.1 (A), R12.1
unnamed: IC7.6 (A0), R15.1
unnamed: LED1.A, R1.1
R1: PCB1.P$18 (GPIO24), R1.2, R2.2
R1A: IC1.6 (D_2), TB2.P$6
R1B: IC1.4 (D_1), TB2.P$5
R2: PCB1.P$15 (GPIO22), R3.2, R4.2
R2A: IC2.6 (D_2), TB2.P$4
R2B: IC2.4 (D_1), TB2.P$3
R3: PCB1.P$16 (GPIO23), R5.2, R6.2
R3A: IC3.6 (D_2), TB2.P$2
R3B: IC3.4 (D_1), TB2.P$1
R4: PCB1.P$13 (GPIO27), R7.2, R8.2
R4A: IC4.6 (D_2), TB1.P$6
R4B: IC4.4 (D_1), TB1.P$5
R5: PCB1.P$12 (GPIO18), R9.2, R10.2
R5A: IC5.6 (D_2), TB1.P$4
R5B: IC5.4 (D_1), TB1.P$3
R6: PCB1.P$11 (GPIO17), R11.2, R12.2
R6A: IC6.6 (D_2), TB1.P$2
R6B: IC6.4 (D_1), TB1.P$1
RXD: MBUS_SERIAL.3, PCB1.P$10 (GPIO15)
SCL: IC7.5 (SCL), PCB1.P$5 (GPIO3), R13.1
SDA: IC7.4 (SDA), PCB1.P$3 (GPIO2), R14.1
TXD: MBUS_SERIAL.2, PCB1.P$8 (GPIO14)

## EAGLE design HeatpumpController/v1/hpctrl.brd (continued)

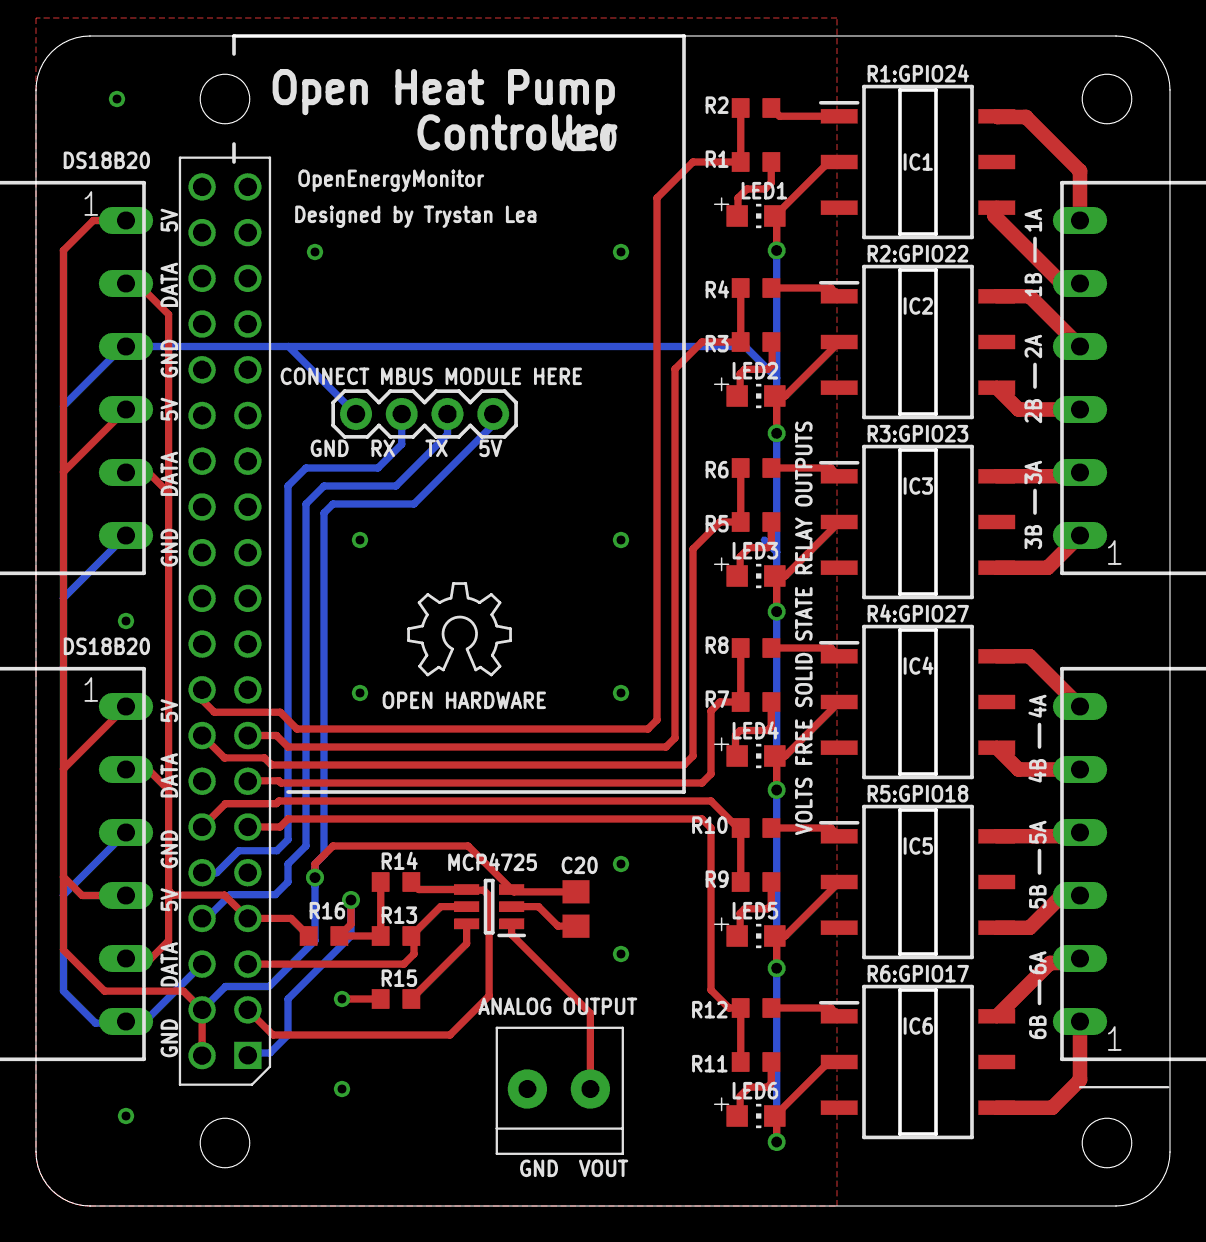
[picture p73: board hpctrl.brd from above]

Board: 2 copper layers, 63.0 x 65.0 mm, 38 parts (0 on the bottom side), 40 nets.

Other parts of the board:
LOGO2: OSHW_LOGO_6MILX0200-NT; OSHW_6X200_NOTEXT

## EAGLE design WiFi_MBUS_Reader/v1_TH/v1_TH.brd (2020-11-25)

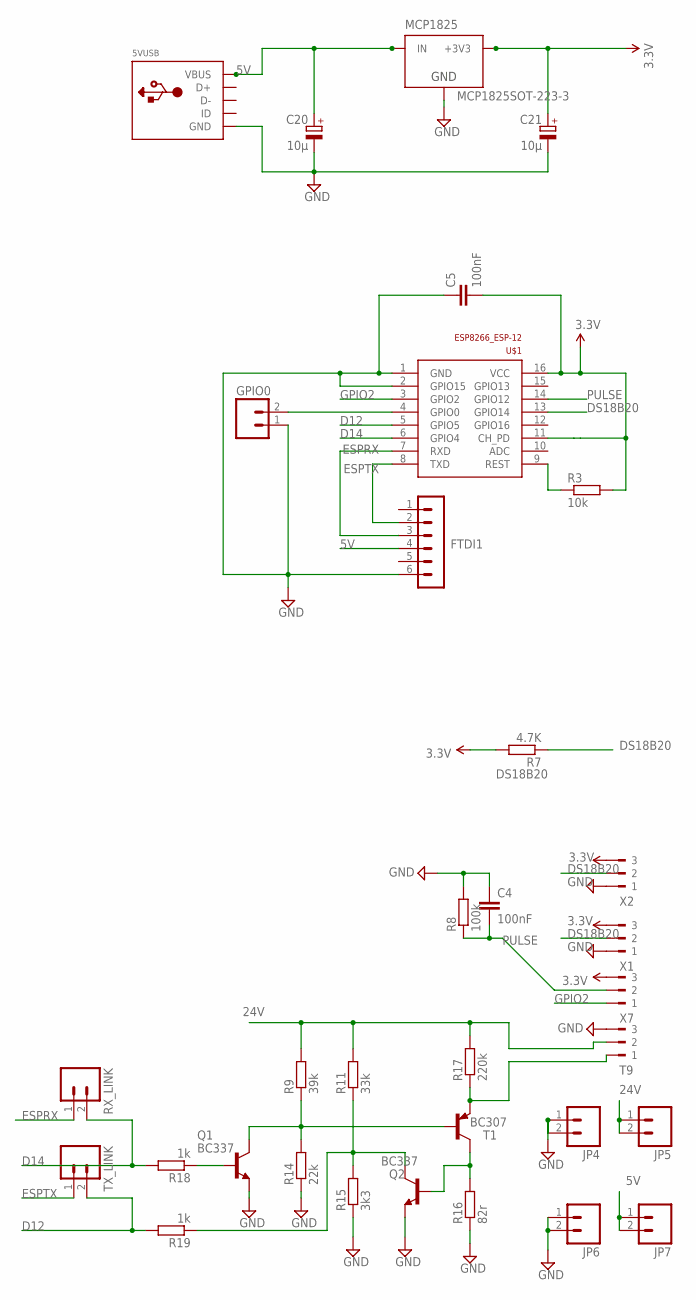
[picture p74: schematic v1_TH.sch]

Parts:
5VUSB: USBMOLEX; USB-MINIB-THM-MOLEX
C4, C5: 100nF; C025-024X044
C20, C21: 10µ; E1,8-4
FTDI1: FTDI; MA06-1
GPIO0: M02PTH; 1X02
JP4, JP5, JP6, JP7: M02PTH; 1X02
MCP1825: MCP1825SOT-223-3; SOT-223
Q1, Q2: BC337; TO92
R3: 10k; 0204/7
R7: 4.7K; 0204/7
R8: 100k; 0207/2V
R9: 39k; 0204/7
R11: 33k; 0204/7
R14: 22k; 0204/7
R15: 3k3; 0204/7
R16: 82r; 0204/7
R17: 220k; 0204/7
R18, R19: 1k; 0204/7
RX_LINK: M02PTH; 1X02
T1: BC307; TO92
T9: 180-3
TX_LINK: M02PTH; 1X02
U$1: ESP8266_ESP-12; ESP8266-ESP12
X1, X2, X7: 180-3

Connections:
3.3V: C5.2, C21.+, MCP1825.3 (+3V3), R3.2, R7.2, U$1.11 (CH_PD), U$1.16 (VCC), X1.3, X2.3, X7.3
5V: 5VUSB.VBUS, C20.+, FTDI1.4, JP7.1, JP7.2, MCP1825.1 (IN)
24V: JP5.1, JP5.2, R9.2, R11.2, R17.2, T9.2
D12: R19.2, TX_LINK.2, U$1.5 (GPIO5)
D14: R18.2, RX_LINK.2, U$1.6 (GPIO4)
DS18B20: R7.1, U$1.13 (GPIO14), X1.2, X2.2
ESPRX: FTDI1.3, RX_LINK.1, U$1.7 (RXD)
ESPTX: FTDI1.2, TX_LINK.1, U$1.8 (TXD)
GND: 5VUSB.GND, C4.1, C5.1, C20.-, C21.-, FTDI1.6, GPIO0.1, JP4.1, JP4.2, JP6.1, JP6.2, MCP1825.2 (GND), Q1.1 (E), Q2.1 (E), R8.2, R14.1, R15.1, R16.1, T9.3, U$1.1 (GND), U$1.2 (GPIO15), X1.1, X2.1
GPIO2: U$1.3 (GPIO2), X7.1
unnamed: R17.1, T1.1 (E), T9.1
unnamed: Q2.2 (B), R16.2, T1.3 (C)
unnamed: Q1.3 (C), R9.1, R14.2, T1.2 (B)
unnamed: Q2.3 (C), R11.1, R15.2, R19.1
unnamed: Q1.2 (B), R18.1
unnamed: GPIO0.2, U$1.4 (GPIO0)
unnamed: R3.1, U$1.9 (REST)
PULSE: C4.2, R8.1, U$1.14 (GPIO12), X7.2

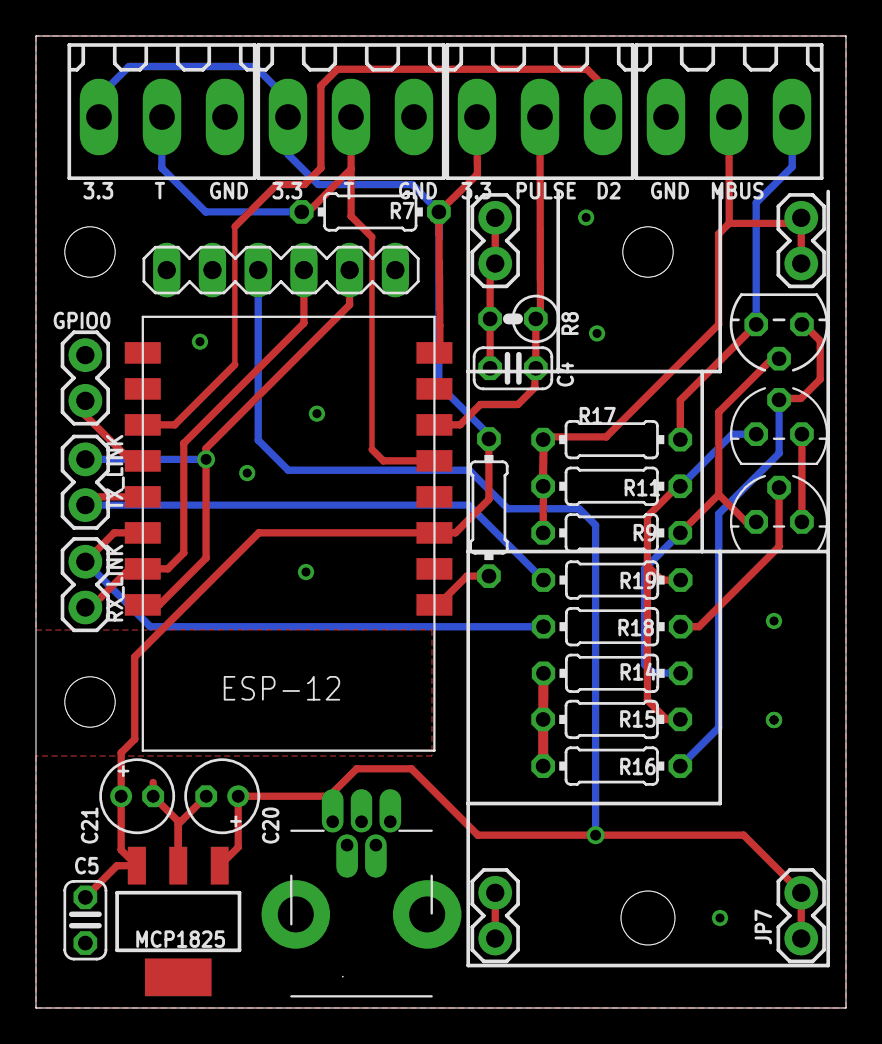
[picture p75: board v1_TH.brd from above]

Board: 2 copper layers, 45.0 x 54.0 mm, 34 parts (1 on the bottom side), 18 nets.

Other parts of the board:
LOGO1: OSHW_LOGO_6MILX0200-NT; OSHW_6X200_NOTEXT

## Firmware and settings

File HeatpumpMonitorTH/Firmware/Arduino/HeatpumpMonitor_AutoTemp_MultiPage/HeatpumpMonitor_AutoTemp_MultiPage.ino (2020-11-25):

// HeatpumpMonitor_AutoTemp
// Licence: GPLv3
//
// Compilation note:

// ---------------------------------------------------------
// Compilation 12th December 2017
// ---------------------------------------------------------
// - Arduino 1.8.5

// - JeeLib https://github.com/jcw/jeelib.git 
//   commit: 026bb6ea843abafff1619ae272a4ea754e0b016e

// - EmonLib https://github.com/openenergymonitor/EmonLib.git 
//   commit: bd0c6ac3bea7f098605841d4124b168e311ac51e

// - CustomSoftwareSerial https://github.com/ledongthuc/CustomSoftwareSerial.git 
//   commit: f97d168a6f29c065fd811b137281d35a40a899e6

// - Elster https://github.com/openenergymonitor/ElsterMeterReader.git 
//   commit: e63aa28868de3096723702a95e25f100e5227aaf

// - OneWire https://github.com/PaulStoffregen/OneWire.git
//   commit: ebc5f7f503b7be9c3772c3c131d86d7080cc77cf

// Beware of errors caused by use of previously compiled libraries
// clear complilation cache in /tmp/ if necessary

#include <avr/wdt.h>

#define FirmwareVersion = 4.0
#define DEBUG 0

#define RFM69_ENABLE 1
#define OEM_EMON_ENABLE 1
#define OEM_EMON_ACAC 1
#define DS18B20_ENABLE 1

#define MBUS_ENABLE 1
#define SONTEX_531 // KAMSTRUP_403 or SONTEX_531, 

#define VFS_ENABLE 0
#define ELSTER_IRDA_ENABLE 1

// EmonTH packet
typedef struct {                                                      // RFM12B RF payload datastructure
  int temp;
  int temp_external;
  int humidity;
  int battery;
  unsigned long pulsecount;
} PayloadTH;
PayloadTH emonth;
// ------------------------------------------------------------------------------------------

#include "elster.h"
#include "EmonLib.h"                   // Include Emon Library:  https://github.com/openenergymonitor/EmonLib
EnergyMonitor ct1;                     // Create an instance
EnergyMonitor ct2;                     // Create an instance

#include <OneWire.h>
#define DS18B20_PIN 19                                                  // Data wire is plugged into port 2 on the Arduino
OneWire ds(DS18B20_PIN);                                           // Setup a oneWire instance to communicate with any OneWire devices (not just Maxim/Dallas temperature ICs)

// Four temperature sensors
byte addr[8]; int uids[4]; double temps[4];
byte numberOfDevices = 0;

// --------------------------------------------------
// Grundfos VFS config
// --------------------------------------------------
const double VFS_maxflow          = 40.0;  // Litres/minute
const double VFS_maxflow_voltage  = 3.5;   // Volts
const double VFS_zeroflow_voltage = 0.25;  // Volts
const double VFS_maxtemp          = 100;   // Celcius
const double VFS_maxtemp_voltage  = 3.5;   // Volts
const double VFS_zerotemp_voltage = 0.5;   // Volts
// --------------------------------------------------
// MBUS
// --------------------------------------------------
byte mbus_address = 100;                   // Set to 0 for auto scan, (test: check timeout 10ms)
int mbus_failures = 0;

#include <CustomSoftwareSerial.h>
CustomSoftwareSerial* customSerial;               // Declare serial

unsigned long last = 0;
unsigned long now = 0;
unsigned long lastwdtreset = 0;

byte bid = 0;
byte bid_end = 255;
byte bid_checksum = 255;
byte len = 0;
byte valid = 0;
byte checksum = 0;

byte bytes[255]; // reduce to 150 if stability problems
// byte dlen = 0;

#define RF_freq RF12_433MHZ                                             // Frequency of RF12B module can be RF12_433MHZ, RF12_868MHZ or RF12_915MHZ. You should use the one matching the module you have.433MHZ, RF12_868MHZ or RF12_915MHZ. You should use the one matching the module you have.
const int nodeID = 1;                                                   // emonTx RFM12B node ID
const int networkGroup = 210;                                           // emonTx RFM12B wireless network group - needs to be same as emonBase and emonGLCD needs to be same as emonBase and emonGLCD

#define RF69_COMPAT 1 // set to 1 to use RFM69CW
#include <JeeLib.h>   // make sure V12 (latest) is used if using RFM69CW
ISR(WDT_vect) { Sleepy::watchdogEvent(); }

// CT Sensors
int OEMct1 = 0;
int OEMct2 = 0;
long joules_CT1 = 0;
long joules_CT2 = 0;
long CT1_Wh = 0;
long CT2_Wh = 0;

// VFS Variables
double VFSflow = 0;
double VFStemp = 0;

// pulseCounting
long pulseCount = 0;
bool firstrun = true;
unsigned long last_reading = 0;

double VFS_Flow_Cal = 0;
double VFS_Temp_Cal = 0;

unsigned long msgnum = 0;

byte page = 1;

// -------------------------------------------------------------------
// Elster meter reading
// -------------------------------------------------------------------
void meter_reading(unsigned long r) {
  pulseCount = r;
}

ElsterA100C meter(meter_reading);

// -------------------------------------------------------------------
// onPulse
// The interrupt routine - runs each time a falling edge of a pulse is detected
// -------------------------------------------------------------------
//
void onPulse() {
  pulseCount++;
}

float getTemp(){
  byte data[2];
  ds.reset();
  ds.select(addr);
  ds.write(0x44);
  delay(750);
  byte present = ds.reset();
  ds.select(addr);
  ds.write(0xBE);
  for (int i = 0; i < 2; i++) data[i] = ds.read();
  byte MSB = data[1];
  byte LSB = data[0];
  float tempRead = ((MSB << 8) | LSB);
  float TemperatureSum = tempRead / 16;
  return TemperatureSum;
}

// -------------------------------------------------------------------
// Decode
// -------------------------------------------------------------------
long decode_1byte_bin(long i) {
  return bytes[i+0];
}

long decode_2byte_bin(long i) {
  return bytes[i+0] + (bytes[i+1]<<8);
}

long decode_4byte_bin(long i) {
  return bytes[i+0] + (bytes[i+1]<<8) + (bytes[i+2]<<16) + (bytes[i+3]<<24);
}

float decode_4byte_bin_to_float(long i)
{
  byte float_data[4];
  float_data[0] = bytes[i+0];
  float_data[1] = bytes[i+1];
  float_data[2] = bytes[i+2];
  float_data[3] = bytes[i+3];
  
  union {
      uint32_t u32;
      float f;
  } data;
  memcpy(&(data.u32), float_data, sizeof(uint32_t));
  return data.f;
}


// -------------------------------------------------------------------
// SETUP
// -------------------------------------------------------------------
void setup() {
  wdt_enable(WDTO_8S);
  
  Serial.begin(115200);
  if (DEBUG) Serial.println(F("Startup"));
  if (RFM69_ENABLE) rf12_initialize(nodeID, RF_freq, networkGroup);

  ct1.voltage(0, 263.241,1.28);
  ct1.current(1, 20.0);
  ct2.voltage(0, 263.241,1.28);
  ct2.current(2, 20.0);
  
  delay(100);
  
  // MBUS
  //                                     (5,19);
  customSerial = new CustomSoftwareSerial(4,5); // rx, tx
  customSerial->begin(4800, CSERIAL_8E1);         // Baud rate: 9600, configuration: CSERIAL_8N1

  wdt_reset();

  if (MBUS_ENABLE) {
    // Broadcast set address to 100
    if (DEBUG) Serial.println(F("Set MBUS Address to 100"));
    mbus_set_address(254,mbus_address);
    delay(1000);
    
    #ifdef SONTEX_531
      // Set sontex data reply page to 3
      mbus_request(100,page);
      delay(1000);
    #endif 
  }
  
  wdt_reset();
  if (DEBUG) Serial.println(F("Attached Interrupt"));
  
  delay(100);
  if (!ELSTER_IRDA_ENABLE) {
    attachInterrupt(1, onPulse, FALLING);
  } else {
    meter.init(1);
  }

  CT1_Wh = 0;
  CT2_Wh = 0;
  wdt_reset();

  VFS_Flow_Cal = ((VFS_maxflow_voltage-VFS_zeroflow_voltage)/VFS_maxflow);
  VFS_Temp_Cal = ((VFS_maxtemp_voltage-VFS_zerotemp_voltage)/VFS_maxtemp);
}

// -------------------------------------------------------------------
// LOOP
// -------------------------------------------------------------------
void loop() {
  now = millis();

  if (ELSTER_IRDA_ENABLE) {
    // Decode the meter stream
    const int byte_data = meter.decode_bit_stream();
    if (byte_data != -1) {
      meter.on_data(byte_data);
    }
  }

  if (RFM69_ENABLE && rf12_recvDone() && rf12_crc == 0 && (rf12_hdr & RF12_HDR_CTL) == 0)
  {
    int node_id = (rf12_hdr & 0x1F);
    byte n = rf12_len;
    if (DEBUG) {
      Serial.print(F("RFM node:"));
      Serial.print(node_id);
      Serial.print(" len:");
      Serial.println(n);
    }

    // If EmonTH on node 23 then decode names fully
    if (node_id == 23 && n == 12)
    {
      emonth = *(PayloadTH*) rf12_data;
      Serial.print(F("THtemp:")); Serial.print(emonth.temp*0.1,1);
      Serial.print(F(",THexttemp:")); Serial.print(emonth.temp_external*0.1,1);
      Serial.print(F(",THhumidity:")); Serial.print(emonth.humidity*0.1,1);
      Serial.print(F(",THbattery:")); Serial.print(emonth.battery*0.1,1);
      Serial.print(F(",THpulse:")); Serial.println(emonth.pulsecount);
    } else {
      // For all other received nodes send as decoded integers: 10_1:1560,10_2:200...
      for (byte i=0; i<n; i+=2)
      {
        int num = ((unsigned char)rf12_data[i+1] << 8 | (unsigned char)rf12_data[i]);
        if (i) Serial.print(",");
        Serial.print(node_id);
        Serial.print("_");
        Serial.print(i);
        Serial.print(":");
        Serial.print(num);
      }
      Serial.println();
    }
  }
  
  if ((now-last)>=9800 || firstrun) {
    wdt_reset();
    
    last = now; firstrun = false;

    // -----------------------------------------------------
    // DS18B20 Temperature sensors
    // -----------------------------------------------------
    byte dsid = 0;
    while(ds.search(addr)) {
  
      unsigned long uid = 0;
      for(byte i=0; i<8; i++) uid += addr[i];
      
      uids[dsid] = uid;
      temps[dsid] = getTemp();
      dsid++;
    }
    numberOfDevices = dsid;

    delay(200);
    
    bool mbus_reply_received = false;
    
    // 1) KAMSTRUP HEAT METER REQUEST:
    if (MBUS_ENABLE) {
      for (int t=0; t<5; t++) {
      
      if (DEBUG) Serial.print(F("mbus_request_data "));
      if (DEBUG) Serial.println(t);
      mbus_request(100,page);

      bid = 0;
      boolean ack = false;
      int mbus_timeout = 500;

      // Set page
      unsigned long timer_start = millis();
      while (!ack && (millis()-timer_start)<mbus_timeout)
      {
        while (customSerial->available()) {
          byte val = (byte) customSerial->read();
          if (bid==0 && val==0xE5) ack = true;
          bid++;
        }
      }

      if (ack) {
        delay(500); // need to wait at least 300ms before sending data request command
        mbus_request_data(mbus_address);
        bid = 0;
        timer_start = millis();
        while (!mbus_reply_received && (millis()-timer_start)<mbus_timeout)
        {
          while (customSerial->available()) {
            byte val = (byte) customSerial->read();
            bytes[bid] = val;
            
            // Catch ACK
            if (bid==0 && val==0xE5) if (DEBUG) Serial.println(F("ACK"));
  
            // Long frame start, reset checksum
            if (bid==0 && val==0x68) {
              valid = 1;
              checksum = 0;
            }
        
            // 2nd byte is the frame length
            if (valid && bid==1) {
              len = val;
              bid_end = len+4+2-1;
              bid_checksum = bid_end-1;
            }
            
            if (valid && bid==2 && val!=len) valid = 0;                 // 3rd byte is also length, check that its the same as 2nd byte
            if (valid && bid==3 && val!=0x68) valid = 0;                // 4th byte is the start byte again
            if (valid && bid>3 && bid<bid_checksum) checksum += val;    // Increment checksum during data portion of frame
        
            if (valid && bid==bid_checksum && val!=checksum) valid = 0; // Validate checksum
            if (valid && bid==bid_end && val==0x16) {                   // Parse frame if still valid
              mbus_reply_received = true;
              bid = 0;
              break;
            }
        
            bid++;
          }
        }
      }
  
      if (mbus_reply_received==false) {
        mbus_failures++;
      } else {
        break;
      }
      if (DEBUG) Serial.println(F("MBUS REPLY END"));

      }
    }
    
    wdt_reset();
    delay(200);
    
    // -----------------------------------------------------
    // Analog read for grundfos vortex flow sensor
    // -----------------------------------------------------
    if (VFS_ENABLE) {
      if (DEBUG) Serial.println(F("VFS READ"));
      
      unsigned long sumA3 = 0;
      unsigned long sumA4 = 0;
      for (int i=0; i<100; i++) {
        sumA3 += analogRead(3);
        sumA4 += analogRead(4);
      }
      int A3 = (int)(sumA3 / 100);
      int A4 = (int)(sumA4 / 100);
      double A3_voltage = 3.3*(A3/1023.0);
      double A4_voltage = 3.3*(A4/1023.0);
      
      VFStemp = (A3_voltage - VFS_zerotemp_voltage) / VFS_Temp_Cal;
      if (VFStemp<0) VFStemp = 0;
  
      VFSflow = (A4_voltage - VFS_zeroflow_voltage) / VFS_Flow_Cal;
      if (VFSflow<0) VFSflow = 0;
      if ((1*A4_voltage)<0.4) VFSflow = 0;  // Minimum voltage to accept flow reading, datasheet recommends 0.5V
      
      // double deltaT = (1.0*emontx.DSflowT-emontx.DSreturnT)*0.01;
      // double VFSheat = ((VFSflow/60.0)*4181.0) * deltaT;
    }
    
    wdt_reset();

    // -----------------------------------------------------
    // CT Sensors
    // -----------------------------------------------------
    if (OEM_EMON_ENABLE)
    {
        if (DEBUG) Serial.println(F("OEM CT READ"));
        // Reading of CT sensors needs to go here for stability
        // need to double check the reason for this.
        for (int i=0; i<10; i++) {
          analogRead(0); analogRead(1); analogRead(2);
        }
        delay(200);
        
        if (OEM_EMON_ACAC) {
          ct1.calcVI(30,2000);
          OEMct1 = ct1.realPower;
          wdt_reset();
          ct2.calcVI(30,2000);
          OEMct2 = ct2.realPower;
          wdt_reset();
        } else {
          OEMct1 = 230 * ct1.calcIrms(1480);
          wdt_reset();
          OEMct2 = 230 * ct2.calcIrms(1480);
          wdt_reset();
        }
    
        // Accumulating Watt hours
        int interval = millis() - last_reading;
        last_reading = millis();
    
        if (ct1.realPower > 0 && interval>0) {
          long jouleinc = ct1.realPower * interval *0.001;
          joules_CT1 += jouleinc;
          CT1_Wh += joules_CT1 / 3600;
          joules_CT1 = joules_CT1 % 3600;
        }
    
        if (ct2.realPower > 0 && interval>0) {
          long jouleinc = ct2.realPower * interval *0.001;
          joules_CT2 += jouleinc;
          CT2_Wh += joules_CT2 / 3600;
          joules_CT2 = joules_CT2 % 3600;
        }
        wdt_reset();

        if (DEBUG) Serial.println(F("OEM CT READ END"));
    } else {
      delay(500);
      wdt_reset();
    }

    msgnum++;
    Serial.print(F("Msg:")); Serial.print(msgnum);
    if (OEM_EMON_ENABLE)
    {
        Serial.print(F(",Vrms:")); Serial.print(ct1.Vrms);
        Serial.print(F(",OEMct1:")); Serial.print(OEMct1);
        Serial.print(F(",OEMct2:")); Serial.print(OEMct2);
        Serial.print(F(",OEMct1Wh:")); Serial.print(CT1_Wh);
        Serial.print(F(",OEMct2Wh:")); Serial.print(CT2_Wh);
        Serial.print(F(",OEMct1PF:")); Serial.print(ct1.powerFactor,4);
    }
    
    if (VFS_ENABLE) {
      Serial.print(F(",VFStemp:")); Serial.print(VFStemp,2);
      Serial.print(F(",VFSflow:")); Serial.print(VFSflow,2);
    }

    if (DS18B20_ENABLE) { 
        for(int i=0;i<numberOfDevices; i++)
        {
          if (temps[i]>-50 && temps[i]<80) {
            Serial.print(F(",T"));
            Serial.print(uids[i]);
            Serial.print(F(":"));
            Serial.print(temps[i]);
          }
        }
    }

    if (MBUS_ENABLE && mbus_reply_received) {

      #ifdef KAMSTRUP_402
        Serial.print(F(",KSkWh:")); 
        Serial.print(decode_4byte_bin(27));
        // volume decode_4byte_bin(33)
        // ontime decode_4byte_bin(39)
        Serial.print(F(",KSflowT:")); 
        Serial.print(decode_4byte_bin(45)*0.01,2);
        Serial.print(F(",KSreturnT:"));
        Serial.print(decode_4byte_bin(51)*0.01,2);
        Serial.print(F(",KSdeltaT:")); 
        Serial.print(decode_4byte_bin(57)*0.01,2);
        Serial.print(F(",KSheat:")); 
        Serial.print(decode_4byte_bin(63)*100);
        // maxpower decode_4byte_bin(70)
        Serial.print(F(",KSflowrate:"));
        Serial.print(decode_4byte_bin(75));
        // maxflow decode_4byte_bin(81)
      #endif
      
      #ifdef KAMSTRUP_403
        // Locations set here correspond to location as described in datasheet minus 9 bytes
        byte offset = 9;
        
        Serial.print(F(",KSkWh:"));    
        Serial.print(decode_4byte_bin(21));
        // Cooling E3 decode_4byte_bin(30-offset)
        // Energy E8 decode_4byte_bin(37-offset)
        // Energy E9 decode_4byte_bin(44-offset)
        // Volume decode_4byte_bin(50-9)
        // PulseA decode_4byte_bin(57-offset)
        // PulseB decode_4byte_bin(65-offset)
        // ontime decode_4byte_bin(71-offset)
        Serial.print(F(",KSflowT:")); 
        Serial.print(decode_2byte_bin(83-offset));
        Serial.print(F(",KSreturnT:"));
        Serial.print(decode_2byte_bin(87-offset));
        Serial.print(F(",KSdeltaT:")); 
        Serial.print(decode_2byte_bin(91-offset));
        Serial.print(F(",KSheat:"));
        Serial.print(decode_4byte_bin(95-offset));
        Serial.print(F(",KSflowrate:"));
        Serial.print(decode_4byte_bin(107-offset));
      #endif
    
      #ifdef SONTEX_531

        if (page==1) {
          Serial.print(F(",SNXstatus:"));
          Serial.print(decode_1byte_bin(16));
          Serial.print(F(",SNXerrors:"));
          Serial.print(decode_2byte_bin(22));
          Serial.print(F(",SNXenergy:"));
          Serial.print(decode_4byte_bin(38));
          Serial.print(F(",SNXvolume:"));
          Serial.print(decode_4byte_bin(44));
          page = 3;
        } else if (page==3) {
          Serial.print(F(",SNXflowT:"));
          Serial.print(decode_4byte_bin_to_float(21));
          Serial.print(F(",SNXreturnT:"));
          Serial.print(decode_4byte_bin_to_float(27));
          Serial.print(F(",SNXflowrate:"));
          Serial.print(decode_4byte_bin_to_float(33));
          Serial.print(F(",SNXheat:"));
          Serial.print(decode_4byte_bin_to_float(39));
          page = 1;
        } 
      #endif
    }

    if (pulseCount>0) {
      Serial.print(F(",PulseIRDA:")); Serial.print(pulseCount);
    }
    Serial.println();
    delay(100);

    wdt_reset();
  }

  if ((millis()-lastwdtreset)>1000) {
    lastwdtreset = millis();
    wdt_reset();
  }
}

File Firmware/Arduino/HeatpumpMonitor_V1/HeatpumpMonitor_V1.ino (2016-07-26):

// Heatpump monitor example with:
// MBUS meter reader for kampstrup multical 402
// Grundfos vortex flow sensor on analog 0 and 1
// 2x DS18B20 flow + return sensors
// All sending via RFM12/69.
// Licence: GPLv3
#include <avr/wdt.h>  

#define FirmwareVersion = 2.0
#define DEBUG 0
#define emonTxV3 1
#define RFM69_ENABLE 0
#define SEND_RFM69_RX_DATA 0
#define SEND_RFM69_TX_DATA 0

#define OEM_EMON_ENABLE 1
#define KAMSTRUP_ENABLE 1
#define VFS_ENABLE 0
#define ELSTER_IRDA_ENABLE 1
#define MBUS_ENABLE 1



// ------------------------------------------------------------------------------------------
// Datastructure for data sent via RFM12 or RFM69 radio module - alternative path to ESP WIFI
// ------------------------------------------------------------------------------------------
/*

Copy this node decoder to your emonhub.conf file to decode the heatpump monitor rfm69 data packet:

[[1]]
    nodename = Heatpump Monitor
    firmware = v0.1
    hardware = v0.1
    [[[rx]]]
       names = OEMct1,OEMct2,DSflowT,DSreturnT,DSairoutT,DSairinT,VFSflowT,VFSflowrate,VFSheat,KSflowT,KSreturnT,KSdeltaT,KSflowrate,KSheat,KSkWh,pulseCount
       datacodes = h,h,h,h,h,h,h,h,h,h,h,h,h,h,L,L
       scales = 1,1,0.01,0.01,0.01,0.01,0.01,1,1,0.01,0.01,0.01,1,1,1,1
       units = W,W,C,C,C,C,C,L/h,W,C,C,K,L/h,W,kWh,Wh
*/

// RFM Packet structure
typedef struct {
  // Integer datatypes:
    // OpenEnergyMonitor CTs
      int OEMct1;
      int OEMct2;
    // DS18B20 temperatures:
      int DSflowT;
      int DSreturnT;
      int DSairoutT;
      int DSairinT;
    // Grundfos VFS flow meter
      int VFSflowT;
      int VFSflowrate;
      int VFSheat;
    // Kamstrup heat meter
      int KSflowT; 
      int KSreturnT;
      int KSdeltaT;
      int KSflowrate;
      int KSheat;
    // Long data types:
      long KSkWh;
      long pulseCount;
      // long KSpulse;
} PayloadTX;         // neat way of packaging data for RF comms
PayloadTX emontx;
// ------------------------------------------------------------------------------------------
// ------------------------------------------------------------------------------------------

// EmonTH packet
typedef struct {                                                      // RFM12B RF payload datastructure
  int temp;
  int temp_external;
  int humidity;    
  int battery;
  unsigned long pulsecount;                                             
} PayloadTH;
PayloadTH emonth;
// ------------------------------------------------------------------------------------------

#include "elster.h"
#include "EmonLib.h"                   // Include Emon Library:  https://github.com/openenergymonitor/EmonLib
EnergyMonitor ct1;                     // Create an instance
EnergyMonitor ct2;                     // Create an instance

#include <OneWire.h>
#include <DallasTemperature.h>

#define ONE_WIRE_BUS 19                                                  // Data wire is plugged into port 2 on the Arduino
OneWire oneWire(ONE_WIRE_BUS);                                          // Setup a oneWire instance to communicate with any OneWire devices (not just Maxim/Dallas temperature ICs)
DallasTemperature sensors(&oneWire);                                    // Pass our oneWire reference to Dallas Temperature.
DeviceAddress sensor;

// --------------------------------------------------
// Grundfos VFS config
// --------------------------------------------------
double VFS_maxflow          = 40.0;  // Litres/minute
double VFS_maxflow_voltage  = 3.5;   // Volts
double VFS_zeroflow_voltage = 0.25;  // Volts
double VFS_maxtemp          = 100;   // Celcius
double VFS_maxtemp_voltage  = 3.5;   // Volts
double VFS_zerotemp_voltage = 0.5;   // Volts
// --------------------------------------------------
// Kamstrup MBUS config
// --------------------------------------------------
byte kamstrup_mbus_address = 0;                  // Set to 0 for auto scan, (test: check timeout 10ms)
int kamstrup_failures = 0;
#include <CustomSoftwareSerial.h>
CustomSoftwareSerial* customSerial;               // Declare serial

unsigned long last = 0;
unsigned long now = 0;
unsigned long lastwdtreset = 0;

int bid = 0;
byte bytes[81];
byte dlen = 0;

#define RF_freq RF12_433MHZ                                             // Frequency of RF12B module can be RF12_433MHZ, RF12_868MHZ or RF12_915MHZ. You should use the one matching the module you have.433MHZ, RF12_868MHZ or RF12_915MHZ. You should use the one matching the module you have.
const int nodeID = 1;                                                   // emonTx RFM12B node ID
const int networkGroup = 210;                                           // emonTx RFM12B wireless network group - needs to be same as emonBase and emonGLCD needs to be same as emonBase and emonGLCD

#define RF69_COMPAT 1 // set to 1 to use RFM69CW 
#include <JeeLib.h>   // make sure V12 (latest) is used if using RFM69CW
ISR(WDT_vect) { Sleepy::watchdogEvent(); }

// pulseCounting
long pulseCount = 0;
//unsigned long pulseTime,lastTime; // Used to measure time between pulses
//double power;
//int ppwh = 1;                     // pulses per watt hour - found or set on the meter.

int joules_CT1 = 0;
int joules_CT2 = 0;
unsigned long CT1_Wh = 0;
unsigned long CT2_Wh = 0;

bool firstrun = true;
unsigned long last_reading = 0;

double VFS_Flow_Cal = 0;
double VFS_Temp_Cal = 0;

unsigned long msgnum = 0;

ElsterA100C meter(meter_reading);

void setup() {
  wdt_enable(WDTO_8S);
  
  Serial.begin(115200);
  if (DEBUG) Serial.println("Startup");
  if (RFM69_ENABLE) rf12_initialize(nodeID, RF_freq, networkGroup);
  sensors.begin();

  ct1.voltage(0, 262.0, 1.7);
  ct1.current(1, 20.0);
  ct2.voltage(0, 262.0, 1.7);
  ct2.current(2, 20.0);
  
  delay(100);
  
  // MBUS
  customSerial = new CustomSoftwareSerial(4, 5); // rx, tx
  customSerial->begin(2400, CSERIAL_8E1);         // Baud rate: 9600, configuration: CSERIAL_8N1

  wdt_reset();

  if (KAMSTRUP_ENABLE) 
  {
    mbus_normalize();
    if (kamstrup_mbus_address==0) {
      if (DEBUG) Serial.println("Scanning MBUS ");
      kamstrup_mbus_address = mbus_scan();
      if (kamstrup_mbus_address) {
        if (DEBUG) Serial.print("Meter found, address: ");
        if (DEBUG) Serial.println(kamstrup_mbus_address);
      } else {
        if (DEBUG) Serial.println("No MBUS meter found");
      }
    }
  }
  wdt_reset();
  if (DEBUG) Serial.println("Attached Interrupt");
  
  delay(100);
  if (!ELSTER_IRDA_ENABLE) {  
    attachInterrupt(1, onPulse, FALLING);
  } else {
    meter.init(1);
  }

  CT1_Wh = 0;
  CT2_Wh = 0;
  wdt_reset();

  VFS_Flow_Cal = ((VFS_maxflow_voltage-VFS_zeroflow_voltage)/VFS_maxflow);
  VFS_Temp_Cal = ((VFS_maxtemp_voltage-VFS_zerotemp_voltage)/VFS_maxtemp);
}

void meter_reading(unsigned long r)
{
  pulseCount = r;
}
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

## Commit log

2016-02-10 Open source heatpump monitor arduino firmware, hardware and web dashboard
    [Fascia.brd, Fascia.dxf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]
2016-04-07 v2 of heatpump monitor PCB
    [HeatpumpMonitor.brd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]
2016-05-26 reset watchdog while scanning for mbus devices
    [mbus.ino]
2016-05-26 Link to EmonESP and heatpump blog posts
2016-06-07 More stable calculation of VFS flow and temperature
2016-06-22 Example one off prototype costing for heatpump monitor
    [BOM&Costing_oneoff_prototype.ods]
2016-06-22 BOM + costing example html
2016-06-22 Update and rename BOM&Costing_oneoff_prototype.html to BOM&Costing_oneoff_prototype.md
2016-06-23 correction to PCB price
    [BOM&Costing_oneoff_prototype.ods]
2016-06-24 Build notes
    [BOM&Costing_oneoff_prototype.ods]
2016-06-24 resistor color codes
2016-06-24 Heatpump monitor and Energy Monitor build
2016-06-25 Costing examples
    [BOM&Costing_1x.ods, BOM&Costing_20x.ods]
2016-06-26 v2 schematic and board image files
2016-06-26 kamstrup heat meter image
2016-06-26 flow meter images
2016-06-27 updated BOM image and costings
    [BOM&Costing_1x.ods, BOM&Costing_20x.ods]
2016-06-30 v2 of fascia
    [Fascia.brd, Fascia2.dxf]
2016-06-30 line thickness
    [Fascia2.dxf]
2016-07-09 Tiled Fascia's for laser cutter
    [Fascia.brd, TiledFascia.dxf]
2016-07-09 fixed watt hour accumulator calc and addition of msg counter to heatpump monitor code
    [HeatpumpMonitor_V1.ino]
2016-07-11 removed heatpump dashboard replaced with emoncms energy, modification to name of Pulse/IRDA input
    [HeatpumpMonitor_V1.ino]
2016-07-19 Selecting the right heat meter
2016-07-21 All arduino libraries needed for compilation
2016-08-18 v3 of heatpump monitor design - voltage regulators
    [HeatpumpMonitor.brd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]
2016-08-28 Updated v3 board and shematic images
2016-09-22 move msg print to after emon ct1 sample
2016-10-06 Moved the switched lables for R5 and R6 to their correct resistors on the BRD.
2016-10-21 Added tactile switch for reset button
    [HeatpumpMonitor.brd, HeatpumpMonitor.sch]
2016-11-23 minor bug fixes for kamstrup 403 support
    [src.ino]
2016-11-24 Tidying up and track alignments
    [HeatpumpMonitor.brd, HeatpumpMonitor.sch]
2016-11-24 gerbers for v4
    [HeatpumpMonitor.brd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]
2016-11-30 New firmware with automatic DS18B20 sensor address scanning
2016-12-12 fix missing new line
    [src.ino]
2016-12-12 - filter temperature below -50 and above 80 removing error modes -127 and 85 - option for CT only mode
    [HeatpumpMonitor_AutoTemp.ino, src.ino]
2017-03-01 updated sensors diagram
2017-03-01 updated images for heatpump monitor build
2017-03-01 updated heatpump monitor v4 image
2017-03-01 updated note on SMT voltage regulator
2017-03-01 updated BOM 1x
    [BOM&Costing_1x.ods]
2017-03-01 update to include note about DS18B20 temperature sensors
2017-03-02 v4 schematic and board file readme
2017-03-02 mbus kit bom
2017-03-02 updated BOM and costing
    [BOM&Costing_1x.ods, BOM&Costing_20x.ods]
2017-03-02 enclosure images
2017-06-13 Heatpump Monitor sketch to run on EmonTx v3 to use with WIFI module
2017-07-29 Correction: data is not sent via RFM69
    Correction: data is not sent via RFM69
    [HeatpumpMonitor_AutoTemp.ino]
2017-12-07 updated firmware to support sontex heat meter
2017-12-11 fix ds18b20 temp bug
    [HeatpumpMonitor_AutoTemp.ino]
2017-12-11 reorder ds18b20 temperature sensor read
2017-12-11 cut down example for sontex meter
2017-12-12 set correct delays enable OEM CT monitoring as default
    [HeatpumpMonitor_AutoTemp.ino, mbus.ino]
2017-12-17 change default baud rate to 2400 and allow for maximum frame
2019-01-10 fix sontex 531 support
    [HeatpumpMonitor_AutoTemp_MultiPage.ino]
2020-09-03 new design: WiFi MBUS Reader
    [WiFi_MBUS_Reader.brd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]
2020-11-25 new MBUS reader hardware designs
    [USB_to_MBUS.brd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]
2020-11-25 picture of through-hole board and basic reader firmware for ESP8266
2021-01-26 v1 of heatpump controller board
    [hpctrl.brd, hpctrl.sch]
2021-07-16 heat pump monitor Pi base board and latest USB to MBUS reader
    [USB_to_MBUS.brd, USB_to_MBUS.sch, hpmon_pi_baseboard.brd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]
2021-08-15 Organise by hardware designs
    [BOM&Costing_1x.ods, BOM&Costing_20x.ods, Fascia.brd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]
2021-09-13 updated pressure loss chart
2021-09-13 pressure loss spread sheet
    [heat_meter_pressure_drops.ods]
2021-09-13 heat meter images

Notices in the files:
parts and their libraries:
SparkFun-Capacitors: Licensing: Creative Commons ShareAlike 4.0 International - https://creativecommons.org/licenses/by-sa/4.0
